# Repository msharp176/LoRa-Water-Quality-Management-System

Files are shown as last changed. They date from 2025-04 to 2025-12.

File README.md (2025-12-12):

# LoRa Water Quality Management System
### By Cole Hadley, Patricio Benitez Palermo, and Matthew Sharp
#### Penn State Harrisburg Senior Electrical Engineering Capstone Design Course, Fall 2025

# Project Repository Overview

This repository contains all hardware, firmware, software, and documentation associated with the gateway, sensor node, and supporting prototypes used throughout this project. The directory structure is organized to clearly separate production-ready components from prototyping artifacts, while providing comprehensive traceability for PCB designs, firmware, simulations, and supporting tools.

## Directory Structure

### **Gateway**

Code and PCB designs for the system gateway.

* **Dashboard**
  Python code for the gateway dashboard and system monitoring utilities.

* **LoRa Receiver**
  PCB design files, RP2350 firmware, and a console-logging Python script for a dedicated LoRa receiver module.

* **Neural Network**
  Code and related resources for the neural network implementation used in the system.

---

### **Prototyping and Testing**

Various PCB designs and test code used during early prototyping and validation phases.

---

### **Sensor Node**

Master directory for the final Sensor Node design, including PCB files, firmware, documentation, and test artifacts.

#### **Code**

Production firmware implementation for the Sensor Node.

* **Bin**
  Final binary executable for the RP2350 microcontroller (`.uf2`).

* **Lib**
  Custom-implemented C drivers for the sensor node.

  * **sx126x**: Semtech-provided driver files with custom HAL and radio ISR implementations.

* **Stash**
  Top-level gateway/node firmware source files. These are not included in the build unless a file is manually integrated into `main.c`.

* **Sys_Utils**
  Abstracted system-level modules, including LoRa communications, RDT3.0 implementation, and other project-specific utilities.

* **Tests**
  Code used to validate custom drivers and subsystem behaviors.

#### **Docs**

Datasheets, PCB design write-ups, and annotated Bill-of-Materials (BOM) for the final Sensor Node PCB.

#### **PCB Layout**

Complete KiCAD implementation of the sensor node PCB.

#### **Simulation**

Simulation files and output results for the analyses performed during development.

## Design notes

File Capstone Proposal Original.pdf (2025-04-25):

i

LoRa Water Quality Management System

Cole Hadley, Patricio Palermo, Matthew Sharp

Instructor: Dr. Kiana Karami

Technical Advisors: Dr. Sedig Agili and Dr. Aldo Morales

Technical Report Submitted in Partial Fulfillment of the Senior Electrical Capstone

Proposal Course at Penn State Harrisburg

EE 405, Section 1

Spring Semester, 2025

Submitted April 25, 2025

ii

Abstract

To provide high-quality water to their customers, water utility companies must continuously monitor several factors which contribute to the overall health, safety, and taste of drinking water. In this paper, a proposal for a water quality management system which leverages wireless communication technology to produce a distributed network of low-power, battery-operated sensors is presented. The network of sensors communicates real-time turbidity, pH, and temperature data to a central gateway, which identifies anomalous readings and makes predictions about the future water quality of the system using an artificial neural network. The central gateway also relays incoming water quality data to a visual dashboard, providing technicians and engineers with valuable water quality data at a glance.

Communication between the network of sensor nodes and central gateway is facilitated by LoRa wireless technology, whose name is derived from “long range.” LoRa has significantly reduced power consumption compared to traditional wireless technologies, such as cellular, therefore making it well-suited for long-distance, low bandwidth data communication applications such as water quality monitoring.

iii

Acknowledgements

We extend our gratitude to our capstone project technical advisors, Dr. Aldo Morales and Dr. Sedig Agili for contributing their expertise to our project. Both of our advisors were crucial for the development and exploration of sensor interfacing, wireless communication, and artificial neural networks. Additionally, we would like to thank Dr. Yen-Chih Chen and
J. Mitchell Spear for their consultation on the water treatment process and helping us understand how water quality is measured in the context of a water utility company. Furthermore, we would like to recognize the technicians and engineers of the Reading, Muhlenberg, and Maiden Creek water authorities for taking the time to complete our survey, helping us better understand the challenges that water utilities face when evaluating water quality. Finally, we would like to thank Dr. Kiana Karami for her valuable feedback and guidance during the proposal phase of the senior electrical engineering capstone course.

iv

Table of Contents

v

vi

Table of Figures

Figure 3: Block Diagram of Proposed LoRa-Based Water Quality Monitoring System [16]....9

Figure 13: Work Breakdown Structure for the LoRa Water Quality Management System .. 36

vii

Table of Tables

Table 1: Customer Primary Requirements | 15
Table 2: System Capabilities Subcategory Breakdown | 15
Table 3: System Feedback & Notifications Subcategory Breakdown | 16
Table 4: Ease of Use Subcategory Breakdown | 16
Table 5: Deployment Flexibility Subcategory Breakdown | 17

Table 6: Approved Methodologies and Relevant Standards for pH and Turbidity Analysis.19

Table 7: Engineering Requirements for the LoRa Water Quality Management System ........ 20

Table 8: pH Sensor Function Table | 26
Table 9: Turbidity Sensor Function Table | 26
Table 10: Temperature Sensor Function Table | 26
Table 11: Raw Data Formatting and Preprocessing Function Table | 27
Table 12: Data Collection Wireless Transceiver Function Table | 27
Table 13: Data Processing Wireless Transceiver Function Table | 28
Table 14: Final Data Processing Function Table | 28
Table 15: Anomaly Detection Function Table | 28
Table 16: Predictive Neural Network Function Table | 29
Table 17: Decision-making Logic Function Table | 29
Table 18: Dashboard Generation Function Table | 30
Table 19: Alert Generation Function Table | 30
Table 20: Gantt Chart | 38
Table 21: Engineering Labor Cost of Project | 39
Table 22: Parts Cost of Project | 40
Table 23: Total Cost of Project | 40

Table of Equations

Equation 1: Water Quality Index (WQI) | 11
Equation 2: Turbidity Sensor Output Voltage | 31
Equation 3: Instrumentation Amplifier Output Voltage | 32

1. Introduction
1.1. Introduction

To consistently deliver high-quality water to their customers, water utilities must monitor

the quality of their water in every part of their system. This often requires labor-intensive

manual testing, or sensors which provide this data in real-time. These systems often

require a direct wired connection between each sensor and a Programmable Logic

Controller (PLC), making retrofitting older plants with them more difficult. Though

wireless options for these sensors are available, they communicate over cellular networks,

requiring substantial power dissipation thus limiting battery life. Using LoRa, a wireless

communication technology whose name is derived from “Long Range,” water quality

sensors can be implemented with a significantly reduced power consumption and

communicate over long distances without needing access to cellular signal. Our LoRa-based

Water Quality Management System will implement a network of sensors which

communicate real-time water quality data back to a central gateway. The gateway will

integrate this data with AI-driven analytics, and relay system-wide information to

technicians and engineers through a visual dashboard and real-time alerts, enabling water

authorities to gain valuable insights into the status of their water systems with reduced

setup time and impact on legacy operations.

1.2. Technical History

Monitoring water quality has evolved from simple manual sampling methods to more

polished, real-time, and automated technology. This is a result of the increased need for

accurate, efficient, and comprehensive water quality analysis to ensure the safety of public

health and the environment. As demand for clean water increases due to population

growth, industrialization, and climate change, the need for innovation in water quality

monitoring systems has become more critical.

1.2.1. Early Developments in Water Quality Monitoring

The quality of water has been monitored since ancient history with the Greeks and Romans

using visual observation of clarity and building structures such as aqueducts to supply

clear water. The ancient cultures appreciated the value of clean water but were only able to

use primitive observation methods [1]. After Antonie van Leeuwenhoek discovered of the

microscope in the 17th century, scientists could now examine waterborne organisms for

the first time, paving the way for a better understanding of possible pollutants [2].

With the Industrial Revolution in the 19th century, there was a speeding up of

industrialization that resulted in serious water pollution, and hence the development of

chemical analysis techniques to measure pollutants like dissolved solids [3]. These

advances paved the way for more systematic water quality monitoring. By the mid-20th

century, techniques such as the Most Probable Number (MPN) method emerged, which

allowed for the estimation of bacterial populations by serial dilution and observation of

growth in culture tubes [4]. This was soon followed by the membrane filtration method,

which counted bacteria directly on filter membranes, increasing the efficiency and

precision of measurements of bacterial contamination [5].

1.2.2. Legislative Milestones: Clean Water Act and Safe Drinking Water Act

Two landmark legislations in the United States played a crucial role in strengthening water

quality monitoring. The Clean Water Act (CWA) of 1972 enacted broad-spectrum

regulations to avert water pollution, to safeguard the physical, chemical, and biological

integrity of the waters of the United States [6]. It required monitoring of industrial waste

and sewage treatment facilities while promoting the development of standard methods for

measuring water quality. CWA also focused on the restoration of polluted waters, which led

to the overall implementation of monitoring practices.

Similarly, the Safe Drinking Water Act of 1974 directly focused on drinking water quality,

mandating that water suppliers meet health-based standards for contaminants [7]. The act initiated more testing demands on the public water systems regarding microbial, chemical, and radiological parameters. Both acts together established a legislative climate in which

water quality monitoring became a regulated and organized endeavor in the United States.

1.2.3. Technological Advancements in the 1970s and 1980s

The 1970s and 1980s witnessed the use of advanced analytical instrumentation in water

quality analysis. The most notable development during this time was the release of the

computerized Gas Chromatography-Mass Spectrometry (GC/MS). This device enabled the

precise identification and quantification of organic pollutants in water samples, a major

leap in analysis [8]. The United States Environmental Protection Agency (EPA) implemented GC/MS as a standard analytical procedure in the determination of

environmental pollutants, and this saw more accurate and detailed water quality

determinations. The technology, apart from identifying pollutants more, also enabled the

setting of regulatory standards of water quality for the entire country.

During this time, the Supervisory Control and Data Acquisition (SCADA) system

deployment began to transform water quality monitoring. SCADA systems enable remote

monitoring and management of water treatment processes with real-time data acquisition

and process control [9]. SCADA systems enabled utilities to detect issues such as

equipment failures or contamination events more quickly, improving operational efficiency

and system reliability. Early SCADA systems often relied on wired connections for

communication, which were effective for centralized facilities but presented challenges in

monitoring widely distributed or remote locations. While these systems were capable of

remote monitoring, reliance on wired infrastructure could limit scalability and increase

costs. Over time, advancements in wireless communication technologies, such as radio,

cellular, and satellite networks, have significantly enhanced SCADA's ability to monitor and

control remote assets, reducing infrastructure costs and improving flexibility.

1.2.4. Emergence of Wireless Sensor Networks in the 1990s and 2000s

In the 1990s and early 2000s, the emergence of wireless sensor networks (WSNs) was a

groundbreaking environmental monitoring approach. WSNs are made up of widely

distributed sensors that wirelessly transmit data on various environmental factors,

including water quality. This made it ideal for tracking water quality in vast, remote areas

where traditional wired systems would be impractical and costly. [10]. These systems were

very effective for surveillance of large bodies of water, for instance, rivers, lakes, and

reservoirs, where older methods were not very practical.

1.2.5. Advancements in Low-Power, Long-Range Communication Technologies

Over the past few years, there has been an evolution of low-power, wide-area network

(LPWAN) technologies that have overcome most of the shortcomings of previous WSNs.

One such LPWAN technology is LoRa, which facilitates long-distance communication with

minimal power usage. LoRa technology is particularly well-suited for deploying sensor

networks in remote areas, allowing devices to operate efficiently on battery power. This

makes LoRa a cost-effective solution for monitoring water quality in areas with limited

access to traditional infrastructure.

The use of LoRa technology for water quality monitoring has simplified it to develop

affordable and scalable solutions. The technology can send data in real-time across vast

geographical areas without the need for heavy infrastructure, hence, why it is finding the

interest of water management authorities [11]. These are technologies that will improve

the measurement of water quality to augment post-treatment monitoring and confirm

water for safe consumption before intake. Figure 1 illustrates the architecture of a LoRa-

based water quality monitoring system.

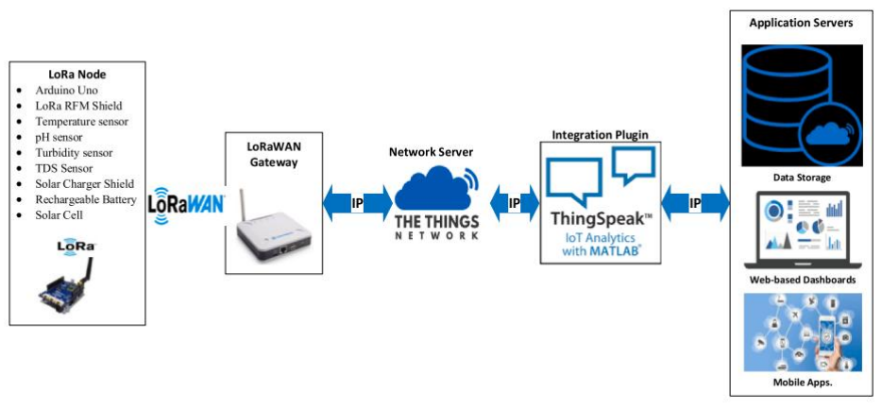
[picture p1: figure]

Figure 1: Example LoRa Water Quality Monitoring Architecture [11]

1.2.6. Current State and Gaps in Water Quality Monitoring

Today, water quality monitoring systems have become increasingly sophisticated,

incorporating Internet of Things (IoT) devices, advanced sensors, and real-time data

analytics. These systems can continuously monitor various parameters such as pH,

turbidity, dissolved oxygen, and the presence of specific contaminants [12]. Data collected

is transmitted to centralized platforms where it is analyzed to inform decision-making

processes. Moreover, AI-driven analytics are beginning to play a critical role in anomaly

detection and predictive maintenance, helping to identify issues before they escalate.

Despite these advancements, several gaps and challenges persist:

1. Integration with Legacy Systems: Many existing water treatment facilities operate

with legacy SCADA systems that rely on hard-wired connections. Integrating

modern wireless sensor networks with these systems can be complex and costly,

often requiring significant retrofitting. Overcoming this challenge requires

innovative solutions that ensure compatibility without extensive infrastructure

overhauls.

2. Power Efficiency: Many wireless communication methods, such as cellular, Wi-Fi,

and Bluetooth, consume a significant amount of power to maintain connectivity.

This high-power demand drastically reduces battery life, requiring frequent battery

replacements or consistent access to electrical infrastructure. In remote or off-grid

environments, these limitations can make long-term sensor deployment impractical.

For battery-powered or solar-powered systems, power efficiency is critical to

ensure sustained operation without constant maintenance.

3. Data Management and Analytics: Traditional SCADA systems often overwhelm

operators with large volumes of data, much of it lacking context or immediate relevance. Without clear interpretation, this data becomes difficult to act on and

offers little practical value. Effective systems should prioritize delivering focused,

actionable insights over raw data streams.

4. Ensuring Consistent Data Transmission: Existing technologies such as cellular and

Wi-Fi rely on network coverage, which can be unreliable or nonexistent in remote or

rural areas. This dependence limits their effectiveness for continuous monitoring in

hard-to-reach locations. For applications like water quality monitoring, where

consistent data transmission is critical, these coverage gaps pose a serious challenge

and can compromise real-time visibility and response.

5. Cost Constraints: Budget limitations, especially in smaller towns or developing

regions, can delay the adoption of advanced monitoring technologies. Addressing

this requires developing scalable solutions that balance performance with

affordability, enabling broader access to clean water monitoring.

Water quality monitoring has evolved from basic visual inspections to advanced real-time

systems, driven by the need for accuracy and efficiency. Innovations like SCADA, wireless

sensor networks, and LoRa technology have improved monitoring capabilities, enabling

cost-effective and scalable solutions. However, challenges remain in integrating modern systems with legacy infrastructure, managing data, ensuring power efficiency, and

addressing cost constraints. Continued advancements and collaboration are essential to overcoming these barriers and ensuring reliable, real-time water quality monitoring for the

future.

1.3. Review of Technical Literature
1.3.1. IoT in Modern Water Utilities

IoT-based water management systems have become ubiquitous in modern water utilities,

primarily with the advent of smart metering. These devices communicate real-time

individual usage data back to utility-owned software, where that data can be used for

applications such as billing or usage monitoring system-wide. One such IoT device, the

Honeywell Merlin NB-IoT, is shown below in Fig. 1.

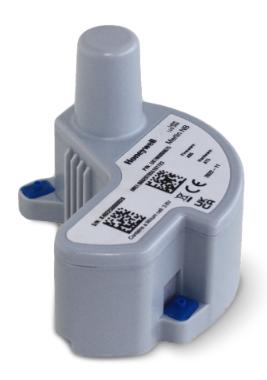
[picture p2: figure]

Figure 2: Honeywell Merlin NB-IoT Clip-On Water Meter [13]

This Honeywell IoT Device clips onto existing water meters and transmits real-time water

usage data over Narrowband IoT (NB-IoT), a subset of low power wide-area networks

(LPWAN) that utilizes existing 3G and 4G cellular infrastructure and frequency bands [13],

[14]. Using a low-power communication technology such as NB-IoT allows this device to have a battery life of up to 15 years, making it advantageous over traditional cellular

communications, which is quite power-hungry [13], [15].

1.3.2. Applications of LoRa in IoT Water Systems

The low power consumption advantages of NB-IoT systems can also be found in LoRa-

based communications systems. Compared to the NB-IoT communication technology used

in the Honeywell Clip-On NB-IoT smart meter, LoRa technology enables IoT

communications at an even lower power consumption. A typical NB-IoT node has a peak

current draw of 100-320 mA and a sleep current of 5μA, while a comparable LoRa node has a peak current and sleep current of 32mA and 1μA, respectively. LoRa obtains these

increased power savings at the cost of a significantly reduced data rate, with a maximum

speed of just 20% of an NB-IoT-based system, although with a much higher immunity to

interference [14].

Thus, the power-saving capabilities of LoRa are quite attractive for use in IoT applications

where battery life is of greater concern than the data rate, such as in water quality

monitoring applications. One such LoRa-based water quality monitoring system was

proposed during the 3rd International Conference on Advancement in Electronics and

Communication Engineering in 2023 [16]. The system utilizes a series of sensor nodes that

communicate with a central gateway which processes the raw data and communicates with

an external microcontroller unit to upload the information to an IoT cloud server over Wi-

Fi. A block diagram of the system is shown below in Fig. 2.

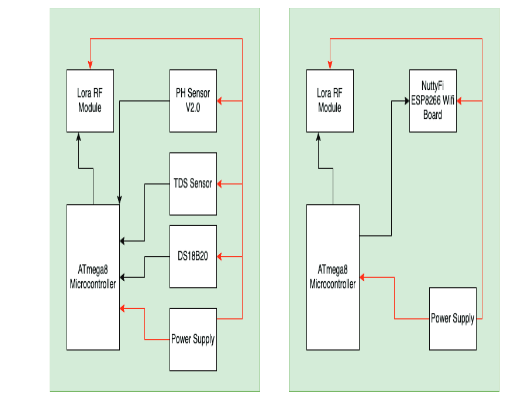
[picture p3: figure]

Figure 3: Block Diagram of Proposed LoRa-Based Water Quality Monitoring System [16].

Though this system provides a promising proof-of-concept solution for a LoRa-based water

quality management system, the proposed sensor nodes do not support several key metrics

of concern for water utility companies, such as turbidity, total suspended solids, or

contaminant levels. Furthermore, the system described in the conference paper has not

been implemented beyond the prototyping phase, and the raw data is not appreciably

processed or analyzed by any software tools, requiring constant human monitoring of the

data to identify anomalies or issues in the system. Finally, the system’s use of an ATmega8

microcontroller unit in addition to an ESP8266 development board in the gateway adds

unnecessary redundancy and failure points to the system, and reduces the overall power

savings of the system [16].

1.3.3. Wireless Water Quality Monitoring

Traditional water quality monitoring systems, such as those produced by In-Situ, report

real-time data over traditional cellular networks, requiring increased power consumption

and therefore larger battery capacity to reach an industry-acceptable battery life. The In-

Situ VuLink wireless probe adapter requires three D-cell Lithium Ion Manganese Oxide

batteries for a total capacity of 39,000 mAh, to achieve a battery life of up to 12 years with data reporting only once every 24 hours. Using a traditional Alkaline formulation reduces

this battery life to three years at the same reporting interval [17]. The VuLink wireless

probe adapter is designed to work with a multiparameter sonde, which supports

measurements such as temperature, conductivity, pH, turbidity, chloride concentration,

nitrate levels, and contaminant concentration [18]. Fig. 3 shows a picture of this system,

where the Aqua TROLL Multiparameter Sonde is on the left, and the VuLink Wireless Probe

Adapter is on the right.

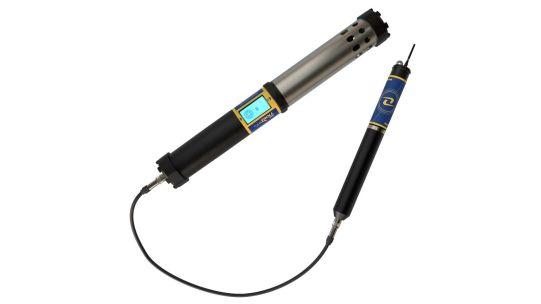
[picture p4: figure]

Figure 4: In-Situ Real-Time Water Quality Monitoring System [18].

In the absence of the wireless probe adapter, the multiparameter sonde can write data to

an RS485, Modbus, SDI-12, or Bluetooth output, enabling integration with existing PLC

infrastructure. Additionally, the multiparameter probe can be powered by an external DC

input, meaning battery life is not a concern for permanent applications where power

accessibility is not a concern [6].

1.3.4. Usage of Artificial Neural Networks in Water Quality Management

Though there are several commercially available water quality sensors capable of

providing real-time data on a variety of metrics, the raw telemetry provided by these

sensors still needs to be manually reviewed and monitored by a human to determine where

issues or anomalies may arise within the water system. Thus, one significant area for

improvement with these sensors is the integration of artificial intelligence and artificial neural networks (ANNs) with this raw data, meaning anomalies and issues with the system

can be detected outside of a simple check of the incoming data against some pre-set

threshold. A potential implementation of neural networks in the prediction of water quality

index was proposed in a 2023 paper by Murivhami, Tartibu, and Olayode [19], in which

previously-obtained water quality data on seven key metrics was used to train an ANN. The

ANN was then used to predict the future water quality index of the system, which was

computed using a weighted average calculation shown below in Equation 1.

Equation 1: Water Quality Index (WQI)

WQI =

∑ qi × wi

N
i
∑ wi

N
i=1

Once trained, the ANN was able to predict the water quality of the system with a typical

deviation of less than 1%. Using an ANN to predict future water quality metrics based on

real-time data allows water utility companies to adjust equipment and take corrective

action on their systems before problems arise, ensuring continuous high-quality water

delivery to their customers. Additionally, the forecasted data can be used to create

advanced warning systems and execute remedial actions.

1.4. Lifecycle of Similar Products

The lifecycle for an electronic product can be portrayed with the following four stages:

Development, Growth, Maturity, and Decline. The development stage includes the design

and manufacturing of the product. In the growth stage, the product is introduced to the

market and there is an increasing demand for the product. It includes the distribution,

operation and maintenance of the product [20]. The product reaches maturity when sales

reach their peak, manufacturing begins to be phased out and replaced by improved

products, and maintenance stops being offered. Finally, the decline or end stage occurs

when the product is no longer manufactured and the remaining products in the field are

replaced, until there are no products in operation, making the end-of-life of the product.

The design and manufacturing stage time depend on the complexity of the electronic

product. A similar product to our LoRa Water Quality Monitoring System is the TX3100

Wireless Transmitter from Sensorex, which replaces the TX3000. It measures pH and

Oxidation-Reduction Potential (ORP) and transmits data wirelessly [21]. The TX3100 to

have been introduced around 2018 [22], while the TX3000 appears to have been

introduced before 2012 [23]. This gives the product a lifecycle, from design to end-of-life,

of about 10 years, with an additional estimated 10 years of decline, before the products in

operation are replaced. This gives a total life cycle of about 20 years for water quality

monitoring products similar to our LoRa Water Quality Monitoring System. The figure

below shows an estimated time for each of the four stages. In reality, the decline and

maturity of an older product and the development of a newer product happen

simultaneously, thus the time from introduction of an older product to a newer product is

less than the whole lifecycle of a product.

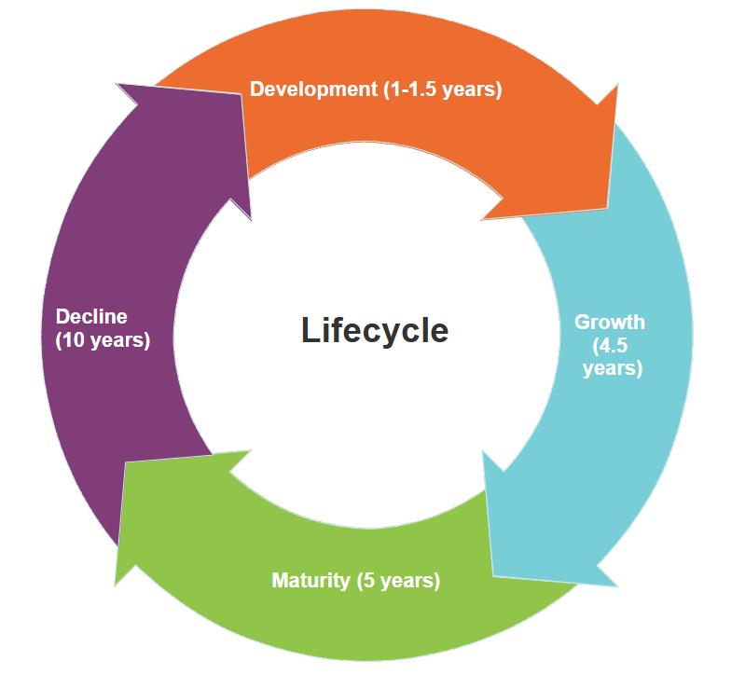
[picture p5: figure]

Figure 5: Estimated lifecycle of LoRa Water Quality Monitoring System

2. Experimental Method
2.1. Engineering Requirements Development
2.1.1. Customer Requirements

The marketing requirements for this project were established based on data collected from

a survey distributed to three water authorities, resulting in a total of seven responses from

water quality technicians. The survey itself can be found in Appendix A. Additionally, Dr.

Yen-Chih Chen, an associate professor of environmental engineering at Penn State

Harrisburg, provided expert insights on water quality treatment and industry standards.

Survey results were analyzed by calculating averages and creating graphs to better

understand the key requirements for this project. These findings are summarized in

Appendix B. Respondents expressed strong interest in a wireless, battery-powered design.

Notably, chlorine monitoring was rated as the highest priority. However, due to budget

limitations and sensor availability, a chlorine sensor could not be obtained. As a result,

turbidity and pH were selected as the two most important parameters to monitor.

Based on the data collected, four primary marketing requirements were identified: system

capabilities, system feedback & notifications, ease of use, and deployment flexibility. The

weights assigned to these categories, based on their importance, are shown in Table 1. The

highest priority requirement is system capabilities, as it defines the core functions of the

product, forming the foundation upon which all other features depend. The second most

critical requirement is system feedback & notifications, as survey results indicated that

technicians require 24/7 visibility into water quality levels. Following this, deployment

flexibility was ranked as the third priority, with technicians expressing interest in a

versatile, battery-powered solution that offers long operational life. Finally, while ease of

use remains important, it was determined to have the lowest relative priority, as it was

considered less critical than the other primary requirements.

Table 1: Customer Primary Requirements
Category | System Capabilities | System Feedback & Notifications | Ease of Use | Deployment Flexibility | Total | Weight
System Capabilities | 1 | 4/3 | 4/1 | 2/1 | 8.33 | 0.41
System Feedback & Notifications | 3/4 | 1 | 3/1 | 3/2 | 6.25 | 0.31
Ease of Use | 1/4 | 1/3 | 1 | 1 | 2.58 | 0.13
Deployment Flexibility | 1/2 | 2/3 | 1 | 1 | 3.17 | 0.16
| | | | Total | 20.33 | 1.00

The system capabilities category consists of the following subcategories: turbidity

monitoring, pH monitoring, wireless communication, AI analytics & predictions, and PLC

integration, as displayed in Table 2. Given that the primary function of the product is water

quality monitoring, turbidity and pH sensing were identified as the highest-priority

features. Turbidity monitoring was ranked the most critical, as it serves as a federally

recognized standard for determining water quality. Following this, wireless

communication ranked as the next priority, with survey results demonstrating strong

technician interest in long-range wireless communication, such as LoRa, that does not rely

on Wi-Fi or cellular networks. The lowest-priority subcategories were PLC integration and

AI analytics, with technicians showing minimal interest in AI-driven predictions, making it

the least essential function of the system.

Table 2: System Capabilities Subcategory Breakdown
System Capabilities | Turbidity Monitoring | pH Monitoring | Wireless Communication | AI Analytics & Predictions | PLC Integration | Total | Weight
Turbidity Monitoring | 1 | 5/4 | 5/3 | 5 | 5/2 | 11.42 | 0.34
pH Monitoring | 4/5 | 1 | 4/3 | 4 | 2 | 9.13 | 0.27
Wireless Communication | 3/5 | 3/4 | 1 | 3 | 3/2 | 6.85 | 0.20
AI Analytics & Predictions | 1/5 | 1/4 | 1/3 | 1 | 1 | 2.78 | 0.08
PLC Integration | 2/5 | 1/2 | 2/3 | 1 | 1 | 3.57 | 0.11
| | | | | Total | 33.75 | 1.00

The system feedback & notifications category is composed of dashboard display, alerts, and

battery life indicator, as shown in Table 3. Among these, dashboard display was ranked as

the highest priority, followed by alerts. These features are essential to technicians'

workflow, as they must be able to visually assess water quality levels in real time and

receive instant alerts if readings fall below critical thresholds. The battery life indicator was

deemed the lowest priority, as it is not a strong need for the feature.

Table 3: System Feedback & Notifications Subcategory Breakdown
System Feedback & Notifications | Dashboard Display | Alerts | Battery Life Indicator | Total | Weight
Dashboard Display | 1 | 5/4 | 3 | 5.25 | 0.48
Alerts | 4/5 | 1/1 | 2 | 3.80 | 0.35
Battery Life Indicator | 1/3 | 1/2 | 1 | 1.83 | 0.17
| | | Total | 10.88 | 1.00

The ease of use category includes low maintenance, user interface clarity, and field

replaceable components, as presented in Table 4. Technicians expressed a strong

preference for a low-maintenance product, making low maintenance the highest priority.

Closely related to this, field replaceable components, including easily swappable batteries

and sensors, were also deemed essential for reducing downtime and simplifying

maintenance. User interface clarity, while still relevant, was ranked as the lowest priority in

this category.

Table 4: Ease of Use Subcategory Breakdown
Ease of Use | Field Replaceable Components | User Interface Clarity | Low Maintenance | Total | Weight
Low Maintenance | 1 | 8/5 | 4/3 | 3.93 | 0.42
User Interface Clarity | 5/8 | 1 | 2/3 | 2.29 | 0.24
Field Replaceable Components | 3/4 | 3/2 | 1 | 3.25 | 0.34
| | | Total | 9.48 | 1.00

The deployment flexibility category includes long battery life, scalability for expansion, and

environmental durability, as shown in Table 5. Survey results indicated that technicians

prefer a battery-powered product, with a desired operational lifespan of at least one to

three years before requiring battery replacement. Resulting in long battery life being

ranked as the highest priority. Scalability for expansion, allowing for the addition of future

sensors, was identified as the second priority. Environmental durability was ranked as the

lowest priority, as the product will most likely be placed indoors, reducing the need for

extreme weather resistance.

Table 5: Deployment Flexibility Subcategory Breakdown
Deployment Flexibility | Long Battery Life | Scalability for Expansion | Environmental Durability | Total | Weight
Long Battery Life | 1 | 3/2 | 3 | 5.50 | 0.50
Scalability for Expansion | 2/3 | 1 | 2 | 3.67 | 0.33
Environmental Durability | 1/3 | 1/2 | 1 | 1.83 | 0.17
| | | Total | 11.00 | 1.00

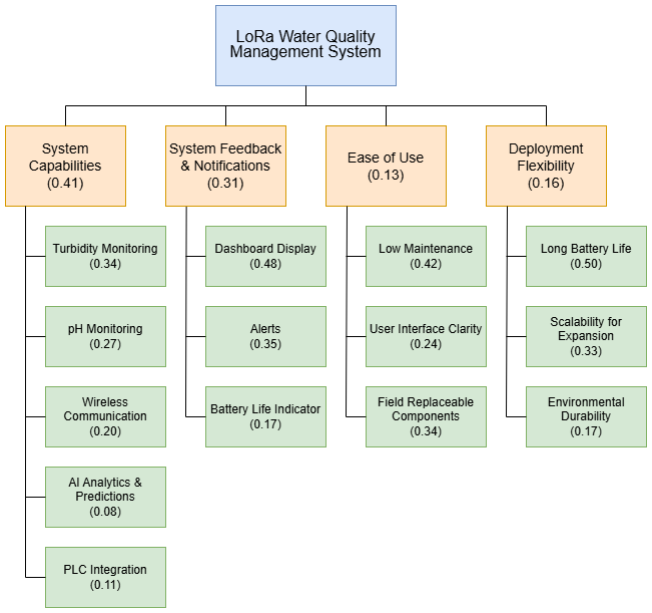
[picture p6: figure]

Figure 6: Hierarchical Representation of Marketing Requirements

2.1.2. Constraints

The design of the LoRa Water Quality Management System must meet several key

constraints to ensure regulatory compliance, efficient operation, and seamless integration

with existing infrastructure. These constraints define the boundaries for the design

decision of the system. When defining design constraints, we consider ideal user

experience, reliability, and regulatory compliance. Below is a list of constraints that are

vital to the operation and functionality of the technology:

- 15 weeks to define the project (this semester), followed by another 15 weeks to finish the design and build the project (next semester), as required by the EE 405 course.
- Completely designing one of the subsystems, as required by the EE 405 course.

- Budget of 500 USD with option of additional funding from sponsors, as provided by the EE 405 course.
- US915 902–928 MHz radio frequency bands used by LoRa, as required by Title 47 CFR Part 15.
- Water ingress protection for encasing electrical equipment exposed to water.
- Battery operated sensor nodes.
2.1.3. Standards

Public water systems must adhere to strict regulatory standards to ensure the safety and quality of drinking water. The Environmental Protection Agency (EPA) has established the National Primary Drinking Water Regulations, commonly referred to as the primary standard, which set these regulatory guidelines. The primary standard specifies the approved methodologies for conducting pH and turbidity analysis. The permitted methodologies for these analyses and their relevant standards are outlined in Table 1 [24] Additionally, the state of Pennsylvania has a MCL for turbidity that supersedes the EPA MCL standard. It requires that, the turbidity not exceed 0.3 NTUs in 95% of the monthly samples for public water systems with conventional or direct filtration, 1.0 NTUs for slow sand filtration or diatomaceous earth, and 0.15 NTUs for membrane filtration [25].
Table 6: Approved Methodologies and Relevant Standards for pH and Turbidity Analysis.
Contaminant | Methodology | EPA Standard | ASTM Standard | SM (18th, 19th ed.) | SM (20th ed.) | SM Online
pH | Electrometric | 150.1, 150.2¹ | D1293-95, 99 | 4500-H⁺ B | 4500-H⁺ B | 4500-H⁺ B-00
Turbidity | Nephelometric Method | 180.1 | - | 2130 B | - | -

In addition to the primary standard, the EPA has established the National Secondary

Drinking Water Standards, which define Secondary Maximum Contaminant Levels

(SMCLs). These secondary standards are non-mandatory but help ensure better color,

odor, and taste of drinking water. Specifically, the secondary standards recommend

maintaining a pH range between 6.5 and 8.5 [26].

Furthermore, the standard establishes record maintenance requirements. Turbidity

analysis records must be retained for at least five years. Additionally, specific data must be collected and documented, including the date, location, and time of sampling, along with

the analysis results [24].

Other standards that apply due to the use of LoRa are: the Code of Federal Regulations

(CFR) Title 47 Part 15, which governs operation within the 902-928 MHz, 2400-2483.5

MHz, and 5725-5850 MHz frequency bands [27]; IEEE Std 802.15.4, which specifies

requirements for low-data-rate wireless connectivity with devices with no or very limited

battery consumption [28; IEEE Std 1528.7, which provides a methodology for classifying

IoT devices based on radio frequency (RF) exposure [29]; and TS001-1.0.4, which specifies

the LoRaWAN network protocol for connecting devices to the internet using LoRa [30].

The ANSI/IEC 60529 standard also applies, as electrical equipment may be exposed to

water. It defines a classification system for the degree of protection provided by electrical

enclosures against water and solid particles [31].

2.2. Engineering Requirements

The engineering requirements for the LoRa Water Quality Management System were

developed from the customer requirements, constraints, and standards found in previous

sections of this proposal. The engineering requirements for the project are listed in Table 1

below. Each row of the center column of the table lists one of the engineering

requirements, with the corresponding marketing requirements denoted in the left column,

and a justification in the right column.

Table 7: Engineering Requirements for the LoRa Water Quality Management System

Marketing

Requirements

Engineering

Requirements

Justification

9, 11, 23 | Uses internal, readily
| commercially available
| batter(ies) to produce
| 3.3V ±0.3V DC input
| power.

An internal battery should be used for water

resistance, and to make the battery easily

replaceable in the field, it should be one easily

obtained commercially, (i.e. AA or D cell instead

of a custom Li-ion battery). A 3.3V level is

| | chosen because of its compatibility with a wide range of microcontrollers and sensor equipment, with some tolerance to allow some small battery voltage deviations.
3, 12, 13, 16, 17, 18, 22 | Should utilize a wireless communication technology with a transmit current consumption of under 150mA, and under 5mA idle current consumption, on the US915 (902-928 MHz) frequency band | Wireless communication that did not need access to cellular or Wi-Fi was a significant concern to technicians. To have a longer battery life, the chosen standard should have minimized power consumption. Additionally, the wireless technology chosen must operate within legally permissible frequencies (902-928 MHz in the United States and Canada)
1, 2, 15 | Each senor node must be capable of producing real-time pH data within ±0.3 of actual, and turbidity within 0.1NTU of actual under 1.0 NTU, at maximum 15 minute intervals. | These two metrics were the top concern for technicians, and are essential metrics for maintaining utility legal compliance. The specified tolerances , limits, and time interval for these measurements will keep the system consistent with Pennsylvania drinking water regulations.
4, 6, 7, 8, 10, 15 | System must be able to process data with backend software at minimum every 15 minutes, and alert technicians when either the turbidity or pH is within 15% of thresholds | Processing the real-time data and providing an overview of the system with some analytics assists technicians and engineers with making determinations regarding the water quality of the system. Processing this data every 15 minutes keeps the system consistent with Pennsylvania Regulations. To help utilities maintain compliance, the system should alert

| set by Pennsylvania, which are 1.0 NTU and between 6.0-9.0, respectively, or those set by the Water Utility. | technicians when their water is within 15% of the Pennsylvania Turbidity and pH limits, which are 1.0 NTU maximum, and 6.0-9.0, respectively.
3, 5, 8, 9, 13, 14, 23 | System should be easily integrated with existing utility infrastructure, and minimize the impact on existing operations | Makes the system more desirable for utilities and more useful to technicians already familiar with existing PLC and SCADA systems. Wireless communication reduces the need for retrofitting, and reduces additional maintenance burdens.

Customer Requirements

1. Turbidity Monitoring [R]
2. pH Monitoring [R]
3. Wireless Communication [R]
4. AI Analytics & Predictions [D]
5. PLC Integration [D]
6. Dashboard Display [R]
7. Alerts [R]
8. Battery Life Indicator [D]
9. Low Maintenance [R]
10. User Interface Clarity [D]
11. Field Replaceable Components [D]
12. Long Battery Life [R]

13.Scalability for Expansion [R]

14. Environmental Durability [D]

Standards

15. Pennsylvania Code, Title 25, Chapter 109: Maximum Contaminant Level (MCL)
16. Code of Federal Regulations (CFR) Title 47, Part 15: Radio Frequency Devices
17. TS001-1.0.4: LoRaWAN Specification
18. IEEE 802.15.4: Low-Rate Wireless Personal Area Network (LR-WPAN)

Constraints

19. Must be Completed by December 2025
20. Must satisfy project requirements of the EE 406W capstone course.
21. Cost of project must not exceed $500 budget
22. Must use permissible wireless frequencies as defined by Federal Regulations
23. Water ingress protection for encasing electrical equipment exposed to water
2.3. Level 1 and 2 Functional Decomposition
2.3.1. Level 1 Decomposition

The level 1 decomposition of the LoRa Water Quality Management System is shown in

Figure 1 below. The system is comprised of four main functional blocks: Data Collection,

Data Processing, Controlling, and Alerting & Reporting. Power to the system is supplied by

an internal battery in each sensor node and is provided externally at the central gateway of

the system. Each sensor node has a direct connection to the water and outside environment

to take measurements. From there, the raw data is processed and analyzed to make

decisions about the overall health of the system. The processed data and analysis are then

reported to technicians and engineers through a water quality dashboard and alerts when

issues arise.

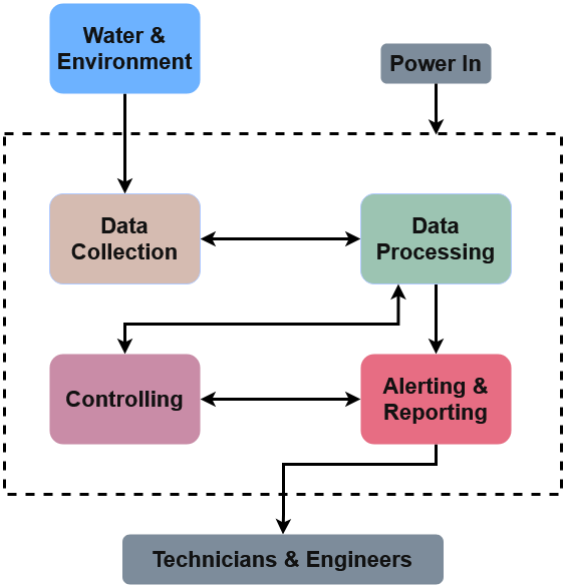
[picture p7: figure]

Figure 7: Level 1 Decomposition of the LoRa Water Quality Management System

2.3.2. Level 2 Decomposition

The level 2 decomposition of the LoRa Water Quality Management System is shown in

Figure 2 below. The overall design of the system is broken up into two distinct subsystems,

which are the sensor node and central gateway. These are connected via a wireless

communication link, shown with a dashed arrow between both wireless transceiver blocks.

Each sensor node, which is depicted in the left subsystem of the diagram, is responsible for collecting the raw data from the pH, turbidity, and temperature sensors, interpreting the

sensor output (e.g. analog voltage value) as a measurement, and formatting the data to be

sent to the central gateway over the wireless communication link. Once the interpreted and

formatted data is received by the central gateway, it is further formatted so that it can be

analyzed through an Artificial Neural Network, compared against thresholds, and be

reported to an external dashboard to be used by Technicians and Engineers. Based on the

analyzed data output, decision making logic is used to raise alerts to notify technicians and

engineers of issues in the system, or post warnings and other valuable information to the

system dashboard.

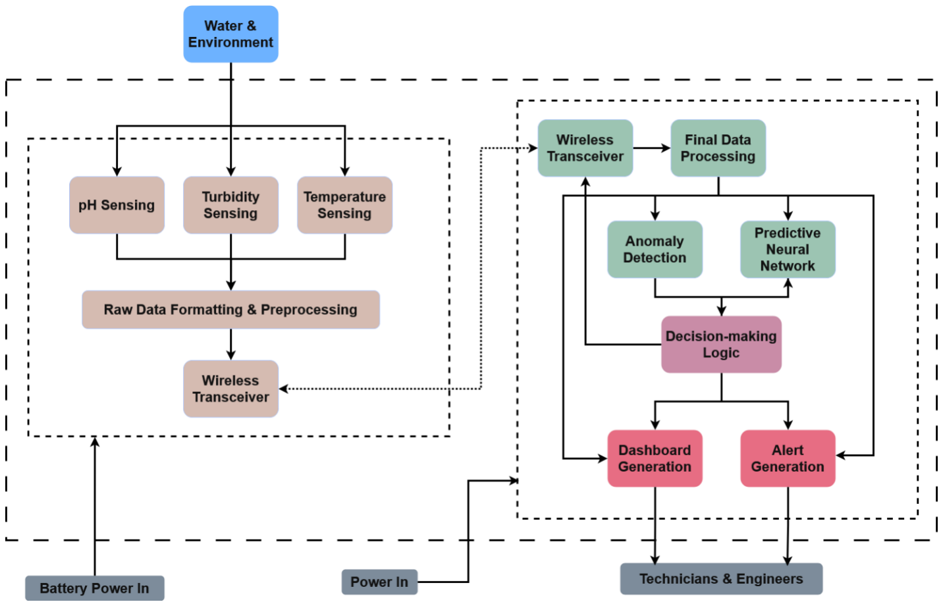
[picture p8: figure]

Figure 8: Level 2 Decomposition of the LoRa Water Quality Management System

Table 8: pH Sensor Function Table

Module | pH Sensor
Inputs | • Raw water sample pH
Outputs | • Analog voltage corresponding to the pH of the water
Functionality | • Converts the pH of the water to an analog voltage value interpretable by a microcontroller

Table 9: Turbidity Sensor Function Table

Module | Turbidity Sensor
Inputs | • Raw water sample Turbidity
Outputs | • Analog voltage corresponding to the Turbidity of the water
Functionality | • Converts the Turbidity of the water to an analog voltage value interpretable by a microcontroller

Table 10: Temperature Sensor Function Table

Module | Temperature Sensor
Inputs | • Raw water sample temperature
Outputs | • Analog voltage corresponding to the temperature of the water
Functionality | • Converts the temperature of the water to an analog voltage value interpretable by a microcontroller

Table 11: Raw Data Formatting and Preprocessing Function Table

Module | Raw Data Formatting and Preprocessing
Inputs | • Analog pH data • Analog turbidity data • Analog temperature data
Outputs | • Formatted digital data for the pH, turbidity, and temperature
Functionality | • Interprets the analog voltages produced by the sensors as digital data • Converts the digitized analog voltage readings to relevant measurement units for pH, turbidity, and temperature • Formats the data to be sent to the central gateway module

Table 12: Data Collection Wireless Transceiver Function Table

Module | Wireless Transceiver (Data Collection)
Inputs | • Formatted digital pH, turbidity, and temperature readings
Outputs | • Wireless signal to be sent to central gateway wireless transceiver
Functionality | • Broadcasts the formatted sensor data wirelessly to be read in by the central gateway

Table 13: Data Processing Wireless Transceiver Function Table

Module | Wireless Transceiver (Data Processing)
Inputs | • Wireless signal from sensor node containing formatted digitized sensor data • Inputs from decision making logic to mediate data transfer
Outputs | • Formatted, digitized sensor data ready for final processing • Acknowledge signal to sensor node transceiver indicating successful data transmission
Functionality | • Interprets the broadcasted wireless data into useable data for further data processing

Table 14: Final Data Processing Function Table

Module | Final Data Processing
Inputs | • Formatted, digitized sensor data originating from sensor nodes
Outputs | • A .CSV file containing updated sensor data from all nodes
Functionality | • Combines and formats data from all sensor nodes into a commonly used file type, which can be interpreted by the dashboard generation software, neural network, and anomaly detector

Table 15: Anomaly Detection Function Table

Module | Anomaly Detection
Inputs | • CSV data with updated sensor readings from all sensor nodes
Outputs | • A simplified report of anomalous sensor readings and readings outside the thresholds set by the utility and legal regulations
Functionality | • Looks through incoming sensor data to identify readings that are outside of legal compliance and compliance with utility specifications

Table 16: Predictive Neural Network Function Table

Module | Predictive Neural Network
Inputs | • CSV data with updated sensor readings from all sensor nodes • Signal to cause the neural net to begin running from decision-making logic
Outputs | • Predictions for future system water quality based on training data
Functionality | • Makes predictions for the overall health of the system based on incoming and past sensor data • Proactively identifies future water quality issues.

Table 17: Decision-making Logic Function Table

Module | Decision-making Logic
Inputs | • Anomalous sensor readings • Sensor readings outside legal or utility-set thresholds • System water quality predictions from Artificial Neural Network
Outputs | • Selected anomalous readings to report on the dashboard • Readings and predictions requiring attention from technicians and engineers • Wireless data reception mediation signals
Functionality | • Takes in all available system data and makes determinations on what requires attention from engineers and technicians, and the severity of system-wide issues

Table 18: Dashboard Generation Function Table

Module | Dashboard Generation
Inputs | • CSV data with updated sensor readings from all sensor nodes • Sensor readings and system water quality predictions of note as determined by decision-making logic
Outputs | • A visual display of current system-wide data, anomalous readings of note, and future system water quality predictions
Functionality | • Summarizes system-wide data in a visual format easily readable by technicians and engineers

Table 19: Alert Generation Function Table

Module | Alert Generation
Inputs | • Sensor readings falling outside legal or utility-set thresholds • Significant anomalous sensor readings • Water quality predictions of concern as determined by decision-making logic
Outputs | • Automated email sent to technicians and engineers of concern
Functionality | • Informs technicians and engineers immediately when issues arise in the system, or when issues are predicted to arise, so that proactive corrective action may be taken

2.4. Preliminary Simulation

As a part of the preliminary design process of the LoRa Water Quality Management System,

the functionality of the turbidity sensor pre-processing circuit was simulated using

LTSpice.

The purpose of this circuit is to condition the output of the turbidity sensor, which has a

nonlinear response to the measured turbidity value and has minimal voltage variation for

small changes in turbidity, making it difficult to reliably use with a traditional analog-to-

digital converter (ADC) and microcontroller. Using selected points on the response graph

of the datasheet of the chosen turbidity sensor, the Amphenol Sensors TSW-10 Turbidity

Sensor, the response curve was approximated using Microsoft Excel [32]. The response of

the sensor is given by Equation 2 below, where the independent variable, T, is the turbidity

of the water in NTU. A plot of this nonlinear response is shown in Figure 9.

Equation 2: Turbidity Sensor Output Voltage
v(T) = 0.0000005T

2 − 0.0018T + 3.6679

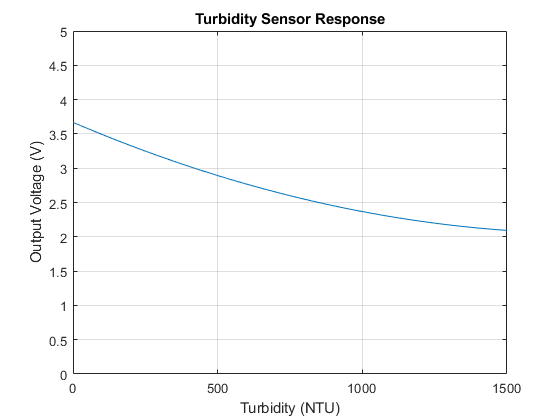
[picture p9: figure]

Figure 9: Turbidity Sensor Output Voltage Plot

To linearize and condition the output signal, the instrumentation amplifier circuit depicted

in Figure 10 below was designed and simulated in LTSpice. The output voltage of this

circuit is given by Equation 3.

Equation 3: Instrumentation Amplifier Output Voltage

Vout(t) = (Vref(t) − Vsensor(t)) (1 +

2 × R3
R2

) (

R8
R5

) , given R3 = R4, R5 = R6, and R7 = R8

This configuration of the instrumentation amplifier was chosen for its high input

impedance, easily adjustable gain, and differential operation. Since the gain of the entire

circuit can be adjusted by changing the value of R2, the gain of the circuit could be

calibrated by a microcontroller using a digitally controlled potentiometer in place of this

resistor. Since the output voltage of the amplifier is a multiple of the reference voltage

minus the sensor voltage, the output of the circuit is directly proportional to the turbidity

of the water instead of being inversely proportional, making the output voltage easily

interpretable by the microcontroller. Since the range of expected turbidity measurements

for the LoRa water quality management system is from 0 to approximately 5 NTU, a total

gain of 80 was chosen for the amplifier. As a result, the output of the amplifier saturates for

turbidity levels above approximately 20NTU, however the response of the amplifier

produces an appreciable voltage difference for changes in NTU within the desired range. A

Zener diode with a breakdown voltage of 3V was placed at the output to clip output

voltages which could be damaging to a 3.3V microcontroller.

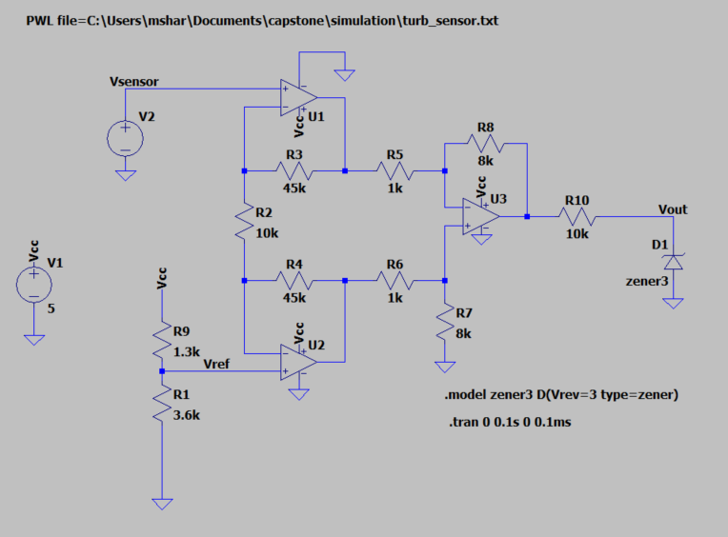
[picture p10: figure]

Figure 10: Instrumentation Amplifier Circuit as Simulated in LTSpice

To simulate the response of the circuit over the full range of sensor output values, the

output voltage function given in Equation 2 was modeled in a piecewise linear (PWL) file,

generated using the C code depicted in Figure 11. Using this code, a PWL file was produced

that made the simulated turbidity reading equal to the simulation time in milliseconds. The

LTSpice simulation output is shown in Figure 12. With this data, this instrumentation

amplifier circuit was shown in Microsoft Excel to linearize the sensor output within the

desired range with an R

2 value of 100%. Since the output of the sensor varies over a larger

range for the expected turbidity readings, the precise turbidity value can then be measured

more easily using a standard analog to digital converter.

#include <stdio.h>

#include <stdlib.h>

#include <math.h>

double turbiditySensor(int time_ms) {
return (0.0000005 * powf(time_ms, 2)) - (0.0018 * time_ms) + 3.6679;
}

int main(void) {

char * filename = "C:\\Users\\mshar\\Documents\\capstone\\simulation\\turb_sensor.txt";

FILE * fptr = fopen(filename, "w+");

if (fptr == NULL) {
printf("Failed to open %s!\n", filename);
return 0;
}

for (int k = 0; k <= 1500; k++) {
fprintf(fptr, "%dm %f", k, turbiditySensor(k)); if (k != 1500) {
fprintf(fptr, "\n");
}
}

fclose(fptr);

printf("Successfully wrote %s.\n", filename);

}

Figure 11: C Code Used to Model the Response of the Turbidity Sensor

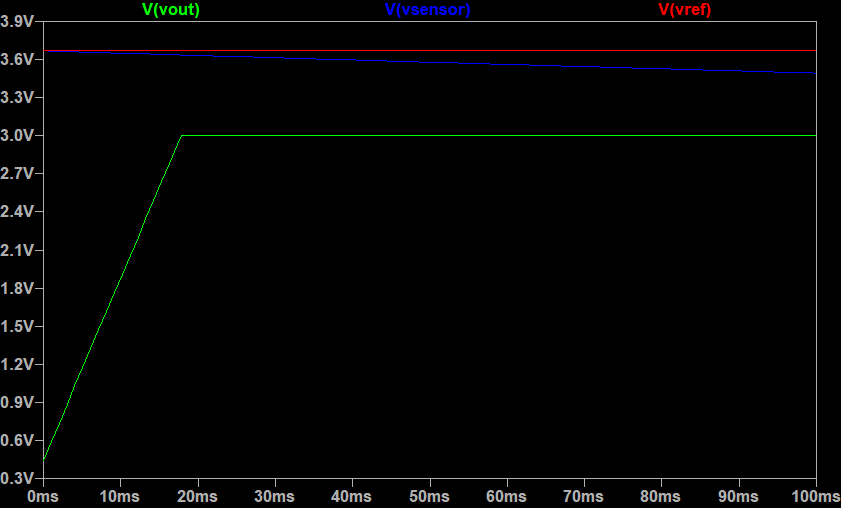
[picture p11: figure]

Figure 12: Instrumentation Amplifier Simulation Output, as produced in LTSpice

3. Project Management
3.1. Project Work Breakdown Structure (WBS)

Figure 13, shown on the following page, presents the work breakdown structure (WBS) for

the development of the LoRa Water Quality Management System. Based on the scope of the

project, five main tasks were outlined: research, design, fabrication, testing & validation,

and documentation. Based on the prior skills, experience, and areas of interest of each of

the team members, the tasks and subtasks were then assigned to distribute the overall

workload as fairly as possible. To make the scope of the overall project more feasible, PLC

integration was removed from the WBS as technicians viewed this feature less desirable

than other portions of the project.

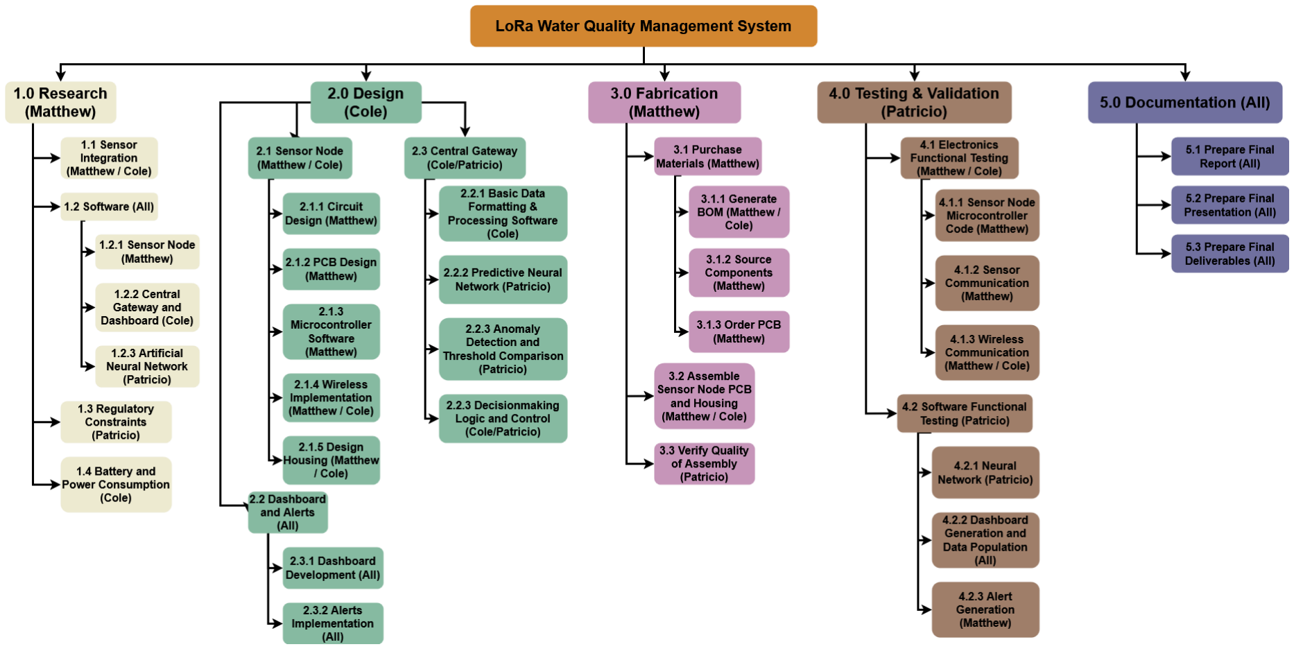
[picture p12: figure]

36

Figure 13: Work Breakdown Structure for the LoRa Water Quality Management System

3.2. Project Schedule (Gantt Chart)

Table 20, shown on the following page, presents a proposed schedule for completing the

development LoRa Water Quality Management System. This schedule includes the work

already completed for this project, including the project proposal and portions of the

research needed for the project design. We intend to complete work over the Summer

break, with expected work completion for the Capstone Design Conference at the end of the

Fall 2025 semester. The schedule includes some buffer times and extended project work

completion deadlines to ensure the project is completed in time for the Capstone Design

conference.

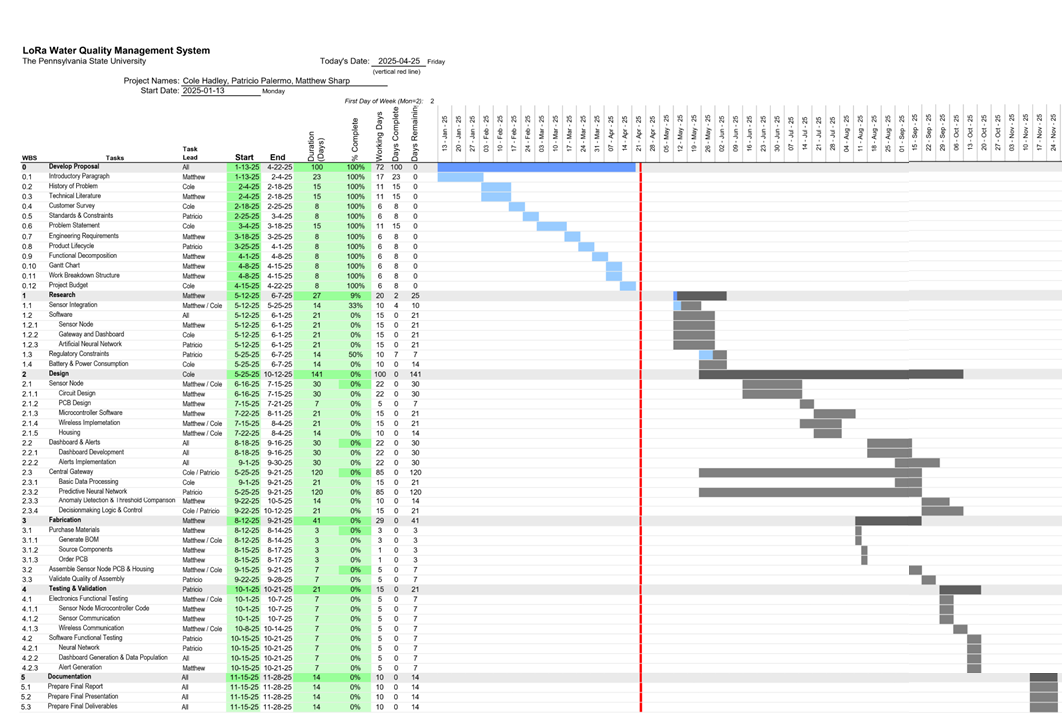
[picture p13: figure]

38

Table 20: Gantt Chart

3.3. Project Budget

The cost of labor was determined by using the Gantt chart and assuming two hours of labor

per allotted workweek of each task, based on the credit hours of the class. The sections of

the work breakdown structure were assigned to the labor hours as follows: The proposal

development and documentation sections were included as consulting hours; the

fabrication section was included as assembly hours; the design and research sections were

included as design hours; the testing and validation section were evenly split unto testing

and validation hours; finally, for the coding hours, each individual task that required

coding, such as the predictive neural network task, was included. The estimated unit cost for labor was obtained from the website Indeed and used to calculate the total labor cost

[33]. The total labor cost is $31,365.22, shown in Table 21.

Table 21: Engineering Labor Cost of Project.

Item | Unit | Unit Cost | # Units | Cost
Design | hr | 49.00 | 235 | $ 13,818.00
Coding | hr | 52.96 | 360 | $ 6,143.36
Assembly | hr | 20.06 | 17 | $ 409.22
Testing | hr | 25.54 | 15 | $ 459.72
Validation | hr | 25.54 | 15 | $ 459.72
Consulting | hr | 41.98 | 200 | $ 10,075.20
| | | Labor Subtotal | $ 31,365.22

The parts section was determined by analyzing the level 2 decomposition and determining

which parts will be needed to implement each function and sub-processes. The

miscellaneous parts at the end of Table 22 are estimated costs. The estimated cost for all

the parts is $414. Corresponding citations for each component are provided in the second

column of the table.

Table 22: Parts Cost of Project.

Item | Source | Unit | Unit Cost | # Units | Cost
Microcontroller | [34] | ea | 5.00 | 1 | $ 5.00
Single-Board Computer (SBC) | [35] | ea | 80.00 | 1 | $ 80.00
AI Accelerator for SBC | [36] | ea | 110.00 | 1 | $ 110.00
Wireless Transceiver | [37] | ea | 15.90 | 2 | $ 31.80
PCB | [38] | ea | 0.40 | 5 | $ 2.00
Water Temperature Sensor | [39] | ea | 7.50 | 1 | $ 7.50
pH Sensor | [40] | ea | 29.50 | 1 | $ 29.50
Turbidity Sensor | [41] | ea | 9.90 | 1 | $ 9.90
ADC Module | [42] | ea | 15.50 | 1 | $ 15.50
Batteries | [43] | ea | 1.51 | 8 | $ 12.08
Misc SBC Parts (microSD, Case, Power Cord) | | ea | 40.00 | 1 | $ 40.00
Misc Microcontroller Parts (Case, Program Cord) | | ea | 20.00 | 1 | $ 20.00
Misc PCB Parts (Resistors, Capacitors, OpAmp, Connectors, etc) | | ea | 50.00 | 1 | $ 50.00
| | | | Parts Subtotal | $ 413.28

In total, the project has an estimated cost of $31,778.50, shown in Table 23. Most of the cost

of the project is due to labor costs, in particular, design and coding, with parts cost being

minimal.

Table 23: Total Cost of Project

Categories | Cost
Labor Subtotal | $ 31,365.22
Parts Subtotal | $ 413.28
Grand Total | $ 31,778.50

4. Summary and Conclusion

As outlined in this proposal, the LoRa Water Quality Management system presents an

innovative solution to water utility companies for the monitoring and management of

drinking water quality. Unlike traditional water quality monitoring systems, which often

require labor-intensive manual water testing or sensors that must be hard-wired into

legacy SCADA-based systems, the LoRa Water Quality Management System makes use of

power-efficient LoRa wireless technology, whose name is derived from “Long Range,” to

transmit real-time water quality data back to a central gateway without the need for

cellular service, a WiFi connection, or a hard-wired data link. The data transmitted from a network of LoRa-based sensor nodes is processed at a central gateway, which aggregates

and summarizes system-wide water quality data in a visual dashboard, alerts technicians

and engineers when measured data exceeds legal or utility-defined thresholds, and utilizes

AI-driven analytics to predict future system water quality. Implementation of the LoRa

Water Quality Management System enables technicians and engineers to monitor water

quality system-wide and take corrective action before issues arise.

References

[1] A. N. Angelakis, N. Dercas, and V. A. Tzanakakis, “Water Quality Focusing on the Hellenic World: From Ancient to Modern Times and the Future,” Water, vol. 14, no. 12, p. 1887, Jun. 2022. doi:10.3390/w14121887
[2] The Editors of Encyclopedia Britannica, “Antonie van Leeuwenhoek,” Encyclopædia Britannica, https://www.britannica.com/biography/Antonie-van-Leeuwenhoek (accessed Feb. 17, 2025).
[3] J. Hassan, “The Victorian and Edwardian Periods,” in The History of Water in Modern England and Wales, New York, New York: Manchester University Press, 1998, pp. 10– 50
[4] J. L. Oblinger and J. A. Koburger, “Understanding and teaching the most probable number technique,” Journal of Milk and Food Technology, vol. 38, no. 9, pp. 540–545, 1975. doi: 10.4315/0022-2747-38.9.540.
[5] B. Forster and C. A. Pinedo, “Bacteriological examination of waters: membrane filtration protocol,” American Society for Microbiology, 2015.
[6] “History of the Clean Water Act,” EPA, https://www.epa.gov/laws-regulations/history-clean-water-act (accessed Feb. 17, 2025).
[7] “Overview of the Safe Drinking Water Act,” EPA, https://www.epa.gov/sdwa/overview-safe-drinking-water-act (accessed Feb. 17, 2025).
[8] S. D. Richardson, “Water analysis,” Analytical Chemistry, vol. 71, no. 12, pp. 181–216, May 1999. doi:10.1021/a19900060
[9] J. Collings, “A history of SCADA for the Water Sector,” Wastewater Digest, https://www.wwdmag.com/utility-management/article/10940688/a-history-of-scada-for-the-water-sector (accessed Feb. 17, 2025).
[10] G. A. López-Ramírez and A. Aragón-Zavala, "Wireless Sensor Networks for Water Quality Monitoring: A Comprehensive Review," in IEEE Access, vol. 11, pp. 95120-95142, 2023, doi: 10.1109/ACCESS.2023.3308905.
[11] W. A. Jabbar, T. M. Ting, M. F. I. Hamidun, A. H. C. Kamarudin, W. Wu, J. Sultan, A. A. Alsewari, and M. A. H. Ali, “Development of LoRaWAN-based IoT system for water quality monitoring in rural areas,” Expert Systems with Applications, vol. 242, p. 122862, 2024. doi: 10.1016/j.eswa.2023.122862.
[12] M. Miller et al., “IoT in Water Quality Monitoring-Are We Really Here?,” Sensors (Basel, Switzerland), vol. 23, no. 2, p. 960, Jan. 2023. doi: 10.3390/s23020960.

[13] Honeywell, “Merlin NB-IoT Clip-on LPWAN Communication Module,” Merlin NB-IoT datasheet, 2023.
[14] R. S. Sinha, Y. Wei, and S.-H. Hwang, “A survey on LPWA technology: Lora and Nb-IOT,” ICT Express, vol. 3, no. 1, pp. 14–21, Mar. 2017. doi:10.1016/j.icte.2017.03.004
[15] S. Devalal and A. Karthikeyan, "LoRa Technology - An Overview," 2018 Second International Conference on Electronics, Communication and Aerospace Technology (ICECA), Coimbatore, India, 2018, pp. 284-290, doi: 10.1109/ICECA.2018.8474715.
[16] P. K. Malik, P. Malik, G. R. Kumar, Sneha, R. Abraham and R. Singh, "Design and Implementation of a LoRa-Based Water Quality Monitoring System," 2023 3rd International Conference on Advancement in Electronics & Communication Engineering (AECE), GHAZIABAD, India, 2023, pp. 120-124, doi: 10.1109/AECE59614.2023.10428618.
[17] In-Situ, “VuLink Data Logger and Telemetry,” VuLink datasheet, 2024.
[18] In-Situ, “Aqua TROLL Multiparameter Sondes” Aqua TROLL datasheet, 2024.
[19] T. Murivhami, L. K. Tartibu and I. O. Olayode, "Applications of Artificial Neural
Network in the Prediction of Water Quality Index," 2023 14th International Conference on Mechanical and Intelligent Manufacturing Technologies (ICMIMT), Cape Town, South Africa, 2023, pp. 100-104, doi: 10.1109/ICMIMT59138.2023.10199388.
[20] M. Hayat and H. Winkler, "Exploring the Basic Features and Challenges of Traditional Product Lifecycle Management Systems," 2022 IEEE International Conference on Industrial Engineering and Engineering Management (IEEM), Kuala Lumpur, Malaysia, 2022, pp. 0762-0766, doi: 10.1109/IEEM55944.2022.9989978.
[21] TX3100 Intelligent pH/ORP Transmitter/Controller. Sensorex [Online].
Available: https://sensorex.com/product/new-tx3100-intelligent-ph-orp-transmitter-controller/ (https://sensorex.com/product/new-tx3100-intelligent-ph-orp-transmitter-controller/)
[22] CE TX3100 Technical Documentation. MJK Automation. [Online].
Available: https://mjk.se/wp-content/uploads/2022/02/ce_tx3100.pdf
[23] TX3100 pH/ORP Transmitter User Manual. Phuong Hai Technical Service & Trading Co. [Online]. Available: https://phuonghai.com/download/22635952.pdf
[24] Code of Federal Regulations, Title 40, Part 141, 2020. [Online]. Available: https://www.ecfr.gov/current/title-40/chapter-I/subchapter-D/part-141 (accessed Mar. 2, 2025)

[25] Pennsylvania Department of Environmental Protection, “Maximum Contaminant Levels, Maximum Residual Disinfectant Levels, and Treatment Technique Requirements,” GreenPort, Mar. 2024. [Online]. Available: https://greenport.pa.gov/elibrary//PDFProvider.ashx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 +MAXIMUM+RESIDUAL+DISINFECTANT+LEVELS%2C+AND+TREATMENT+TECHN IQUE+REQUIREMENTS. (Accessed: Apr. 24, 2025)
[26] Code of Federal Regulations, Title 40, Part 143, Subpart A, 2020. [Online]. Available: https://www.ecfr.gov/current/title-40/chapter-I/subchapter-D/part-143/subpart-A (accessed Mar. 2, 2025)
[27] Code of Federal Regulations, Title 47, Part 15. [Online]. Available: https://www.ecfr.gov/current/title-47/chapter-I/subchapter-A/part-15 (accessed Mar. 2, 2025)
[28] IEEE Standard for Low-Rate Wireless Networks, IEEE Standard 802.15.4, 2020. [Online]. Available: https://standards.ieee.org/standard/802_15_4-2020.html (accessed Mar. 2, 2025)
[29] IEEE Guide for EMF Exposure Assessment of Internet of Things (IoT) Technologies and Devices, IEEE Standard 1528.7, 2020. [Online]. Available: https://standards.ieee.org/ieee/1528.7/7306/ (accessed Mar. 2, 2025).
[30] LoRaWAN Link Layer Specification, LoRa Alliance Standard v1.0.4, Nov. 2021. [Online]. Available: https://lora-alliance.org/wp-content/uploads/2021/11/LoRaWAN-Link-Layer-Specification-v1.0.4.pdf (https://lora-alliance.org/wp-content/uploads/2021/11/LoRaWAN-Link-Layer-Specification-v1.0.4.pdf) (accessed Mar. 2, 2025).
[31] Degrees of Protection Provided by Enclosures (IP Code), ANSI/IEC 60529, 2020. [Online]. Available: https://www.nema.org/docs/default-source/about-us-document-library/ansi-iec_60529-2020-contents-and-scopef0908377-f8db-4395-8aaa-97331d276fef.pdf (https://www.nema.org/docs/default-source/about-us-document-library/ansi-iec_60529-2020-contents-and-scopef0908377-f8db-4395-8aaa-97331d276fef.pdf) (accessed Mar. 2, 2025).
[32] Amphenol Advanced Sensors, “TSW-10 Turbidity Sensor,” TSW-10 datasheet, Feb. 2024
[33] “Salaries”, Indeed. [Online]. Available: https://www.indeed.com/career/salaries?from=gnav-title-webapp. [Accessed: Apr. 21,2025]
[34] “Raspberry Pi Pico 2 SC1631,” DigiKey. [Online]. Available: https://www.digikey.com/en/products/detail/raspberry-pi/SC1631/24627136. [Accessed: Apr. 21,2025]

[35] “Raspberry Pi 5 SC1112,” DigiKey. [Online]. Available: https://www.digikey.com/en/products/detail/raspberry-pi/SC1112/21658257. [Accessed: Apr. 21,2025]
[36] “Raspberry Pi AI hat SC1791 ,” DigiKey. [Online]. Available: https://www.digikey.com/en/products/detail/raspberry-pi/SC1791/25807414. [Accessed: Apr. 21,2025]
[37] REYAX Store, “RYLR896 Lora Module SX1276 UART 868MHz 915MHz Antenna at Command FCC NCC,” Amazon. Available: Amazon.com: REYAX RYLR896 Lora Module SX1276 UART 868MHz 915MHz Antenna at Command FCC NCC : Electronics. (https://www.amazon.com/RYLR896-Module-SX1276-Antenna-Command/dp/B07NB3BK5H/142-1360784-4466356) [Accessed: Apr. 21,2025]
[38] “PCB Prototype & PCB Fabrication Manufacturer - JLCPCB,” Jlcpcb. [Online] Available: https://jlcpcb.com. [Accessed: Apr. 21,2025]
[39] “Gravity: Waterproof DS18B20 Temperature Sensor Kit,” DF Robot. [Online]. Available: https://www.dfrobot.com/product-1354.html. [Accessed: Apr. 21,2025]
[40] “Gravity: Lab Grade Analog pH Sensor Kit for Arduino,” DF Robot. [Online]. Available: https://www.dfrobot.com/product-1025.html. [Accessed: Apr. 21,2025]
[41] “Gravity: Analog Turbidity Sensor for Arduino,” DF Robot. [Online]. Available: https://www.dfrobot.com/product-1394.htmlhttps://www.dfrobot.com/product-1025.html. (https://www.dfrobot.com/product-1025.html) [Accessed: Apr. 21,2025]
[42] “Gravity: I2C ADS1115 16-Bit ADC Module (Arduino & Raspberry Pi Compatible),” DF Robot. [Online]. Available: https://www.dfrobot.com/product-1730.htm (https://www.dfrobot.com/product-1730.htm)https://www.dfrobot.com/product-1394.html (https://www.dfrobot.com/product-1394.html)https://www.dfrobot.com/product-1025.html. [Accessed: Apr. 21,2025]
[43] Amazon Basics Store, “8-Pack 9V Alkaline Batteries,” Amazon. [Online]. Available: https://www.amazon.com/Amazon-Basics-Performance-All-Purpose-Batteries/dp/B00MH4QM1S (https://www.amazon.com/Amazon-Basics-Performance-All-Purpose-Batteries/dp/B00MH4QM1S)https://www.dfrobot.com/product-1394.html (https://www.dfrobot.com/product-1394.html)https://www.dfrobot.com/product-1025.html. [Accessed: Apr. 21,2025]

Appendix A: Customer Survey
Introduction
Thank you for taking the time to complete this survey. We are a group of Electrical Engineering Students at Penn State Harrisburg. Our idea for our senior capstone project is to use a network of wireless battery-operated sensors to autonomously collect real-time data on a variety of water quality metrics. The telemetry data will be communicated wirelessly back to a central base station, where we will utilize AI-driven analytics to provide insights and make predictions about the health of the system and more efficiently allocate water resources.

Thank you for your time and expertise!

Section 1 - About You:
1. Job Title:
2. Company:

Section 2: Current Process
1. How You Monitor Water Quality
- Which tools or tests do you use now to check water quality (for example, pH meters, turbidity, chlorine tests)?
- How often do you collect or check water quality data?
- What are some challenges you face with your current water quality monitoring system?

Section 3: Design Specifications
We plan to implement a network of wireless sensors that monitor a variety of parameters contributing to overall water quality. This data will then be transferred to a central hub which can then process that data and generate alerts as needed.

Sensor Features
1. On a scale from 1-10, with 10 being extremely important, how important would it be for the sensor equipment be battery operated?
1 | 2 | 3 | 4 | 5 | 6 | 7 | 8 | 9 | 10
2. On a scale from 1-10, with 10 being extremely important, how important is it for each sensor node to have a long battery life (>10 years of operation). If being battery operated is not important or undesirable, leave this question blank.
1 | 2 | 3 | 4 | 5 | 6 | 7 | 8 | 9 | 10
3. How often would you be willing to replenish batteries the sensor nodes? If battery operation is not important or undesirable, leave this question blank.
Every: __ Year __ 1-3 years __ 3-5 years __ 5-7 years __ 7-10 years __10-15 years __15+ years
4. On a scale from 1-10, with 10 being extremely helpful, how helpful would it be if the sensors could send data from far away (even across large facilities) without needing access to Wi-Fi, Cell Service, or a Wired Connection?
1 | 2 | 3 | 4 | 5 | 6 | 7 | 8 | 9 | 10
5. Please rank the following water quality metrics, with rank 1 being the highest importance to be monitored:
__ Turbidity | __ Dissolved Oxygen
__ pH | __ Temperature
__ Conductivity | __ Total Dissolved Solids
__ Chlorine Concentration | __ Contaminant Concentration (PFOA/PFOS)
__ Other (Please Specify):

Base Station
On a scale from 1-10, with 10 being extremely desirable, how desirable is it for the system to:
1. Provide a dashboard containing real-time data?
1 | 2 | 3 | 4 | 5 | 6 | 7 | 8 | 9 | 10
2. Produce alerts when measured data falls outside of pre-set thresholds?
1 | 2 | 3 | 4 | 5 | 6 | 7 | 8 | 9 | 10
3. Send alerts directly to technicians (text message, phone notification, pager-like device, etc.) to address issues faster?
1 | 2 | 3 | 4 | 5 | 6 | 7 | 8 | 9 | 10
4. Use predictive software tools on water quality measurements to identify and address possible concerns before they arise?
1 | 2 | 3 | 4 | 5 | 6 | 7 | 8 | 9 | 10
5. Integrate with existing PLC systems or other existing controls equipment?
1 | 2 | 3 | 4 | 5 | 6 | 7 | 8 | 9 | 10
If this is important to you, and you know, what platform/PLC manufacturer is used?
6. If you know, does your team have any budget range or cost limit for new equipment?
- Under $1,000 | $1,000–$2,500 | $2,500–$5,000 | Over $5,000 | Not sure

Appendix B: Customer Survey Results

Sensor Features

On a scale from 1-10, with 10 being extremely important, how important would it be for the sensor equipment be battery operated? | On a scale from 1-10, with 10 being extremely important, how important is it for each sensor node to have a long battery life (>10 years of operation). If being battery operated is not important or undesirable, leave this question blank.
14% 1-3 years 29% 3-5 years 14% 5-7 years 7-10 years 14% 29% How often would you be willing to replenish batteries the sensor nodes? If battery operation is not important or undesirable, leave this question blank. | On a scale from 1-10, with 10 being extremely helpful, how helpful would it be if the sensors could send data from far away (even across large facilities) without needing access to Wi-Fi, Cell Service, or a Wired Connection?
8.0 Please rank the following water quality metrics, with rank 1 being the highest importance to be monitored. | | Average Ranks

10-15 years 0.0

1.0

2.0

3.0

4.0

5.0

6.0

7.0

Base Station

On a scale from 1-10, with 10 being extremely desirable, how desirable is it for the system to: Provide a dashboard containing real-time data? | On a scale from 1-10, with 10 being extremely desirable, how desirable is it for the system to: Produce alerts when measured data falls outside of pre-set thresholds?
On a scale from 1-10, with 10 being extremely desirable, how desirable is it for the system to: Send alerts directly to technicians (text message, phone notification, pager-like device, etc.) to address issues faster? | On a scale from 1-10, with 10 being extremely desirable, how desirable is it for the system to: Use predictive software tools on water quality measurements to identify and address possible concerns before they arise?
On a scale from 1-10, with 10 being extremely desirable, how desirable is it for the system to: Integrate with existing PLC systems or other existing controls equipment? | 29% Not Sure Over $5,000 71% If you know, does your team have any budget range or cost limit for new equipment?

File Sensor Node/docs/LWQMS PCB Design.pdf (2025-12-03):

# LoRa Water Quality Management System

# PCB Design

## Team Members:

## Cole Hadley, Patrico Benitez Palermo, and Matthew Sharp

## Technical Advisor: Dr. Aldo Morales

## Date: 11/21/2025

PCB Design Overview

Though PCBs were designed for both the sensor node and central gateway of the LoRa Water Quality Management System, the PCB which required the majority of the engineering labor was the sensor node PCB. This part of the system is responsible for interfacing directly with the turbidity, temperature, and pH sensors which will inform the decision-making logic at the central gateway. The sensor node PCB integrates sensor interface circuitry, the signal conditioner subsystem, a microcontroller, the LoRa transceiver module, USB, UART, and SWD interfaces, along with indicator LEDs and a RF signal path.

The PCB was entirely designed using KiCAD, a freely available PCB design software. In addition to the features available within KiCAD the RF-Tools plugin was used to manage critical high-speed signal paths, as well as Saturn PCB Toolkit to determine PCB trace geometries for impedance-controlled traces. Though most of the traces carry low-speed analog and digital signals, there were a few special considerations that needed to be made when developing the final design. First, the design involved a RF signal trace connecting the LoRa transceiver module and the external antenna, as well as USB 2.0 data traces. To maintain signal integrity within the PCB and prevent potentially damaging signal reflections, the RF signal trace had to be impedance controlled to 50Ω, while the USB 2.0 traces needed to maintain a differential impedance of 90Ω, ±15%. Next, the power supply into the sensor node needed to accept a wide input voltage range, manage heat dissipation effectively, and accommodate large switching currents through its inductor. Another key area of special concern is power distribution, as the PCB must accommodate four distinct voltage rails throughout the design, while maintaining low impedance and efficient routing. The microcontroller layout was another area of concern within the design, as the chosen RP2350 microcontroller requires a substantial decoupling network, introduces a new power rail, and provides all of the external interfaces on the board. Finally, the PCB must minimize the propagation of high-frequency noise throughout the rest of the traces and outside of the PCB to improve signal integrity and minimize unwanted external noise.

The PCB can be divided into four main sections: power input and regulation, microcontroller layout, analog front-end, and RF interface. To minimize the effects of high-frequency noise on critical traces, the RF interface and switching regulators were isolated from the microcontroller and analog front-end. The main subsystem that this PCB was designed to accommodate is the Signal Conditioner, which is the subsystem that was designed “from scratch” for the purpose of this project. The purpose of the signal conditioner subsystem is to provide a unified analog front-end which will be shared among all the sensors used with the system. It applies DC offsets and gain to the incoming signal, making them compatible with an analog-to-digital converter (ADC). The value read by the ADC is read by the microcontroller, which formats the incoming data as real-world measurements, and transmits the telemetry to the central gateway using LoRa. The gain and DC offsets of the signal conditioner are controlled using digital potentiometers, making the signal acquisition process fully software-controlled and autonomous. Outside of managing the parameters of the signal conditioner and the LoRa interface, the microcontroller also manages the power consumption of the PCB, controlling the 5V rail by enabling and disabling the power regulator IC, disconnecting the sensors and minimizing power draw while the system is idle.

PCB Design Steps

Before the PCB routing was initiated, the schematic design was first finalized using KiCAD for schematic capture and LTSpice for analog simulation. Full schematic captures of the design have been attached to the end of this report. The RP2350 schematic largely follows Raspberry Pi’s reference design guide, with some modifications made on the USB boot control and reset to make operation more reliable. The major component selections for the sensor node were made as follows, with corresponding justification:

Power Regulation

- Texas Instruments TPS63000 Buck-Boost Regulator IC: Wide input voltage range (1.8-5.5V), adjustable output from 1.2 to 5.5V, 90% typical operating efficiency, single inductor for buck and boost mode operation, robust reference design and documentation. Schematic follows the reference design with an oversized output capacitor.
- Texas Instruments LM2660 Switching Capacitor: 100mA output current, straightforward design, Vout = -Vin, compatible with 5V input.

Microcontroller

- Raspberry Pi RP2350: Robust C/C++ Software-Development Kit, two I²C and SPI peripherals integrated on-chip, many GPIOs, high clock speed, robust power management capabilities.
- Texas Instruments LSF0102 Logic Level Translator: Straightforward Design, 3.3V-5V compatibility.
- Macronix MXL25L3233F NOR Flash: SPI Interface, Non-volatile memory, 32Mbit
- Winbond W25Q128J NOR Flash (MCU Program Memory): QSPI Interface, High Datarate, 128Mbit suitable for most firmware builds, supported by MCU bootloader

Analog Front-End

- Texas Instruments TMUX1309 MUX: Differential, Analog Pass-through capability

- Texas Instruments TLV9144 Op-Amp: Low Power consumption, rail-to-rail input and output, high CMRR, high input impedance, quad package
- Microchip MCP4651 Digital Potentiometer: Two Potentiometers on-chip, I²C control
- Microchip MCP3425 ADC: Sigma-Delta Design, 16-bit precision, I²C Interface
- Texas Instruments TL082 Op-Amp: High Input Impedance, Dual Package

RF Interface

- SX1262 LoRa Modulator: Industry-Standard IC, robust documentation, manufacturer-provided SPI lookup table directly compatible with C-based firmware
- SX1262 implemented using Waveshare Core1262-HF LoRa Module, selected as it simplified the design process and has integrated EMI shielding.

With the component selections made, the component footprints were downloaded from the respective component manufacturers where available, and standard IC package footprints were used when models were not directly available. From there, the components were segregated based on to which PCB category they belonged – the RF interface and power supply were located towards the corners of the board to minimize noise, while the microcontroller was located centrally to maximize access to all digital signals. The analog frontend was placed at the bottom of the board for proximity to the sensor connectors. All other connectors were located such that they were close to the nets they would interface with. Before traces were routed, the board stackup and net classes were defined, producing a 4-layer board with impedance control on the USB traces and RF signal path. The USB geometry was defined as a differential pair with 0.2mm track width and 0.14mm separation, giving a 90.049Ω differential impedance according to Saturn PCB toolkit. The RF signal path was defined as a coplanar waveguide with 0.35mm track width and 0.15mm clearance, giving a 50.13Ω characteristic impedance. To maintain the topology needed for the differential traces and coplanar waveguide, the stackup of the board was defined to be signal traces, ground, power rails, signal traces and ground, from top to bottom.

The first section that was routed was the power regulator, shown below. This section’s key concerns included thermal management and managing potentially high currents. Stitching vias were used on the power input to increase surface area for heat dissipation, and on power outputs to provide a low impedance path to the power planes. Traces to the inductor were maximized in available width, supporting up to 1A of current through the inductor, well above the calculated switching current.

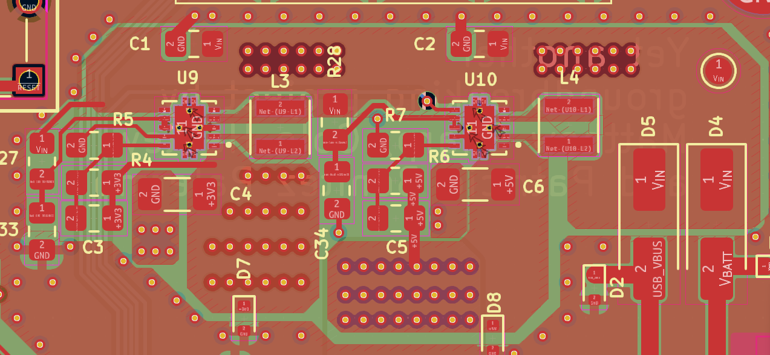
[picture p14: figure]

Figure 1: Power Regulation Section of PCB, as Produced in KiCAD

The next section to be routed was the microcontroller, which relied heavily on the manufacturer’s reference design, however it needed to be adapted for the 4-layer board stackup and larger 0805 surface-mounted components. The RP2350 is shown as U8 below, with USB traces run directly to the USB port through 27Ω termination resistors. The internal power and ground planes have been hidden in the viewport shown to show the 1.1V copper pour used to supply the internal logic core of the microcontroller. This rail is produced by an internally-controlled buck regulator inside the RP2350 MCU, with external inductor and capacitors required for operation, shown as C20, C21, and L2 below. Key attention needed to be paid to keep these components as close to the footprint of the chip as possible while maximizing ampacity.

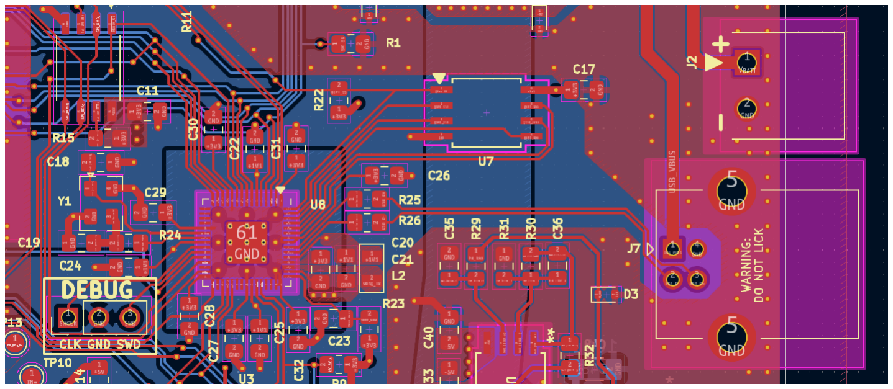
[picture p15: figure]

Figure 2: RP2350 Microcontroller Layout, as Produced in KiCAD

Next, the signal conditioner subsystem was routed. Important considerations for this section included prioritizing the I²C traces in the routing order for reliable communication with the digital potentiometers and ADC. Analog traces needed to be kept short, while also maintaining access to test points for hardware debugging.

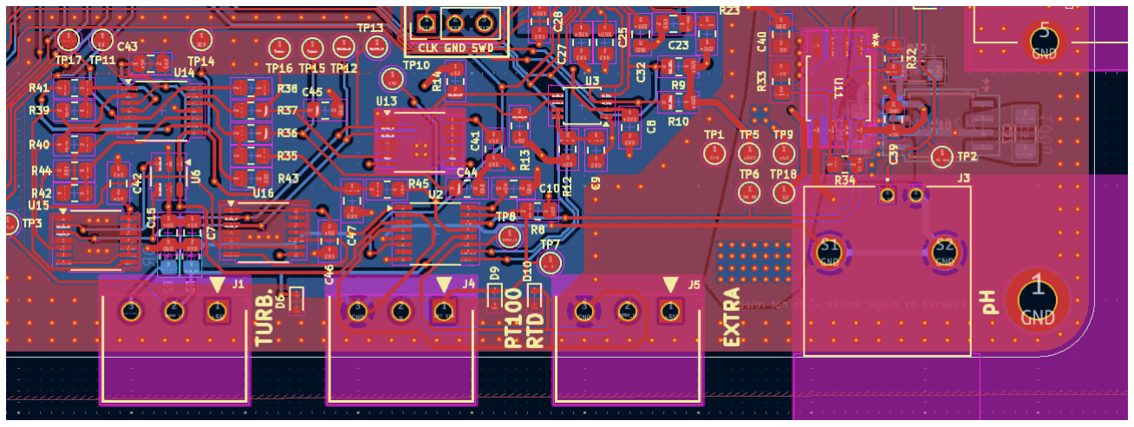
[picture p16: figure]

Figure 3: Signal Conditioner Subsystem Layout, as Produced in KiCAD

The final routing section is the RF interface, for which most of the components were managed by the integration of the Waveshare Core1262 LoRa Modulator Module. Key considerations in this section included maintaining 50Ω characteristic impedance along the coplanar waveguide, integrating pi filter footprints such that they have minimal impact on trace geometry, and utilizing fencing and stitching vias in this area as well as along the board edge to minimize noise and interference caused by this section.

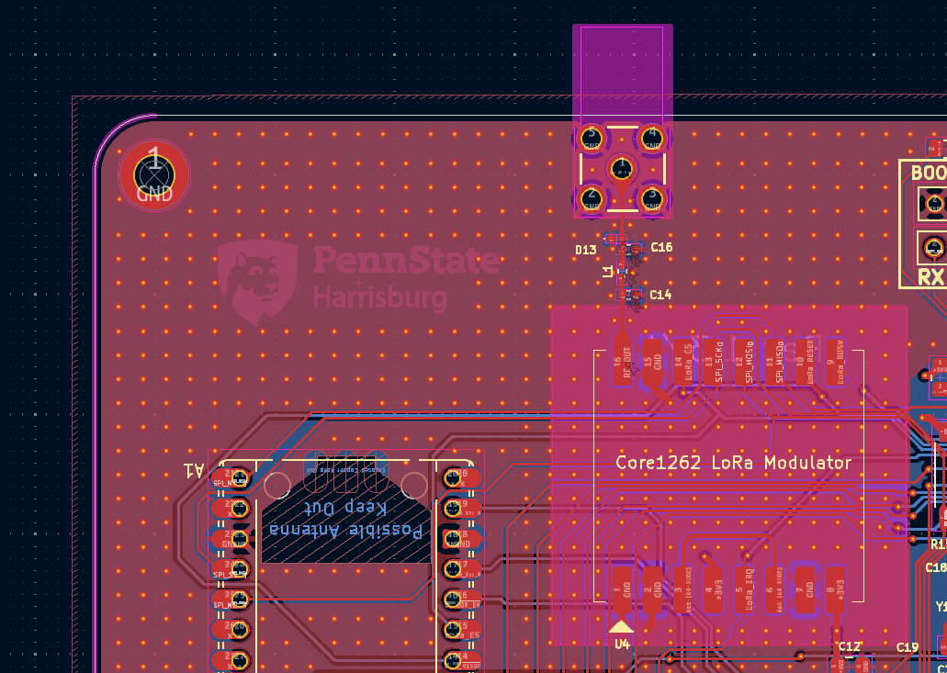
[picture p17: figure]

Figure 4: RF Frontend Layout, as Produced in KiCAD

PCB Photos

Below are 2D plots and 3D renders of the final PCB design, as produced in KiCAD. In addition to the layout described in the previous section, a full Raspberry Pi Pico 2 Footprint was added to the design as a failsafe mechanism if any layout errors in the microcontroller system of the board would prevent the functioning of the design.

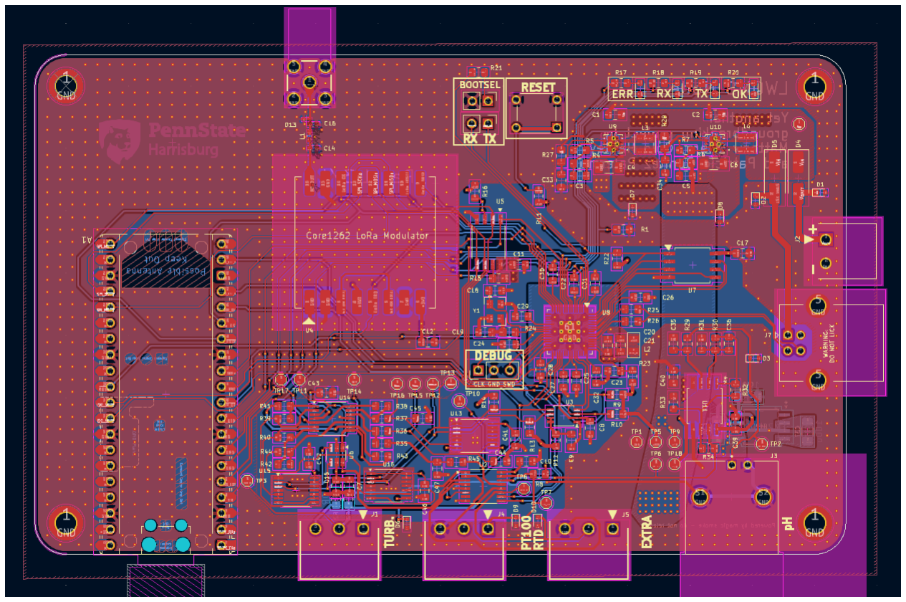
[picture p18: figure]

Figure 5: Full 2D Render of Design as produced in KiCAD. Internal layers are hidden to show tracks on signal layers.

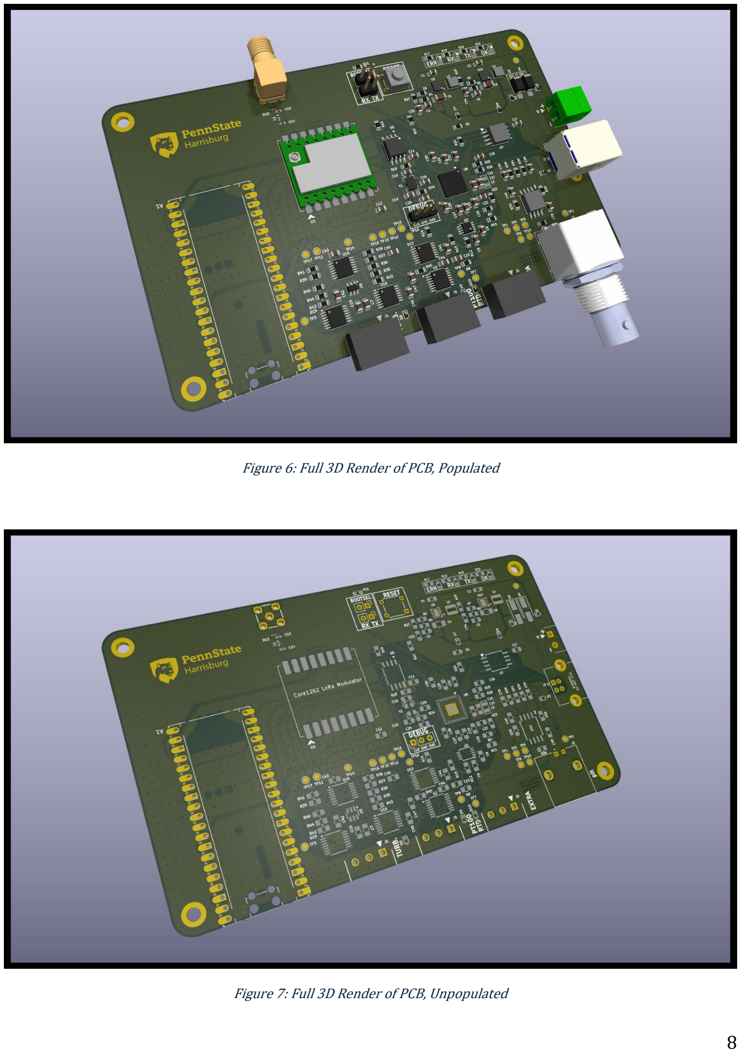
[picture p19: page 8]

Figure 6: Full 3D Render of PCB, Populated

Figure 7: Full 3D Render of PCB, Unpopulated

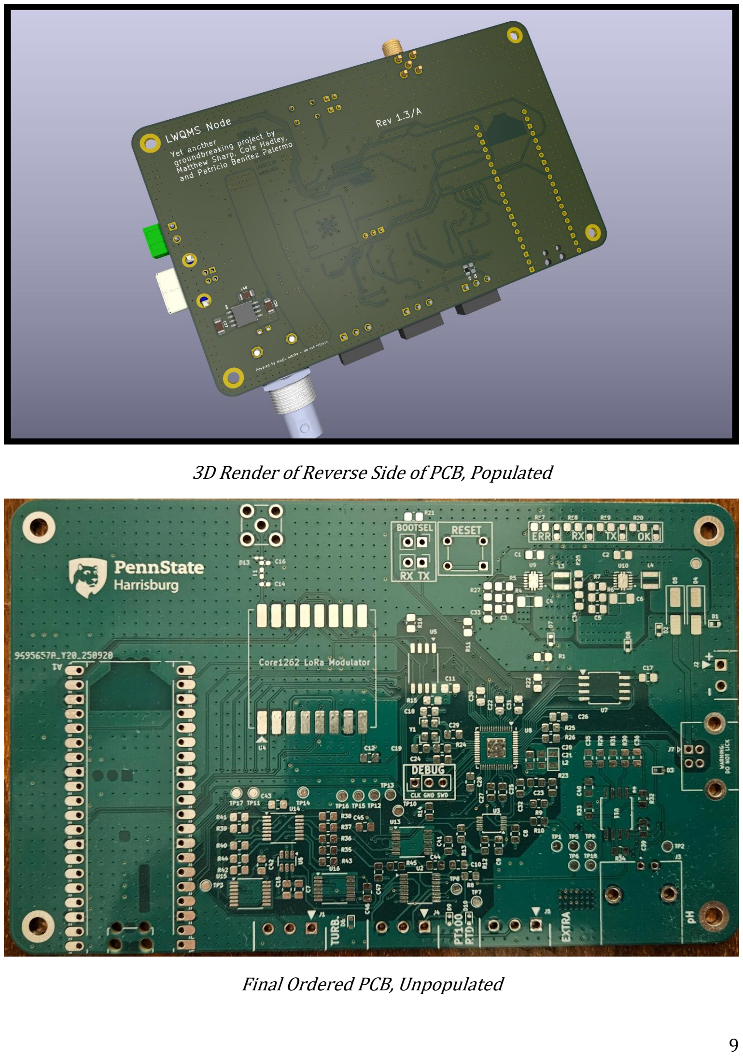
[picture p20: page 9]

3D Render of Reverse Side of PCB, Populated

Final Ordered PCB, Unpopulated

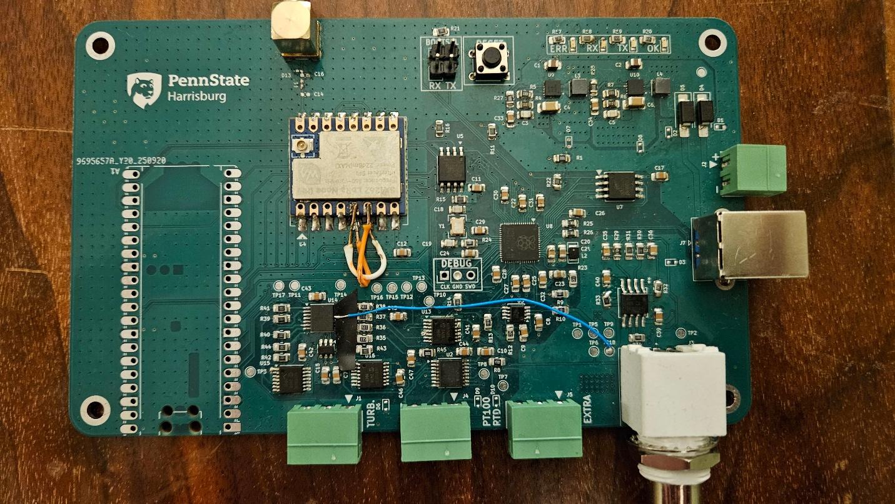
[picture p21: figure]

Final Ordered PCB, Populated

PCB Testing & Discussion of Results

Testing Background

To account for nonlinearities and resistance deviations between digital potentiometers discovered during initial testing, an automatic calibration routine was incorporated into the sensor node’s firmware. The calibration measures the DC offsets and Gain Resistor values at each potentiometer wiper step location (0-256). This data is then stored on a NOR flash IC on the PCB, which the microcontroller then reads into memory, using it to accurately set the digital potentiometers according to desired gain and DC offset values. Plots of the DC offset and gain resistance values, as well as corresponding error are shown in figures 8-11 below.

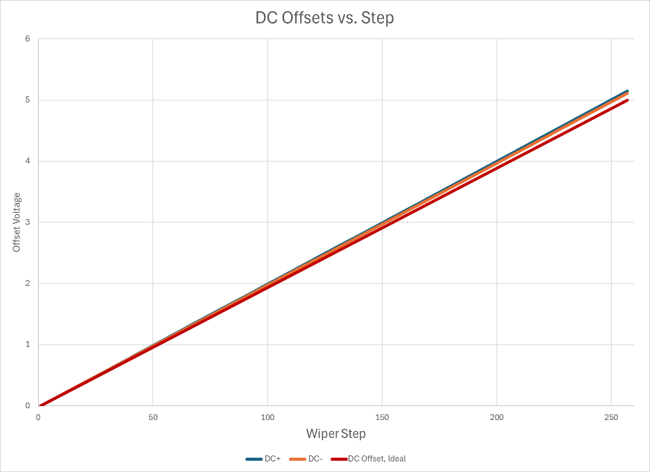
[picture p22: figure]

Figure 8: DC Offset Voltages versus Wiper Step Location. DC+ is plotted in Blue, DC- is plotted in Orange, and the Ideal DC Offset Voltage is Plotted in Red.

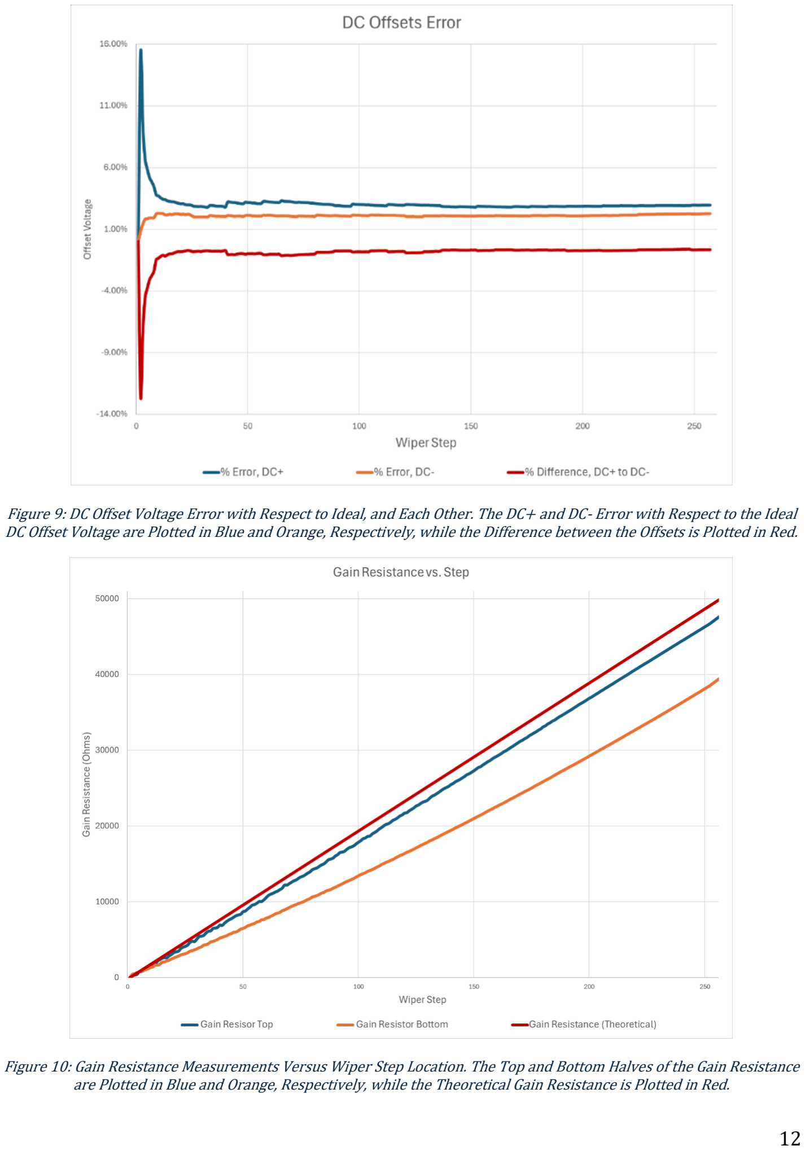
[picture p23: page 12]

Figure 9: DC Offset Voltage Error with Respect to Ideal, and Each Other. The DC+ and DC- Error with Respect to the Ideal DC Offset Voltage are Plotted in Blue and Orange, Respectively, while the Difference between the Offsets is Plotted in Red.

Figure 10: Gain Resistance Measurements Versus Wiper Step Location. The Top and Bottom Halves of the Gain Resistance are Plotted in Blue and Orange, Respectively, while the Theoretical Gain Resistance is Plotted in Red.

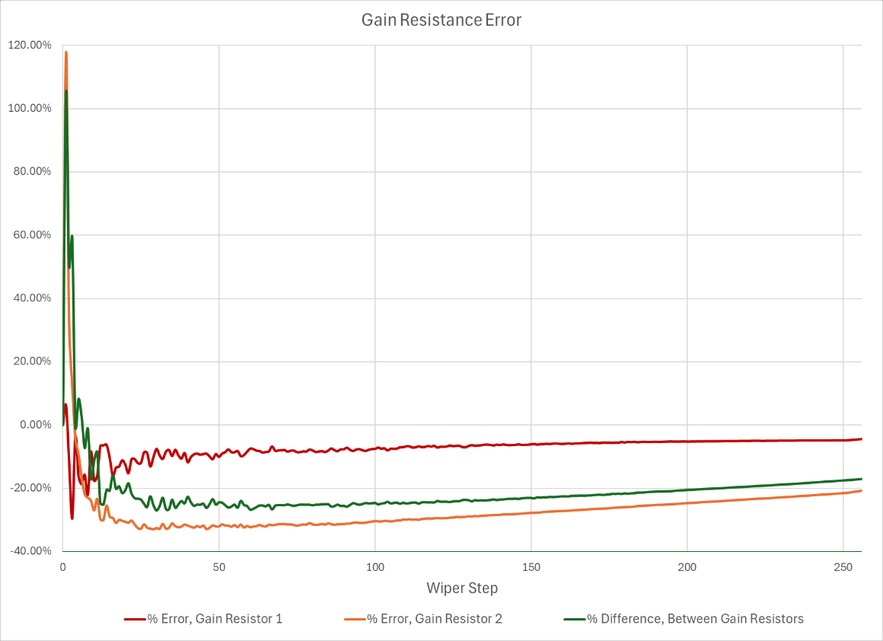
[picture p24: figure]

Figure 11: Gain Resistance Error. The error with respect to the theoretical gain resistance for the top and bottom halves of the gain resistor are plotted in red and orange, respectively, while the difference between the two resistors is plotted in green.

Testing Methods & Relation to Engineering Requirements

With the calibration of the software-defined instrumentation amplifier portion of the signal conditioner subsystem complete, a preliminary test of the calibration software component was performed. Following from the engineering requirements of the signal conditioner subsystem:

- Interprets the analog voltages produced by the sensors as digital data
- Converts the digitized analog voltage readings to relevant measurement units for pH, turbidity, and temperature
- Formats the data to be sent to the central gateway module

Accurate and reliable operation of the software-defined instrumentation amplifier, which pre-processes incoming analog sensor voltages to be compatible with the ADC and provide increased resolution in the measurement region of interest, are necessary for full operation of this subsystem.

Tables 1 and 2 below show the performance of the software-defined instrumentation amplifier in meeting desired analog characteristics for both gain and input

DC offset. The values selected by the firmware using the calibration data were then compared against the resulting values if an idealized potentiometer was considered in the code to compute both the gain and the DC offsets. For example, if a gain of 3 is requested by the user or within an autonomous call to the function in the code, the firmware will select the combination of gain resistors on both the top and bottom wipers that are as close to 10kΩ as possible (Gain =

2×10kΩ
RG

+ 1 = 3 → RG = 10kΩ). If this calibration data was not

used, the firmware would instead need to select the wiper positions assuming an ideally linear potentiometer with end-to-end resistance of 50kΩ. For a gain of 3, the selected wiper position would be calculated as: (1 −

10kΩ
50kΩ

) ∗ 256 = 205, producing a gain resistance of

9.8132kΩ given the measured resistance of the potentiometer at that location, and a resulting gain of 3.03, introducing non-negligible error into the system. The resulting performance difference in the amplifier output voltage and computed input voltage by the firmware for both the calibration-controlled system and the non-calibrated system are shown in tables 3, and 4 below.

As seen in the tables below, the integration of calibration data into the software-defined instrumentation amplifier greatly improves system performance, driving gain to 0.26% in the worst case compared to 11.63% in the worst case for the uncalibrated system, and ultimately resulting in significant reductions in error between the calculated input voltage of the system and the actual input voltage, demonstrating the software component of the design’s ability to help the system meet its functional requirements.

Table 1: Gain Selection Performance of the Software-Defined Calibration Data, Uncalibrated vs. Calibrated

Table 2: DC Offset Selection Performance of the Software-Defined Instrumentation Amplifier, Uncalibrated vs. Calibrated

Input Voltage Ideal Gain Actual Gain, Assuming Ideal Pots % Error Software-Selected Gain % Error
0.10727 | 12 | 10.64 11.33% | 12.030886 0.26%
0.40825 | 4 | 3.95 | 1.25% | 4.000105 | 0.00%
0.7996 | 2 | 2.01 0.50% | 2.000037 0.00%
1.20286 | 3.5 | 3.469 | 0.89% | 3.49919 | 0.02%
1.5077 | 3 | 3.0022 0.07% | 2.99962 0.01%
1.8005 | 5 | 4.936 | 1.28% | 4.998462 | 0.03%
2.00948 | 2.5 | 2.513 0.52% | 2.500217 0.01%

Input Voltage Ideal DC Offset Actual DC Input Offset, Assuming Ideal Pots % Error Software-Selected DC Offset % Error
0.10727 | 0 | 0.00002512 N/A | 0.002512 N/A
0.40825 | 0 | 0.00002512 | N/A | 0.002512 | N/A
0.7996 | 0 | 0.00002512 N/A | 0.002512 N/A
1.20286 | -1 | -0.977 | 2.30% | -0.994864 | 0.51%
1.5077 | -1 | -0.977 2.30% | -0.994864 0.51%
1.8005 | -1.5 | -1.534 | 2.27% | -1.492605 | 0.49%
2.00948 | -1.5 | -1.534 2.27% | -1.492605 0.49%

Table 3: Output Voltage Performance of the Software-Defined Instrumentation Amplifier, Uncalibrated vs. Calibrated

Table 4: Input Voltage Calculation for the Software-Defined Instrumentation Amplifier, Calibrated vs. Uncalibrated

With the calibration data obtained for the amplifier and the signal acquisition process validated, the final testing step was using the amplifier to convert incoming analog sensor voltages to meaningful measurements for water quality management. Shown below in figures 12, 13, and 14 are plots corresponding to the input voltage versus environmental measurement value for the pH sensor, RTD (temperature) sensor, and turbidity sensor, respectively. During testing of the RTD, a consistent +3mV offset was observed on the input voltage compared to the expected voltage measurement. To account for this, a −3mV offset was applied to the RTD input; since 3mV is too fine of an offset to apply using the software-defined instrumentation amplifier, this offset was applied in software. This change is reflected in figure 13 below, showing the raw temperature measurement in blue, the actual environmental temperature in orange, and the calculated temperature in green after the −3mV input offset was applied. As shown in the figure, applying this offset produced a temperature response much more consistent with the ideal response.


Figure 12: pH Sensor Voltage as measured by the Signal Conditioner versus Actual pH.

Input Voltage Theoretical ADC Voltage Measured ADC Voltage % Error, w.r.t. Theoretical ADC Voltage, Assuming Ideal Pot % Error, w.r.t. Theoretical % Difference, Measured vs. Idealized
0.10727 | 1.2 | 1.425812 | 18.82% | 1.141620077 | 4.86% | 19.93%
0.40825 | 1.6 | 1.703875 | 6.49% | 1.612686724 | 0.79% | 5.35%
0.7996 | 1.6 | 1.602 | 0.13% | 1.607246491 | 0.45% | 0.33%
1.20286 | 0.7 | 0.7775 | 11.07% | 0.78350834 | 11.93% | 0.77%
1.5077 | 1.5 | 1.598125 | 6.54% | 1.59326754 | 6.22% | 0.30%
1.8005 | 1.5 | 1.639438 | 9.30% | 1.315444 | 12.30% | 19.76%
2.00948 | 1.25 | 1.321938 | 5.76% | 1.19488124 | 4.41% | 9.61%
Input Voltage Actual ADC Voltage | Calculated Input Voltage, Assuming Ideal Pots % Error, w.r.t. Actual | Software-Estimated Actual Input Voltage % Error, w.r.t. Actual
0.10727 | 1.425812 | 0.133979767 | 24.90% | 0.11463 | 6.86%
0.40825 | 1.703875 | 0.431335639 | 5.65% | 0.419321 | 2.71%
0.7996 | 1.602 | 0.796989805 | 0.33% | 0.790224 | 1.17%
1.20286 | 0.7775 | 1.201127991 | 0.14% | 1.212298 | 0.78%
1.5077 | 1.598125 | 1.509317967 | 0.11% | 1.522139 | 0.96%
1.8005 | 1.639438 | 1.866138979 | 3.65% | 1.817292 | 0.93%
2.00948 | 1.321938 | 2.060039793 | 2.52% | 2.014735 | 0.26%


Figure 13: RTD Temperature vs. Input Voltage

Figure 14: Turbidity Sensor Measurement vs. Input Voltage

4p R6

# TP4 R1


SPI Flash used to store
SPI_MISO_{0} RF_OUT

require TX enable to be
tied to VDD when in

Since the RP2350 is a
the sensors (and
run on 5V, a level shifter
3.3V gpio pins of the MCU
safe. The SCL/SDA pins of

(5V) in mind. SENSOR INPUTS/OUTPUTS ARE ALL ENABLED BY

this design, as it allows for the D-Cell battery supply to operate anywhere along

Sensor Value Readback
V_{DD} 16 DA 13 DB 3 NC 7 U2 TMUX1309

THE 5V_EN PIN OF THE REGULATOR!! - NO NEED
FOR REDUNDANT IC TO SAVE POWER FOR A COUPLE OF SECONDS WHILE THE SENSORS ARE

FOOTPRINT FOR USE IN

# +3V3 Raspberry Pi


6 QSPI_IOVDD 54 IOVDD 45 IOVDD 38 GND 61 IOVDD 30 IOVDD 20 IOVDD 11 IOVDD

12 MHz XTAL Ref. Section 4 of design guide

series (as seen by the

flash IC, however 128Mbit gives
flash IC would need to support
these comands: 0x03 Serial Read

0x05 Read Status Register 0x06 Set Write Enable Latch

File: rp2350_layout.kicad_sch Sheet: /MCU/
Id: 2/6 Title: LoRa Water Quality Management System Sensor Node

D Date: KiCad; E.D.A. 9.0.4 Size: A4; Rev:; File: lwqms_power_supply.kicad_sch Sheet: /Buck-Boost; Regulator; Layout/; L2 2 VOUT 1 FB 10 U9 TPS63000 C33; VIN; sx1262: 118mA max in +22dBm; TX Mode +200mA; headroom; Let's call it 500mA expected worst case input current.; Most of the time we will be in sleep mode and never come close to this. Energizer considers; the useable life of their D-Cell; batteries; to be up to 0.8V, meaning a minimum; expected input voltage of 2.4V is reasonable.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

VOUT GND Maximum Current Throughput: RP2350: ~100mA max

LQH3NPZ2R2MMEL
L1 4 VIN 5 EN 6 VINA 8 PS/SYNC 7 PGND 3 GND 9
100R GND

Id: 3/6 Title: LoRa Water Quality Management System Sensor Node

D Date: KiCad; E.D.A. 9.0.4 Size: A4; Rev:; File: lwqms_power_supply.kicad_sch Sheet: /Buck-Boost; Regulator; Layout1/; L2 2 VOUT 1 FB 10 U10 TPS63000 R28; C34 100n GND; VIN; sx1262: 118mA max in +22dBm; TX Mode +200mA; headroom; Let's call it 500mA expected worst case input current.; Most of the time we will be in sleep mode and never come close to this. Energizer considers; the useable life of their D-Cell; batteries; to be up to 0.8V, meaning a minimum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

VOUT GND Maximum Current Throughput: RP2350: ~100mA max

LQH3NPZ2R2MMEL
L1 4 VIN 5 EN 6 VINA 8 PS/SYNC 7 PGND 3 GND 9

Id: 4/6 Title: LoRa Water Quality Management System Sensor Node


Id: 5/6 Title: LoRa Water Quality Management System Sensor Node

Software-Defined | Instrumentation | Amplifier


LMV324A op amp chosen as its output voltage can be within

20mV (typ.) of its input rails. High CMRR, quad package, and

44 cents per IC are a plus.

Id: 6/6 Title: LoRa Water Quality Management System Sensor Node

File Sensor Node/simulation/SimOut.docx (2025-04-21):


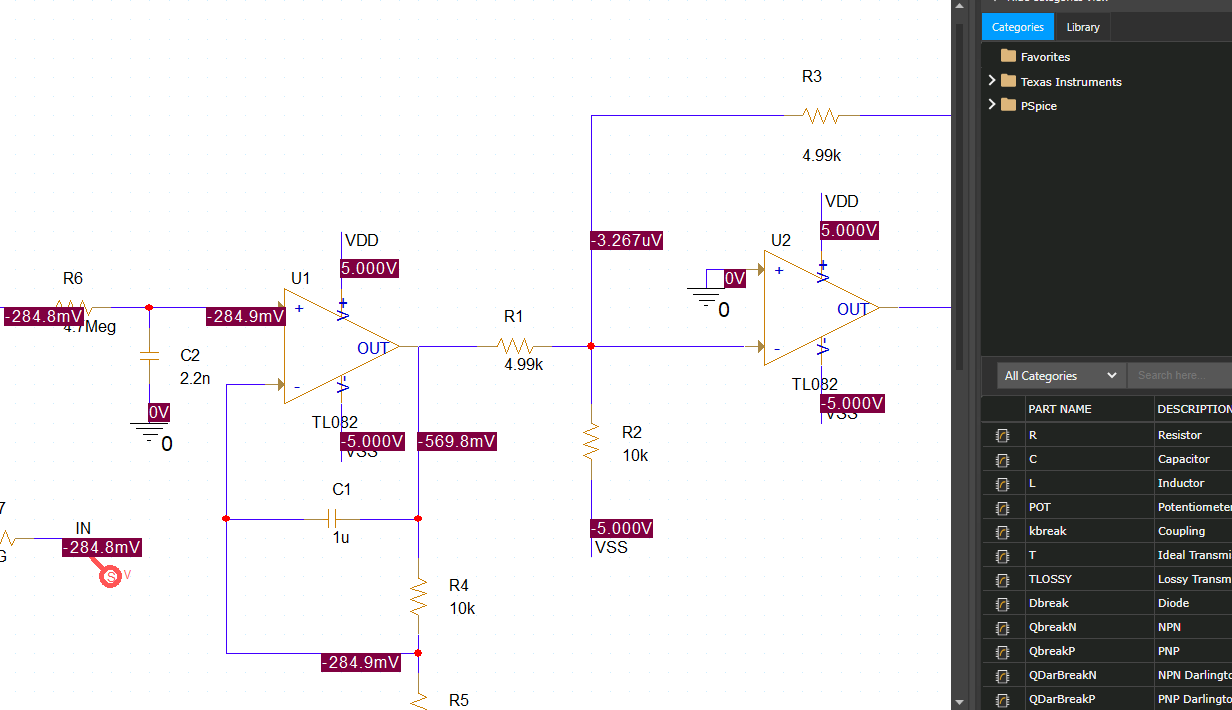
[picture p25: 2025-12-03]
Sensor Node/simulation/pH_sensor_preamp/PH_SENSOR_PREAMP.png

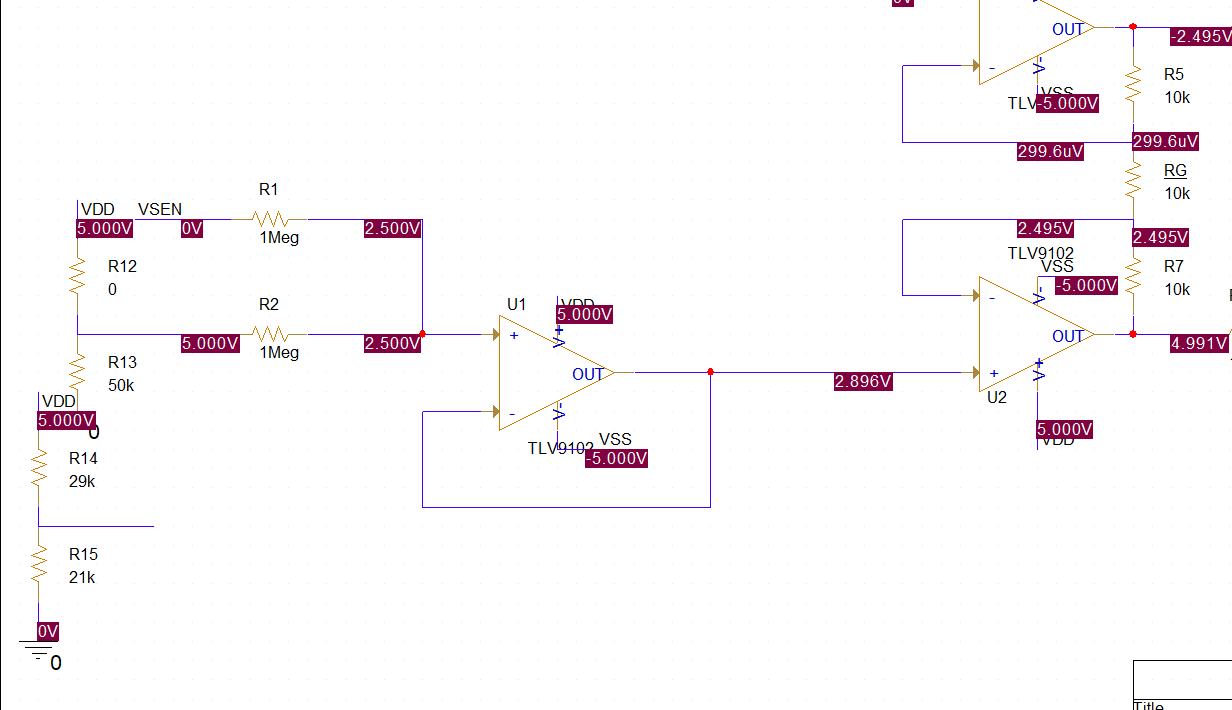
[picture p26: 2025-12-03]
Sensor Node/simulation/Software-Defined Instrumentation Amplifier/Software_Defined_Instrumentation_Amplifier/SOFTWARE_DEFINED_INSTRUMENTATION_AMPLIFIER.png

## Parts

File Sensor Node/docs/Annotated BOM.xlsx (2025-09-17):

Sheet: BOM
Connectors
Reference | MFG P/N | Qty/Board | Unit Cost | Ext. Cost | Description | Digikey Link
J1, J4, J5 | OSTOQ033251 | 3 | $0.65 | $1.95 | 3 Pin Connector, 3.81mm pitch | https://www.digikey.com/en/products/detail/amphenol-anytek/OQ0332510000G/2261261
J2 | OQ0232510000G | 1 | $0.27 | $0.27 | 2 Pin Connector, 3.81mm pitch | https://www.digikey.com/en/products/detail/amphenol-anytek/OQ0232510000G/2261255
J3 | CONBNC002 | 1 | $2.05 | $2.05 | BNC connector | https://www.digikey.com/en/products/detail/amphenol-rf/031-5431-10RFX/2041816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
N/A | OSTTJ0331530 | 3 | $1.88 | $5.64 | Mating connector for OQ0332510000G | https://www.digikey.com/en/products/detail/amphenol-anytek/TJ0331530000G/2261322
N/A | TJ0231530000G | 1 | $0.67 | $0.67 | Mating connector for OQ0232510000G | https://www.digikey.com/en/products/detail/amphenol-anytek/TJ0231530000G/2261289
J7 | UJ2-BH-BL1-TH | 1 | $0.51 | $0.51 | USB Type B Female Connector | https://www.digikey.com/en/products/detail/same-sky-formerly-cui-devices/UJ2-BH-BL1-TH/6188083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
J8 | SMA-J-P-H-RA-TH1 | 1 | $3.43 | $3.43 | SMA antenna connector | https://www.digikey.com/en/products/detail/samtec-inc/SMA-J-P-H-RA-TH1/2664715
J10 | 3 Pos. Pin Header | 1 | $0.00 | $0.00 | 3 Pos. Pin Header
J6, J9 | 2 Pos. Pin Header | 2 | $0.00 | $0.00 | 2 Pos. Pin Header
Connectors Subtotal |  |  |  | $14.52
ICs
Reference | MFG P/N | Qty/Board | Unit Cost | Ext. Cost | Description | Digikey Link
U2 | TMUX1309APWR | 1 | $0.37 | $0.37 | 2x SP4T Switch | https://www.digikey.com/en/products/detail/texas-instruments/TMUX1309APWR/24708482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
U3 | LSF0102DCTR | 1 | $0.43 | $0.43 | I2C Level Shifter | https://www.digikey.com/en/products/detail/texas-instruments/LSF0102DCTR/4806524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
U5 | MX25L3233FM2I-08Q | 1 | $0.48 | $0.48 | 32Mbit SPI Flash Memory | https://www.digikey.com/en/products/detail/macronix/MX25L3233FM2I-08Q/7402342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
U6 | MCP3425A0T-E/CH | 1 | 2.48 | 2.48 | 16 Bit A/D with I2C Interface | https://www.digikey.com/en/products/detail/microchip-technology/MCP3425A0T-E-CH/1827893
U7 | W25Q128JVSIQ TR | 1 | $1.85 | $1.85 | 128MBit QSPI Program Memory | https://www.digikey.com/en/products/detail/winbond-electronics/W25Q128JVSIQ/5803943
U8 | RP2350_60QFN | 1 | $1.10 | $1.10 | Microcontroller | https://www.digikey.com/en/products/detail/raspberry-pi/SC1509-13/26241107
U9,U10 | TPS63000DRCR | 2 | $2.61 | $5.22 | 1.6A Buck-Boost Converter | https://www.digikey.com/en/products/detail/texas-instruments/TPS63000DRCR/1016474
U11 | TL082CDR | 1 | $0.35 | $0.35 | JFET Input Op-Amp x 2 | https://www.digikey.com/en/products/detail/texas-instruments/TL082CDR/276927
U14 | LMV324IPWR | 1 | $0.44 | $0.44 | Quad Rail-To-Rail Op-Amp | https://www.digikey.com/en/products/detail/texas-instruments/LMV324IPWR/381071
U13,U15,U16 | MCP4651T-503E/ST | 2 | $1.24 | $2.48 | 50kOhm 2x Digital Potentiometer with I2C Interface | https://www.digikey.com/en/products/detail/microchip-technology/MCP4651T-503E-ST/2061292
ICs Subtotal |  |  |  | $15.20
Specialized Components
D4,D5 | B240AE-13 | 2 | $0.20 | $0.40 | Schottky Diode | https://www.digikey.com/en/products/detail/diodes-incorporated/B240AE-13/7352825
D1,D2,D3,D6,D8,D9,D10 | T5V0S5A-7 | 7 | $0.08 | $0.58 | 5V TVS | https://www.digikey.com/en/products/detail/diodes-incorporated/T5V0S5A-7/17840287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
D7 | T3V3S5A-7 | 1 | $0.15 | $0.15 | 3.3V TVS | https://www.digikey.com/en/products/detail/diodes-incorporated/T3V3S5A-7/17840278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
D12, D14, D15 | KT EELP41.12-S2U1-25-2X4Y-5-R18 | 3 | $0.16 | $0.48 | Green LED | https://www.digikey.com/en/products/detail/ams-osram-usa-inc/KT-EELP41-12-S2U1-25-2X4Y-5-R18/24765233
D13 | ESDARF02-1BU2CK | 1 | $0.13 | $0.13 | 3.3V 3GHz BW TVS Diode | https://www.digikey.com/en/products/detail/stmicroelectronics/ESDARF02-1BU2CK/5768407
D11 | KR EELP41.22-Q1S1-36-A8J8-020-R18 | 1 | $0.14 | $0.14 | Red LED | https://www.digikey.com/en/products/detail/ams-osram-usa-inc/KR-EELP41-22-Q1S1-36-A8J8-020-R18/24765238
Y1 | ABM8-272-T3 | 1 | $0.54 | $0.54 | 12MHz XTAL Oscillator | https://www.digikey.com/en/products/detail/abracon-llc/ABM8-272-T3/22472366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
L3, L4 | LQH3NPZ2R2MMEL | 2 | $0.34 | $0.68 | Buck-Boost Converter Inductor | https://www.digikey.com/en/products/detail/murata-electronics/LQH3NPZ2R2MMEL/6799398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
L2 | AOTA-B201610S3R3-101-T | 1 | $0.22 | $0.22 | RP2350 DC-DC Inductor with Guaranteed Winding Direction | https://www.digikey.com/en/products/detail/abracon-llc/AOTA-B201610S3R3-101-T/25621527
Specialized Components Subtotal |  |  |  | $3.32
Components
Reference | MFG P/N | Qty/Board | Unit Cost | Ext. Cost | Description | Digikey Link
R8,R27,R28,R45 | RNCF0805DTE100R | 4 | $0.10 | $0.40 | 100R (0.5%) | https://www.digikey.com/en/products/detail/stackpole-electronics-inc/RNCF0805DTE100R/1708180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
L1, R2 | RMCF0805ZT0R00 | 2 | $0.01 | $0.02 | Jumper (qty 10. cheaper than qty. 1) | https://www.digikey.com/en/products/detail/stackpole-electronics-inc/RMCF0805ZT0R00/1756901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
R12, R33 | RMCF0805FT200K | 2 | $0.10 | $0.20 | 200k | https://www.digikey.com/en/products/detail/stackpole-electronics-inc/RMCF0805FT200K/1760341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
R11,R15,R16,R22,R35,R36,R37,R38,R39,R40,R41,R42,R43,R44 | RNCF0805DTE10K0 | 14 | $0.03 | $0.38 | 10k (0.5%) | https://www.digikey.com/en/products/detail/stackpole-electronics-inc/RNCF0805DTE10K0/1708247
R21,R24,R31,R9,R10,R13,R14 | RMCF0805FT1K00 | 7 | $0.02 | $0.14 | 1k | https://www.digikey.com/en/products/detail/stackpole-electronics-inc/RMCF0805FT1K00/1760090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
R23 | RMCF0805FT33R0 | 1 | $0.10 | $0.10 | 33R | https://www.digikey.com/en/products/detail/stackpole-electronics-inc/RMCF0805FT33R0/1760586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
R3 | RMCF0805FT4K70 | 1 | $0.10 | $0.10 | 4.7k | https://www.digikey.com/en/products/detail/stackpole-electronics-inc/RMCF0805FT4K70/1760659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
R25,R26 | RMCF0805FT27R0 | 2 | $0.10 | $0.20 | 27R | https://www.digikey.com/en/products/detail/stackpole-electronics-inc/RMCF0805FT27R0/1712920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
R17 | RMCF0805FT71R5 | 1 | $0.10 | $0.10 | 75R | https://www.digikey.com/en/products/detail/stackpole-electronics-inc/RMCF0805FT71R5/1760525
R18,R19,R20 | RMCF0805FT160R | 3 | $0.10 | $0.30 | 165R | https://www.digikey.com/en/products/detail/stackpole-electronics-inc/RMCF0805FT160R/1712729
R1,R5,R7,R32,R34 | RNCF0805BTE100K | 5 | $0.12 | $0.60 | 100k (0.1%) | https://www.digikey.com/en/products/detail/stackpole-electronics-inc/RNCF0805BTE100K/1710369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
R4 | RNCF0805DTE560K | 1 | $0.10 | $0.10 | 560k (0.5%) | https://www.digikey.com/en/products/detail/stackpole-electronics-inc/RNCF0805DTE560K/6242075
R6 | RNCF0805DTE910K | 1 | $0.10 | $0.10 | 910k (0.5%) | https://www.digikey.com/en/products/detail/stackpole-electronics-inc/RNCF0805DTE910K/6242097
R29 | RMCF0805FT4M70 | 1 | $0.10 | $0.10 | 4.7M | https://www.digikey.com/en/products/detail/stackpole-electronics-inc/RMCF0805FT4M70/1713118
R30 | RMCF0805FT3K00 | 1 | $0.10 | $0.10 | 3k | https://www.digikey.com/en/products/detail/stackpole-electronics-inc/RMCF0805FT3K00/1713084
C1,C2 | CL21A226MAYNNNE | 2 | $0.11 | $0.22 | 22uF | https://www.digikey.com/en/products/detail/samsung-electro-mechanics/CL21A226MAYNNNE/10479857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
C8,C9,C10,C11,C12,C15,C17,C22,C25,C26,C27,C28,C29,C30,C31,C32,C33,C34,C39,C40,C41,C42,C43,C44,C45,C46,C47 | KGM21NR71E104KT | 27 | $0.01 | $0.22 | 100n | https://www.digikey.com/en/products/detail/kyocera-avx/KGM21NR71E104KT/1116281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
C13,C20,C21,C23,C24 | CL21A475KPFNNNE | 5 | $0.05 | $0.24 | 4.7u (qty > 10) | https://www.digikey.com/en/products/detail/samsung-electro-mechanics/CL21A475KPFNNNE/3886917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
C18,C19 | GMC21CG150J50NT | 2 | $0.03 | $0.07 | 15p (qty > 10) | https://www.digikey.com/en/products/detail/cal-chip-electronics-inc/GMC21CG150J50NT/22256323
C35 | C0805C222K5RACTU | 1 | $0.10 | $0.10 | 2.2n | https://www.digikey.com/en/products/detail/kemet/C0805C222K5RACTU/411150
C36 | CL21B105KAFNNNE | 1 | $0.08 | $0.08 | 1u | https://www.digikey.com/en/products/detail/samsung-electro-mechanics/CL21B105KAFNNNE/3886724
C37,C38,C48 | GRM31CR61A107MEA8K | 3 | $0.30 | $0.90 | 100u (qty > 10) | https://www.digikey.com/en/products/detail/murata-electronics/GRM31CR61A107MEA8K/16286003
C4,C6 | GRM31CR61A476ME15L | 2 | $0.38 | $0.76 | 47uF | https://www.digikey.com/en/products/detail/murata-electronics/GRM31CR61A476ME15L/2334879
C3 | CC0805CRNPO9BN4R0 | 1 | $0.11 | $0.11 | 4p | https://www.digikey.com/en/products/detail/yageo/CC0805CRNPO9BN4R0/302827
C5 | CC0805CRNPO9BN2R4 | 1 | $0.11 | $0.11 | 2.4p | https://www.digikey.com/en/products/detail/yageo/CC0805CRNPO9BN2R4/5883895
Components Subtotal |  |  |  | $5.74
Integrated Modules
Reference | MFG P/N | Qty/Board | Unit Cost | Ext. Cost | Description | Digikey Link
U4 | Core1262 HF | 1 | $7.99 | $7.99 | LoRa Modulator | https://www.waveshare.com/core1262-868m.htm
Integrated Modules Subtotal |  |  |  | $7.99
TOTAL |  |  |  | $46.77

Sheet: Purchasing List
Reference | MFG P/N | Qty/Board | Unit Cost | Ext. Cost | Description | Digikey Link
J1, J4, J5 | OQ0332510000G | 3 | $0.37 | $1.11 | 3 Pin Connector, 3.81mm pitch | https://www.digikey.com/en/products/detail/amphenol-anytek/OQ0332510000G/2261261
J2 | OQ0232510000G | 1 | $0.27 | $0.27 | 2 Pin Connector, 3.81mm pitch | https://www.digikey.com/en/products/detail/amphenol-anytek/OQ0232510000G/2261255
J3 | CONBNC002 | 1 | $2.05 | $2.05 | BNC connector | https://www.digikey.com/en/products/detail/amphenol-rf/031-5431-10RFX/2041816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
N/A | TJ0331530000G | 3 | $0.97 | $2.91 | Mating connector for OQ0332510000G | https://www.digikey.com/en/products/detail/amphenol-anytek/TJ0331530000G/2261322
N/A | TJ0231530000G | 1 | $0.67 | $0.67 | Mating connector for OQ0232510000G | https://www.digikey.com/en/products/detail/amphenol-anytek/TJ0231530000G/2261289
J7 | UJ2-BH-BL1-TH | 1 | $0.51 | $0.51 | USB Type B Female Connector | https://www.digikey.com/en/products/detail/same-sky-formerly-cui-devices/UJ2-BH-BL1-TH/6188083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
J8 | SMA-J-P-H-RA-TH1 | 1 | $3.43 | $3.43 | SMA antenna connector | https://www.digikey.com/en/products/detail/samtec-inc/SMA-J-P-H-RA-TH1/2664715
U6 | MCP3425A0T-E/CH | 1 | $2.48 | $2.48 | 16 Bit A/D with I2C Interface | https://www.digikey.com/en/products/detail/microchip-technology/MCP3425A0T-E-CH/1827893
U7 | W25Q128JVSIQ TR | 1 | $1.85 | $1.85 | 128MBit QSPI Program Memory | https://www.digikey.com/en/products/detail/winbond-electronics/W25Q128JVSIQ/5803943
U8 | RP2350_60QFN | 1 | $1.10 | $1.10 | Microcontroller | https://www.digikey.com/en/products/detail/raspberry-pi/SC1509-13/26241107
U9,U10 | TPS63000DRCR | 2 | $2.61 | $5.22 | 1.6A Buck-Boost Converter | https://www.digikey.com/en/products/detail/texas-instruments/TPS63000DRCR/1016474
U11 | TL082CDR | 1 | $0.35 | $0.35 | JFET Input Op-Amp x 2 | https://www.digikey.com/en/products/detail/texas-instruments/TL082CDR/276927
D4,D5 | B240AE-13 | 2 | $0.20 | $0.40 | Schottky Diode | https://www.digikey.com/en/products/detail/diodes-incorporated/B240AE-13/7352825
D1,D2,D3,D6,D8,D9,D10 | T5V0S5A-7 | 7 | $0.08 | $0.58 | 5V TVS | https://www.digikey.com/en/products/detail/diodes-incorporated/T5V0S5A-7/17840287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
D7 | T3V3S5A-7 | 1 | $0.15 | $0.15 | 3.3V TVS | https://www.digikey.com/en/products/detail/diodes-incorporated/T3V3S5A-7/17840278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
D12, D14, D15 | KT EELP41.12-S2U1-25-2X4Y-5-R18 | 3 | $0.16 | $0.48 | Green LED | https://www.digikey.com/en/products/detail/ams-osram-usa-inc/KT-EELP41-12-S2U1-25-2X4Y-5-R18/24765233
D13 | ESDARF02-1BU2CK | 1 | $0.13 | $0.13 | 3.3V 3GHz BW TVS Diode | https://www.digikey.com/en/products/detail/stmicroelectronics/ESDARF02-1BU2CK/5768407
D11 | KR EELP41.22-Q1S1-36-A8J8-020-R18 | 1 | $0.14 | $0.14 | Red LED | https://www.digikey.com/en/products/detail/ams-osram-usa-inc/KR-EELP41-22-Q1S1-36-A8J8-020-R18/24765238
Y1 | ABM8-272-T3 | 1 | $0.54 | $0.54 | 12MHz XTAL Oscillator | https://www.digikey.com/en/products/detail/abracon-llc/ABM8-272-T3/22472366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
L3, L4 | LQH3NPZ2R2MMEL | 2 | $0.34 | $0.68 | Buck-Boost Converter Inductor | https://www.digikey.com/en/products/detail/murata-electronics/LQH3NPZ2R2MMEL/6799398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
L2 | AOTA-B201610S3R3-101-T | 1 | $0.22 | $0.22 | RP2350 DC-DC Inductor with Guaranteed Winding Direction | https://www.digikey.com/en/products/detail/abracon-llc/AOTA-B201610S3R3-101-T/25621527
R8,R27,R28,R45 | RNCF0805DTE100R | 4 | $0.10 | $0.40 | 100R (0.5%) | https://www.digikey.com/en/products/detail/stackpole-electronics-inc/RNCF0805DTE100R/1708180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
L1, R2 | RMCF0805ZT0R00 | 2 | $0.01 | $0.02 | Jumper (qty 10. cheaper than qty. 1) | https://www.digikey.com/en/products/detail/stackpole-electronics-inc/RMCF0805ZT0R00/1756901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
R12 | RMCF0805FT200K | 1 | $0.10 | $0.10 | 200k | https://www.digikey.com/en/products/detail/stackpole-electronics-inc/RMCF0805FT200K/1760341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
R11,R15,R16,R22,R35,R36,R37,R38,R39,R40,R41,R42,R43,R44 | RNCF0805DTE10K0 | 14 | $0.03 | $0.38 | 10k (0.5%) | https://www.digikey.com/en/products/detail/stackpole-electronics-inc/RNCF0805DTE10K0/1708247
R21,R24,R31,R9,R10,R13,R14 | RMCF0805FT1K00 | 7 | $0.02 | $0.14 | 1k | https://www.digikey.com/en/products/detail/stackpole-electronics-inc/RMCF0805FT1K00/1760090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
R23 | RMCF0805FT33R0 | 1 | $0.10 | $0.10 | 33R | https://www.digikey.com/en/products/detail/stackpole-electronics-inc/RMCF0805FT33R0/1760586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
R3 | RMCF0805FT4K70 | 1 | $0.10 | $0.10 | 4.7k | https://www.digikey.com/en/products/detail/stackpole-electronics-inc/RMCF0805FT4K70/1760659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
R25,R26 | RMCF0805FT27R0 | 2 | $0.10 | $0.20 | 27R | https://www.digikey.com/en/products/detail/stackpole-electronics-inc/RMCF0805FT27R0/1712920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
R17 | RMCF0805FT71R5 | 1 | $0.10 | $0.10 | 70R | https://www.digikey.com/en/products/detail/stackpole-electronics-inc/RMCF0805FT71R5/1760525
R18,R19,R20 | RMCF0805FT160R | 3 | $0.10 | $0.30 | 160R | https://www.digikey.com/en/products/detail/stackpole-electronics-inc/RMCF0805FT160R/1712729
R1,R5,R7 | RNCF0805BTE100K | 3 | $0.12 | $0.36 | 100k (0.1%) | https://www.digikey.com/en/products/detail/stackpole-electronics-inc/RNCF0805BTE100K/1710369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
R4 | RNCF0805DTE560K | 1 | $0.10 | $0.10 | 560k (0.5%) | https://www.digikey.com/en/products/detail/stackpole-electronics-inc/RNCF0805DTE560K/6242075
R6 | RNCF0805DTE910K | 1 | $0.10 | $0.10 | 910k (0.5%) | https://www.digikey.com/en/products/detail/stackpole-electronics-inc/RNCF0805DTE910K/6242097
R29 | RMCF0805FT4M70 | 1 | $0.10 | $0.10 | 4.7M | https://www.digikey.com/en/products/detail/stackpole-electronics-inc/RMCF0805FT4M70/1713118
R30 | RMCF0805FT3K00 | 1 | $0.10 | $0.10 | 3k | https://www.digikey.com/en/products/detail/stackpole-electronics-inc/RMCF0805FT3K00/1713084
R32,R34 | RNCF0805DTE30K0 | 2 | $0.10 | $0.20 | 30k | https://www.digikey.com/en/products/detail/stackpole-electronics-inc/RNCF0805DTE30K0/6241935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
R33 | RMCF0805FT59K0 | 1 | $0.10 | $0.10 | 59k | https://www.digikey.com/en/products/detail/stackpole-electronics-inc/RMCF0805FT59K0/1760440
C1,C2 | CL21A226MAYNNNE | 2 | $0.11 | $0.22 | 22uF | https://www.digikey.com/en/products/detail/samsung-electro-mechanics/CL21A226MAYNNNE/10479857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
C8,C9,C10,C11,C12,C15,C17,C22,C25,C26,C27,C28,C29,C30,C31,C32,C33,C34,C39,C40,C41,C42,C43,C44,C45,C46,C47 | KGM21NR71E104KT | 27 | $0.01 | $0.22 | 100n | https://www.digikey.com/en/products/detail/kyocera-avx/KGM21NR71E104KT/1116281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
C13,C20,C21,C23,C24 | CL21A475KPFNNNE | 5 | $0.05 | $0.24 | 4.7u (qty > 10) | https://www.digikey.com/en/products/detail/samsung-electro-mechanics/CL21A475KPFNNNE/3886917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
C18,C19 | GMC21CG150J50NT | 2 | $0.03 | $0.07 | 15p (qty > 10) | https://www.digikey.com/en/products/detail/cal-chip-electronics-inc/GMC21CG150J50NT/22256323
C35 | C0805C222K5RACTU | 1 | $0.10 | $0.10 | 2.2n | https://www.digikey.com/en/products/detail/kemet/C0805C222K5RACTU/411150
C36 | CL21B105KAFNNNE | 1 | $0.08 | $0.08 | 1u | https://www.digikey.com/en/products/detail/samsung-electro-mechanics/CL21B105KAFNNNE/3886724
C37,C38,C48 | GRM31CR61A107MEA8K | 3 | $0.30 | $0.90 | 100u (qty > 10) | https://www.digikey.com/en/products/detail/murata-electronics/GRM31CR61A107MEA8K/16286003
C4,C6 | GRM31CR61A476ME15L | 2 | $0.38 | $0.76 | 47uF | https://www.digikey.com/en/products/detail/murata-electronics/GRM31CR61A476ME15L/2334879
C3 | CC0805CRNPO9BN4R0 | 1 | $0.11 | $0.11 | 4p | https://www.digikey.com/en/products/detail/yageo/CC0805CRNPO9BN4R0/302827
C5 | CC0805CRNPO9BN2R4 | 1 | $0.11 | $0.11 | 2.4p | https://www.digikey.com/en/products/detail/yageo/CC0805CRNPO9BN2R4/5883895

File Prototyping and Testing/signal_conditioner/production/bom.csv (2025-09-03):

Designator | Footprint | Quantity | Value | LCSC Part #
J1, J2 | PinHeader_1x04_P2.54mm_Vertical | 2 | Conn_01x04_Pin
J3, J4 | PinHeader_1x03_P2.54mm_Vertical | 2 | Conn_01x03_Pin
J5, J6, J7 | PinHeader_1x02_P2.54mm_Vertical | 3 | Conn_01x02_Pin
R1, R2, R4, R5 | 0805 | 4 | 4k
R10, R11, R12, R13, R14, R15, R6, R7, R8, R9 | 0805 | 10 | 10k
R3 | 0805 | 1 | 200k
TP3, TP4, TP5 | TestPoint_Pad_D1.5mm | 3 | TestPoint_Small
U1 | (S)SOP16 | 1 | TMUX1309
U2 | (S)SOP8 | 1 | LSF0102
U3 | (S)SOP14 | 1 | LMV324
U4, U5 | (S)SOP14 | 2 | MCP4651T-503E_ST

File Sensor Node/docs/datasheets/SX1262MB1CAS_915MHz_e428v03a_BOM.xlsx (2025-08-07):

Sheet: SX1262MB1CAS
 |  |  | SX1262MB1CAS RF Module - 4-Layers 915MHz BOM |  |  | BOM # V1a
 |  |  |  |  |  | SCH # e428v03a
 |  |  | 2023-09-25 | EMr | Version e428v03a | PCB # e428v03a
RefDes | MPN | Geom | Value | Qty | Description | Manufacturer
U1 | SX1262IMLTRT | VQFN24 4x4mm | SX1262 | 1 | 150MHz to 960MHz Low Power Long Range Transceiver | Semtech
U2 | PE4259 | SC70-6 | PE4259 | 1 | SPDT High Power UltraCMOS 10 MHz - 3.0 GHz RF Switch | Peregrine
Resistors
R2 | CRCW06030000Z0EAHP | 0603 | 0R | 1 | Thick Film Resistor ±1%, 1/4W | Vishay/Dale
R3 | CRCW0402100RFKED | 0402 | 100R | 1 | Thick Film Resistor ±1%, 1/16W | Vishay/Dale
R4 | CRCW0402100RFKED | 0402 | 100R | 1 | Thick Film Resistor ±1%, 1/16W | Vishay/Dale
R12 | CRCW04020000Z0ED | 0402 | 0R | 1 | Thick Film Resistor ±1%, 1/16W | Vishay/Dale
R13 | CRCW040210K0FKED | 0402 | 10k | 1 | Thick Film Resistor ±1%, 1/16W | Vishay/Dale
R15 | CRCW0402330RFKED | 0402 | 330R | 1 | Thick Film Resistor ±1%, 1/16W | Vishay/Dale
R16 | CRCW0402330RFKED | 0402 | 330R | 1 | Thick Film Resistor ±1%, 1/16W | Vishay/Dale
R915 | CRCW04020000Z0ED | 0402 | 0R | 1 | Thick Film Resistor ±1%, 1/16W | Vishay/Dale
SX1262 | CRCW040210K0FKED | 0402 | 10k | 1 | Thick Film Resistor ±1%, 1/16W | Vishay/Dale
FR1 | CRCW040210K0FKED | 0402 | 10k | 1 | Thick Film Resistor ±1%, 1/16W | Vishay/Dale
XTAL | CRCW04020000Z0ED | 0402 | 0R | 1 | Thick Film Resistor ±1%, 1/16W | Vishay/Dale
Capacitors
C1 | GRM155R71C473KA01D | 0402 | 47nF | 1 | Multilayer ceramic capacitors X7R ±10%, 16V | Murata
C2 | GJM1555C1H470JB01D | 0402 | 47pF | 1 | Multilayer ceramic capacitors C0G ±5%, 50V | Murata
C4 | GJM1555C1H3R0BB01D | 0402 | 3.0pF | 1 | Multilayer ceramic capacitors C0G ±0.1pF, 50V | Murata
C5 | GJM1555C1H5R6CB01D | 0402 | 5.6pF | 1 | Multilayer ceramic capacitors C0G ±0.25pF, 50V | Murata
C6 | GJM1555C1H390JB01D | 0402 | 39pF | 1 | Multilayer ceramic capacitors C0G ±5%, 50V | Murata
C7 | GJM1555C1H1R8BB01D | 0402 | 1.8pF | 1 | Multilayer ceramic capacitors C0G ±0.1pF, 50V | Murata
C8 | GJM1555C1H390JB01D | 0402 | 39pF | 1 | Multilayer ceramic capacitors C0G ±5%, 50V | Murata
C9 | GJM1555C1H3R3BB01D | 0402 | 3.3pF | 1 | Multilayer ceramic capacitors C0G ±0.1pF, 50V | Murata
C10 | GJM1555C1H3R3BB01D | 0402 | 3.3pF | 1 | Multilayer ceramic capacitors C0G ±0.1pF, 50V | Murata
C11 | GJM1555C1H2R4BB01D | 0402 | 2.4pF | 1 | Multilayer ceramic capacitors C0G ±0.1pF, 50V | Murata
C12 | GJM1555C1H1R8BB01D | 0402 | 1.8pF | 1 | Multilayer ceramic capacitors C0G ±0.1pF, 50V | Murata
C14 | GRM155R72A102KA01D | 0402 | 1nF | 1 | Multilayer ceramic capacitors X7R ±10%, 100V | Murata
C15 | GRM155R72A102KA01D | 0402 | 1nF | 1 | Multilayer ceramic capacitors X7R ±10%, 100V | Murata
C16 | GRM155R61C105KA12D | 0402 | 1uF | 1 | Multilayer ceramic capacitors X5R ±10%, 16V | Murata
C17 | GRM155R71A474KE01D | 0402 | 470nF | 1 | Multilayer ceramic capacitors X7R ±10%, 10V | Murata
C18 | GRM155R71H104KE14D | 0402 | 100nF | 1 | Multilayer ceramic capacitors X7R ±10%, 50V | Murata
C20 | GRM155R61C105KA12D | 0402 (0603) | 1uF | 1 | Multilayer ceramic capacitors X5R ±10%, 16V | Murata
C21 | GRM155R61C105KA12D | 0402 (0603) | 1uF | 1 | Multilayer ceramic capacitors X5R ±10%, 16V | Murata
C22 | GRM188Z71A106KA73D | 0603 (0805) | 10uF | 1 | Multilayer ceramic capacitors X7R ±10%, 10V | Murata
C23 | GRM155R71C104KA88D | 0402 | 100nF | 1 | Multilayer ceramic capacitors X7R ±10%, 16V | Murata
C24 | GRM155R61C105KA12D | 0402 (0603) | 1uF | 1 | Multilayer ceramic capacitors X5R ±10%, 16V | Murata
C26 | GRM188Z71A106KA73D | 0603 (0805) | 10uF | 1 | Multilayer ceramic capacitors X7R ±10%, 10V | Murata
Inductors & Ferrites
L1 | LQW15AN47NJ00D | 0402 | 47nH | 1 | Wirewound Inductor ±5% | Murata
L2 | CRCW04020000Z0ED | 0402 | 0R | 1 | Thick Film Resistor ±1%, 1/16W | Vishay/Dale
L3 | LQW15AN2N5C00D | 0402 | 2.5nH | 1 | Wirewound Inductor ±0.2nH | Murata
L4 | LQW15AN4N7C00D | 0402 | 4.7nH | 1 | Wirewound Inductor ±0.2nH | Murata
L5 | LQW15AN9N1H00D | 0402 | 9.1nH | 1 | Wirewound Inductor ±3% | Murata
L6 | LQW15AN15NH00D | 0402 | 15nH | 1 | Wirewound Inductor ±3% | Murata
L7 | MLZ2012M150W | 0805 | 15uH | 1 | MLZ2012 Multilayer Shielded Inductor ±20% (populated) | TDK
or | MLZ1608N100LT000 | 0603 (0805) | 10uH | - | MLZ1608 Multilayer Shielded Inductor ±20% (recommended for new design) | TDK
or | MLZ1608N150LT000 | 0603 (0805) | 15uH | - | MLZ1608 Multilayer Shielded Inductor ±20% (recommended for new design) | TDK
LEDs and Diodes
Rx | LTST-C193KGKT-5A | SMT 1.6x0.8mm | GREEN | 1 | SMD LED 20mA or equivalent LED type | Lite ON
Tx | LTST-C193KRKT-5A | SMT 1.6x0.8mm | RED | 1 | SMD LED 20mA or equivalent LED type | Lite ON
Crystal & TCXO
Q1 | EXS00A-CS06465 | NX2016SA 2.0x1.6mm | 32.000MHz | 1 | Crystal unit NDK; Tol. ±10ppm, Cload=10pF, G-Senstivity=2ppb/G max | NDK
or | FTR5123-B0 | QESM09 2.0x1.6mm | 32.000MHz | - | Crystal unit Rakon; Tol. ±10ppm, Cload=10pF, G-Senstivity=2ppb/G max | Rakon
Connectors and others (or P/N equivalent)
RFIO | 142-0701-841 | SMA End Launch | 50 Ohms | 1 | SMA End launch jack receptacle for PCB mount | Cinch Connectivity Sol Johnson
J1 | 68000-108HLF | Header 1x8 | 8 pins | 1 | 8 Pins - Through hole single row male connector, Bottom side | FCI
J2 | 68000-110HLF | Header 1x10 | 10 pins | 1 | 10 Pins - Through hole single row male connector, Bottom side | FCI
J3 | 68000-108HLF | Header 1x8 | 8 pins | 1 | 8 Pins - Through hole single row male connector, Bottom side | FCI
J4 | 68000-106HLF | Header 1x6 | 6 pins | 1 | 6 Pins - Through hole single row male connector, Bottom side | FCI
J1_DISP | 75915-308LF | Receptacle 1x8 | 8 pins | 1 | 8 Pins - Through hole single row female receptacle, Top side | FCI
J2_DISP | 75915-310LF | Receptacle 1x10 | 10 pins | 1 | 10 Pins - Through hole single row female receptacle, Top side | FCI
J3_DISP | 75915-308LF | Receptacle 1x8 | 8 pins | 1 | 8 Pins - Through hole single row female receptacle, Top side | FCI
J4_DISP | 75915-306LF | Receptacle 1x6 | 6 pins | 1 | 6 Pins - Through hole single row female receptacle, Top side | FCI
VDD_RADIO | 68000-102HLF | Bridge 2p 2.54mm | 2 pins | 1 | 2 Pins - Through hole single row male connector, Top side | FCI
Additional components
- | M7566-05 | Jumper 2.54mm | - | 1 | Red Jumper Socket 2.54mm on VDD_RADIO for DC supply or equivalent | Harwin
- | BMI-S-209-F | Shield | - | 0 | Standard Surface Mount Shield in two parts with BMI-S-209-C cover (optional) | Laird Technologies
Remarks: components not listed in the BOM or 0 quantity, are not populated on the module.
It is recommended to use Semtech TVS diode model RClamp2451ZA placed close to the antenna connectors, to protect sensitive RF ports from damage or latch-up due to ESD, EFT, and EOS.
Murata GRM15 Multilayer ceramic capacitors series with values ≤ 47pF were replaced from previous BOM to new GJM15 series, as replacement with same capacitance value, voltage rating and tolerance.
GRM15 series ≤ 47pF are not recommended for new designs according to Murata.

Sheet: Release
 |  | SX1262MB1CAS RF Module - 4-Layers 915MHz BOM |  |  |  | BOM # V1a
 |  |  |  |  |  | SCH # e428v03a
 |  | 2023-09-25 | EMr | Version e428v03a |  | PCB # e428v03a
Release history
Version | Change notes |  |  |  | By
pcb_e428v03a | Based on PCB_E407V0xA version - SX1262 module - 4-layers with thermal reliefs |  |  |  | EMr
 | Updated BOM @915MHz
 | Updated Part Number and comment only, removed shield - 12.03.18 |  |  |  | EMr
 | Updated obsolete P/N for large capacitor values (>1.0uF) |  |  |  | EMr
 | Updated GJM capacitor type |  |  |  | 2023-09-25

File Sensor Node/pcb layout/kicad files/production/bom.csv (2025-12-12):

Designator | Footprint | Quantity | Value | LCSC Part #
A1 | RaspberryPi_Pico_Common_Unspecified | 1 | RaspberryPi_Pico
C1, C2 | 0805 | 2 | 22uF
C10, C11, C12, C15, C17, C22, C25, C26, C27, C28, C29, C30, C31, C32, C33, C34, C39, C40, C41, C42, C43, C44, C45, C46, C47, C8, C9 | 0805 | 27 | 100n
C14, C16 | 0402 | 2 | C
C18, C19 | 0805 | 2 | 15p
C20, C21, C23, C24, C7 | 0805 | 5 | 4.7u
C3 | 0805 | 1 | 4p
C35 | 0805 | 1 | 2.2n
C36 | 0805 | 1 | 1u
C37, C38, C48 | 1206 | 3 | 100u
C4, C6 | 1206 | 2 | 47uF
C5 | 0805 | 1 | 2.4p
D1, D10, D2, D3, D6, D8, D9 | D_SOD-523 | 7 | T5V0S5A-7
D11, D12, D14, D15 | 0603 | 4 | LED
D13 | 0201 | 1 | ESDARF02-1BU2CK
D4, D5 | D_SMA_Handsoldering | 2 | B240AE-13
D7 | D_SOD-523 | 1 | T3V3S5A-7
J1, J4, J5 | OQ0332510000G | 3 | OQ0332510000G
J10 | PinHeader_1x03_P2.54mm_Vertical | 1 | Conn_01x03
J2 | OQ0232510000G | 1 | OQ0232510000G
J3 | LINX_CONBNC002 | 1 | CONBNC002
J6, J9 | PinHeader_1x02_P2.54mm_Vertical | 2 | Conn_01x02
J7 | USB_B_Lumberg_2411_02_Horizontal | 1 | USB_B
J8 | SAMTEC_SMA-J-P-X-RA-TH1 | 1 | SMA-J-P-X-RA-TH1
L1 | 0402 | 1 | L
L2 | AOTA-B201610S3R3-101-T | 1 | 3.3u
L3, L4 | IND_LQH3NPZ2R2MMEL | 2 | 2.2uH
R1, R5, R7 | 0805 | 3 | 100k
R10, R13, R14, R21, R24, R31, R9 | 0805 | 7 | 1k
R11, R15, R16, R22, R35, R36, R37, R38, R39, R40, R41, R42, R43, R44 | 0805 | 14 | 10k
R12 | 0805 | 1 | 200k
R17 | 0805 | 1 | 75R
R18, R19, R20 | 0805 | 3 | 165R
R2 | 0805 | 1 | 0R
R23 | 0805 | 1 | 33R
R25, R26 | 0805 | 2 | 27R
R27, R28, R45, R8 | 0805 | 4 | 100R
R29 | 0805 | 1 | 4.7M
R3 | 0805 | 1 | 4.7k
R30 | 0805 | 1 | 3k
R32, R34 | 0805 | 2 | 30k
R33 | 0805 | 1 | 60k
R4 | 0805 | 1 | 560k
R6 | 0805 | 1 | 910k
SW1 | SW4_1825910-B_TEC | 1 | Tactile Pushbutton
TP1, TP10, TP11, TP12, TP13, TP14, TP2, TP3, TP4, TP5, TP6, TP7, TP8, TP9 | TestPoint_Pad_D1.5mm | 14 | TestPoint
TP15, TP16, TP17, TP18 | TestPoint_Pad_D1.5mm | 4 | TestPoint_Small
U10, U9 | CONV_TPS63000DRCR | 2 | TPS63000
U11 | SOIC_208MIL_WIN-M | 1 | TL082
U12 | SOIC_208MIL_WIN-M | 1 | LM2660MX
U13, U15, U16 | TSSOP-14_4.4x5mm_P0.65mm | 3 | MCP4651T-503E_ST
U14 | TSSOP-14_4.4x5mm_P0.65mm | 1 | LMV324
U2 | TSSOP-16_4.4x5mm_P0.65mm | 1 | TMUX1309
U3 | TSSOP-8_3x3mm_P0.65mm | 1 | LSF0102
U4 | Core1262 | 1 | Core1262 HF
U5 | SOIC127P790X216-8N | 1 | MX25L3233FM2I-08Q
U6 | SOT-23-6 | 1 | MCP3425Axx-xCH
U7 | SOIC_208MIL_WIN-M | 1 | W25Q128JVSIQ TR
U8 | RP2350-QFN-60-1EP_7x7_P0.4mm_EP3.4x3.4mm_ThermalVias | 1 | RP2350_60QFN
Y1 | ABM8-272-T3 | 1 | ABM8-272-T3

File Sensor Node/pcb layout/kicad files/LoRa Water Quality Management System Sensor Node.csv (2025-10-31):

Reference | Qty | Value | DNP | Exclude from BOM | Exclude from Board | Footprint | Datasheet
A1 | 1 | RaspberryPi_Pico |  |  |  | Module:RaspberryPi_Pico_Common_Unspecified | https://datasheets.raspberrypi.com/pico/pico-datasheet.pdf
C1,C2 | 2 | 22uF |  |  |  | Capacitor_SMD:C_0805_2012Metric_Pad1.18x1.45mm_HandSolder | ~
C3 | 1 | 4p |  |  |  | Capacitor_SMD:C_0805_2012Metric_Pad1.18x1.45mm_HandSolder | ~
C4,C6 | 2 | 47uF |  |  |  | Capacitor_SMD:C_1206_3216Metric_Pad1.33x1.80mm_HandSolder | ~
C5 | 1 | 2.4p |  |  |  | Capacitor_SMD:C_0805_2012Metric_Pad1.18x1.45mm_HandSolder | ~
C7,C20,C21,C23,C24 | 5 | 4.7u |  |  |  | Capacitor_SMD:C_0805_2012Metric_Pad1.18x1.45mm_HandSolder | ~
C8,C9,C10,C11,C12,C15,C17,C22,C25,C26,C27,C28,C29,C30,C31,C32,C33,C34,C39,C40,C41,C42,C43,C44,C45,C46,C47 | 27 | 100n |  |  |  | Capacitor_SMD:C_0805_2012Metric_Pad1.18x1.45mm_HandSolder | ~
C14,C16 | 2 | C |  |  |  | Capacitor_SMD:C_0402_1005Metric_Pad0.74x0.62mm_HandSolder | ~
C18,C19 | 2 | 15p |  |  |  | Capacitor_SMD:C_0805_2012Metric_Pad1.18x1.45mm_HandSolder | ~
C35 | 1 | 2.2n |  |  |  | Capacitor_SMD:C_0805_2012Metric_Pad1.18x1.45mm_HandSolder | ~
C36 | 1 | 1u |  |  |  | Capacitor_SMD:C_0805_2012Metric_Pad1.18x1.45mm_HandSolder | ~
C37,C38,C48 | 3 | 100u |  |  |  | Capacitor_SMD:C_1206_3216Metric_Pad1.33x1.80mm_HandSolder | ~
D1,D2,D3,D6,D8,D9,D10 | 7 | T5V0S5A-7 |  |  |  | Diode_SMD:D_SOD-523 | kicad-embed://T3V3S5A_T5V0S5A_T6V0S5A_T12S5A.pdf
D4,D5 | 2 | B240AE-13 |  |  |  | Diode_SMD:D_SMA_Handsoldering | http://www.jameco.com/Jameco/Products/ProdDS/1538777.pdf
D7 | 1 | T3V3S5A-7 |  |  |  | Diode_SMD:D_SOD-523 | kicad-embed://T3V3S5A_T5V0S5A_T6V0S5A_T12S5A.pdf
D11,D12,D14,D15 | 4 | LED |  |  |  | LED_SMD:LED_0603_1608Metric_Pad1.05x0.95mm_HandSolder | ~
D13 | 1 | ESDARF02-1BU2CK |  |  |  | Diode_SMD:D_0201_0603Metric_Pad0.64x0.40mm_HandSolder | kicad-embed://ESDARF02-1BU2CK.pdf
J1,J4,J5 | 3 | OQ0332510000G |  |  |  | LWQMS:OQ0332510000G | ~
J2 | 1 | OQ0232510000G |  |  |  | LWQMS:OQ0232510000G | ~
J3 | 1 | CONBNC002 |  |  |  | LWQMS:LINX_CONBNC002
J6,J9 | 2 | Conn_01x02 |  |  |  | Connector_PinHeader_2.54mm:PinHeader_1x02_P2.54mm_Vertical | ~
J7 | 1 | USB_B |  |  |  | Connector_USB:USB_B_Lumberg_2411_02_Horizontal | ~
J8 | 1 | SMA-J-P-X-RA-TH1 |  |  |  | LWQMS:SAMTEC_SMA-J-P-X-RA-TH1
J10 | 1 | Conn_01x03 |  |  |  | Connector_PinHeader_2.54mm:PinHeader_1x03_P2.54mm_Vertical | ~
L1 | 1 | L |  |  |  | Inductor_SMD:L_0402_1005Metric_Pad0.77x0.64mm_HandSolder | ~
L2 | 1 | 3.3u |  |  |  | LWQMS:AOTA-B201610S3R3-101-T | kicad-embed://AOTA-B201610S3R3-101-T.pdf
L3,L4 | 2 | 2.2uH |  |  |  | LWQMS:IND_LQH3NPZ2R2MMEL | ~
R1,R5,R7 | 3 | 100k |  |  |  | Resistor_SMD:R_0805_2012Metric_Pad1.20x1.40mm_HandSolder | ~
R2 | 1 | 0R | DNP |  |  | Resistor_SMD:R_0805_2012Metric_Pad1.20x1.40mm_HandSolder | ~
R3 | 1 | 4.7k |  |  |  | Resistor_SMD:R_0805_2012Metric_Pad1.20x1.40mm_HandSolder | ~
R4 | 1 | 560k |  |  |  | Resistor_SMD:R_0805_2012Metric_Pad1.20x1.40mm_HandSolder | ~
R6 | 1 | 910k |  |  |  | Resistor_SMD:R_0805_2012Metric_Pad1.20x1.40mm_HandSolder | ~
R8,R27,R28,R45 | 4 | 100R |  |  |  | Resistor_SMD:R_0805_2012Metric_Pad1.20x1.40mm_HandSolder | ~
R9,R10,R13,R14,R21,R24,R31 | 7 | 1k |  |  |  | Resistor_SMD:R_0805_2012Metric_Pad1.20x1.40mm_HandSolder | ~
R11,R15,R16,R22,R35,R36,R37,R38,R39,R40,R41,R42,R43,R44 | 14 | 10k |  |  |  | Resistor_SMD:R_0805_2012Metric_Pad1.20x1.40mm_HandSolder | ~
R12 | 1 | 200k |  |  |  | Resistor_SMD:R_0805_2012Metric_Pad1.20x1.40mm_HandSolder | ~
R17 | 1 | 75R |  |  |  | Resistor_SMD:R_0805_2012Metric_Pad1.20x1.40mm_HandSolder | ~
R18,R19,R20 | 3 | 165R |  |  |  | Resistor_SMD:R_0805_2012Metric_Pad1.20x1.40mm_HandSolder | ~
R23 | 1 | 33R |  |  |  | Resistor_SMD:R_0805_2012Metric_Pad1.20x1.40mm_HandSolder | ~
R25,R26 | 2 | 27R |  |  |  | Resistor_SMD:R_0805_2012Metric_Pad1.20x1.40mm_HandSolder | ~
R29 | 1 | 4.7M |  |  |  | Resistor_SMD:R_0805_2012Metric_Pad1.20x1.40mm_HandSolder | ~
R30 | 1 | 3k |  |  |  | Resistor_SMD:R_0805_2012Metric_Pad1.20x1.40mm_HandSolder | ~
R32,R34 | 2 | 30k |  |  |  | Resistor_SMD:R_0805_2012Metric_Pad1.20x1.40mm_HandSolder | ~
R33 | 1 | 60k |  |  |  | Resistor_SMD:R_0805_2012Metric_Pad1.20x1.40mm_HandSolder | ~
SW1 | 1 | Tactile Pushbutton |  |  |  | LWQMS:SW4_1825910-B_TEC
TP1,TP2,TP3,TP4,TP5,TP6,TP7,TP8,TP9,TP10,TP11,TP12,TP13,TP14 | 14 | TestPoint |  |  |  | TestPoint:TestPoint_Pad_D1.5mm | ~
TP15,TP16,TP17,TP18 | 4 | TestPoint_Small |  |  |  | TestPoint:TestPoint_Pad_D1.5mm | ~
U2 | 1 | TMUX1309 |  |  |  | Package_SO:TSSOP-16_4.4x5mm_P0.65mm | kicad-embed://tmux1309.pdf
U3 | 1 | LSF0102 |  |  |  | Package_SO:TSSOP-8_3x3mm_P0.65mm | kicad-embed://lsf0102.pdf
U4 | 1 | Core1262 HF |  |  |  | LWQMS:Core1262 | kicad-embed://SX1261-2.pdf
U5 | 1 | MX25L3233FM2I-08Q |  |  |  | LWQMS:SOIC127P790X216-8N | kicad-embed://MX25L3233F, 3V, 32Mb, v1.7.pdf
U6 | 1 | MCP3425Axx-xCH |  |  |  | Package_TO_SOT_SMD:SOT-23-6 | http://ww1.microchip.com/downloads/en/DeviceDoc/22072b.pdf
U7 | 1 | W25Q128JVSIQ TR |  |  |  | LWQMS:SOIC_208MIL_WIN-M | kicad-embed://256_W25Q128JV.pdf
U8 | 1 | RP2350_60QFN |  |  |  | LWQMS:RP2350-QFN-60-1EP_7x7_P0.4mm_EP3.4x3.4mm_ThermalVias | kicad-embed://rp2350-datasheet.pdf
U9,U10 | 2 | TPS63000 |  |  |  | LWQMS:CONV_TPS63000DRCR | http://www.ti.com/lit/ds/symlink/tps63000.pdf
U11 | 1 | TL082 |  |  |  | LWQMS:SOIC_208MIL_WIN-M | http://www.ti.com/lit/ds/symlink/tl081.pdf
U12 | 1 | LM2660MX |  |  |  | LWQMS:SOIC_208MIL_WIN-M
U13,U15,U16 | 3 | MCP4651T-503E_ST |  |  |  | Package_SO:TSSOP-14_4.4x5mm_P0.65mm
U14 | 1 | LMV324 |  |  |  | Package_SO:TSSOP-14_4.4x5mm_P0.65mm | http://www.ti.com/lit/ds/symlink/lmv324.pdf
Y1 | 1 | ABM8-272-T3 |  |  |  | LWQMS:ABM8-272-T3 | kicad-embed://ABM8_Datasheet.pdf

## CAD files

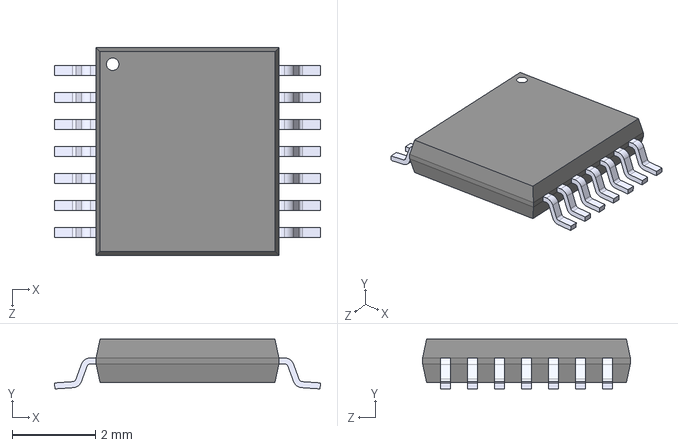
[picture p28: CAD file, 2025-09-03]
Sensor Node/pcb layout/models/MCP4651T-503E_ST.step
6.40 x 1.20 x 5.00 mm

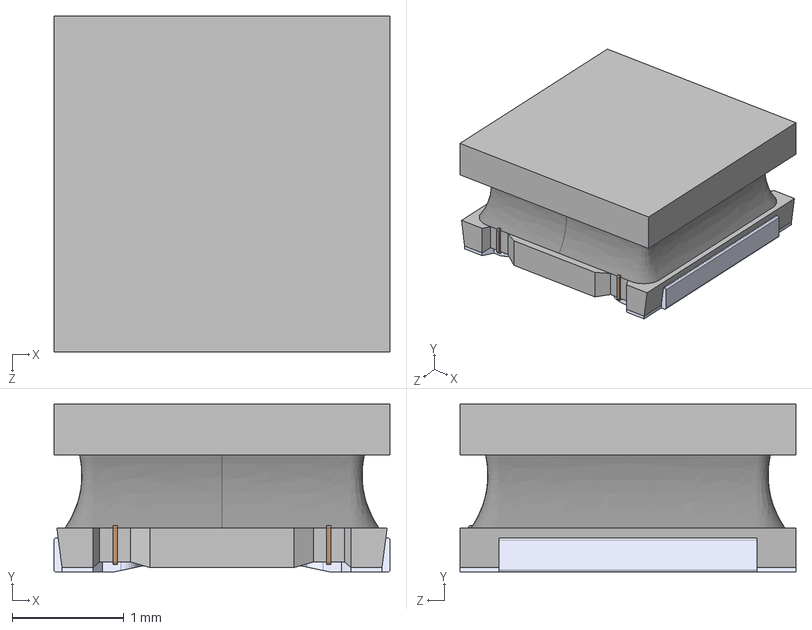
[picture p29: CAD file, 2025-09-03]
Sensor Node/pcb layout/models/LQH3NPZ2R2MMEL.step
3.00 x 1.50 x 3.00 mm

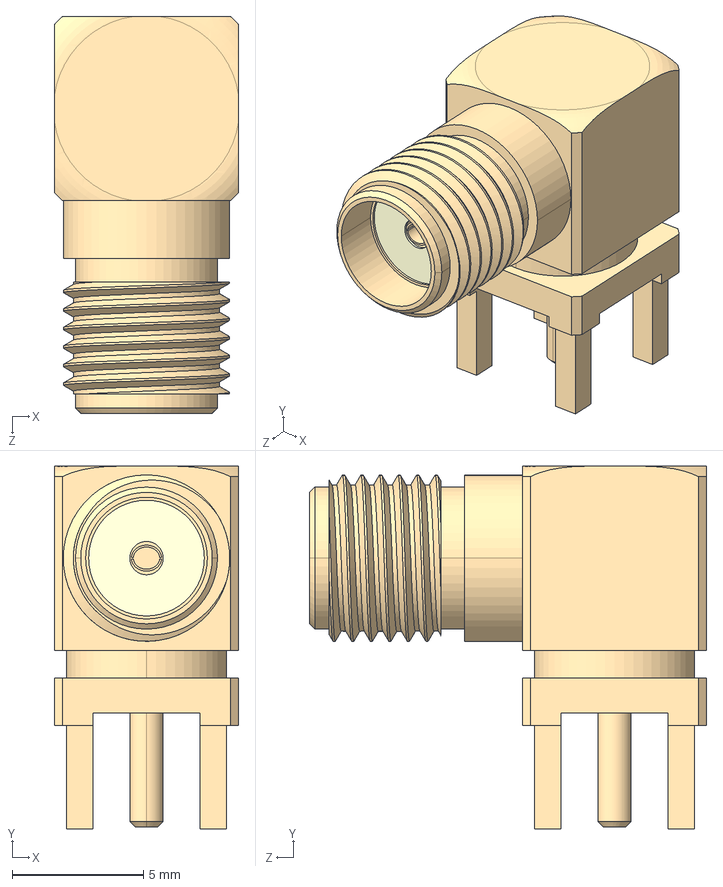
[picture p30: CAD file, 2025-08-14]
Sensor Node/pcb layout/models/SMA-J-P-X-RA-TH1.step
7.00 x 13.8 x 15.1 mm

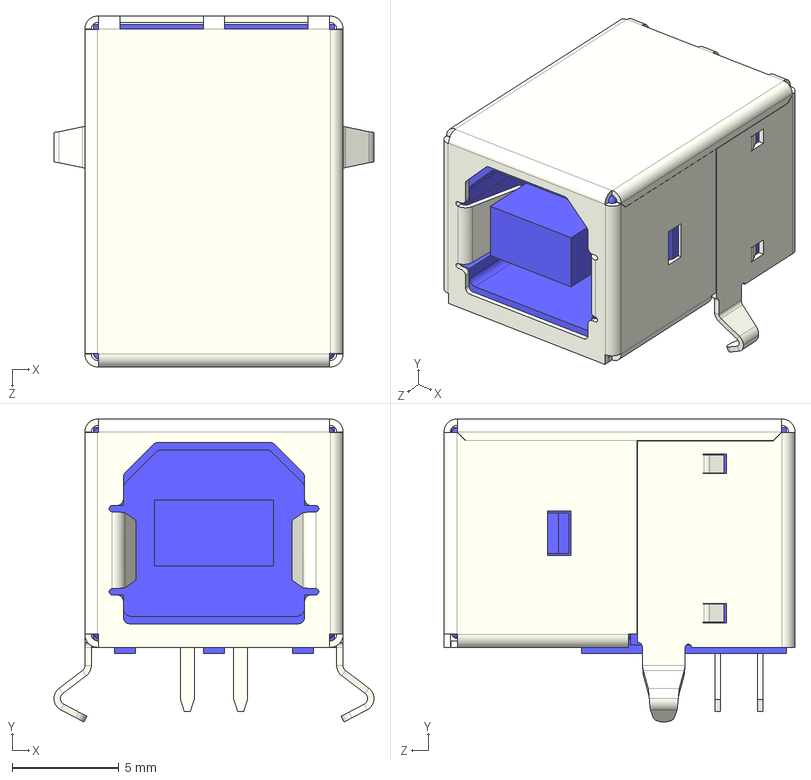
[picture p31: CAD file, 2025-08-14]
Sensor Node/pcb layout/models/Same_Sky_UJ2-BH-BL1-TH.step
15.0 x 14.2 x 16.5 mm

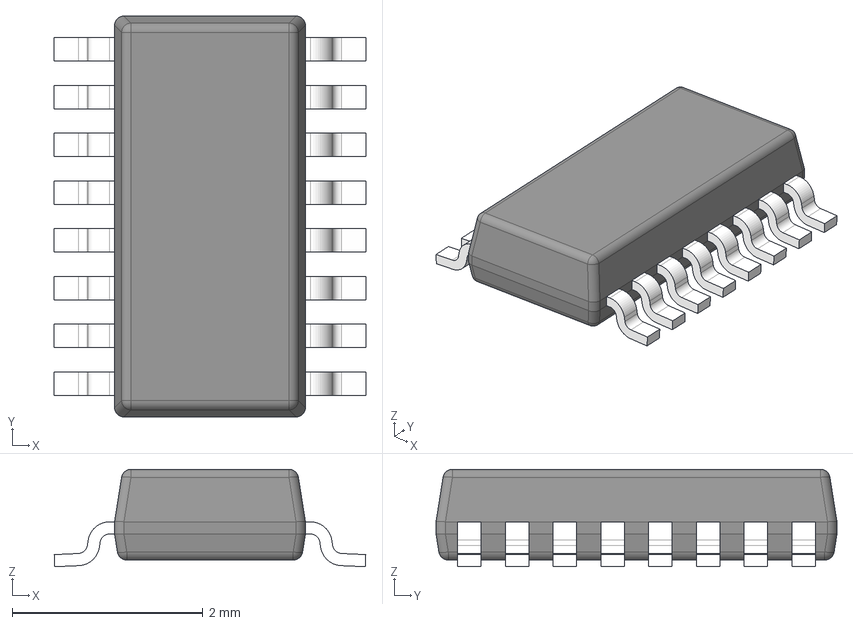
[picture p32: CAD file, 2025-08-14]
Sensor Node/pcb layout/models/DYY0016A.stp
3.26 x 4.20 x 1.02 mm
BODY-TSSOP
LEAD-TSSOP x 16

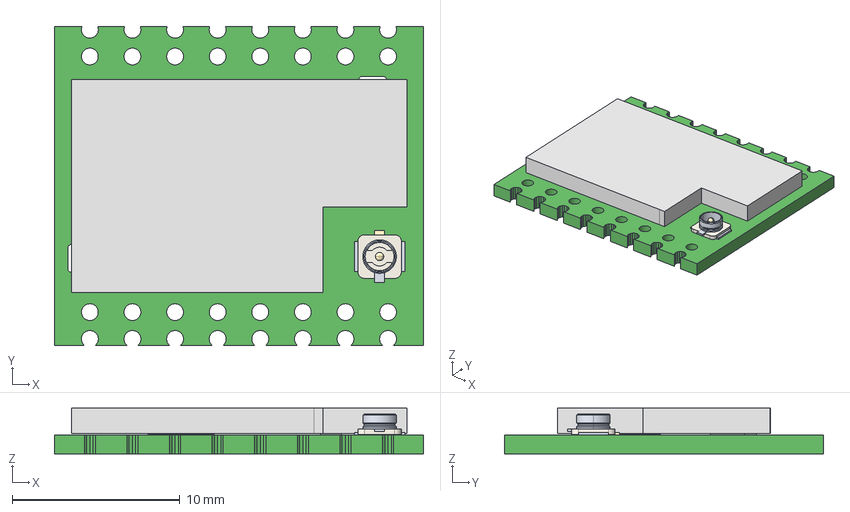
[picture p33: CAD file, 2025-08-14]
Sensor Node/pcb layout/models/Core126X.step
22.0 x 19.0 x 2.72 mm
Board
Extruded x 32
User_Library-U_FL-R-SMT(10)

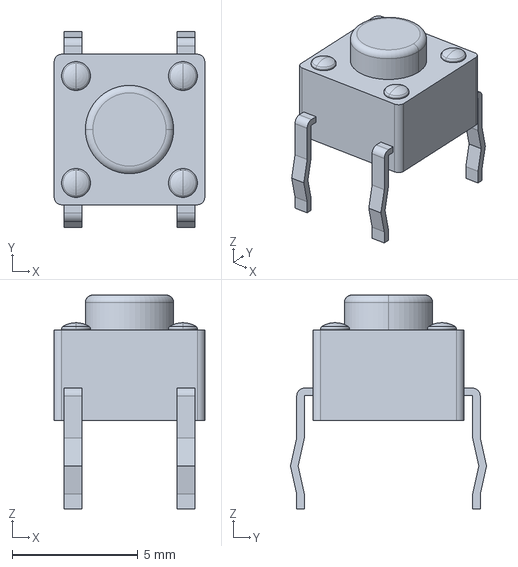
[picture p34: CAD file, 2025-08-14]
Sensor Node/pcb layout/models/c-1825910-6-c-3d.stp
5.99 x 7.80 x 8.51 mm

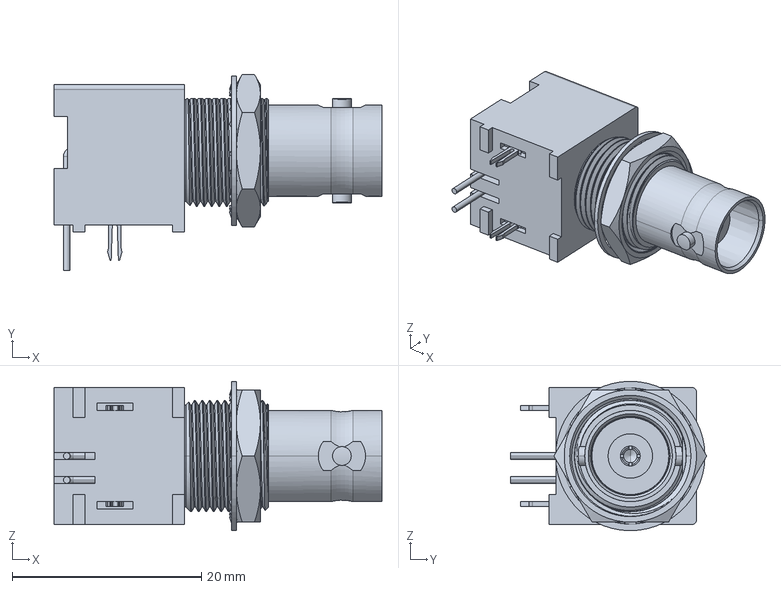
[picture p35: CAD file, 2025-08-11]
Sensor Node/pcb layout/models/31-5431-10RFX.stp
34.7 x 20.8 x 15.8 mm

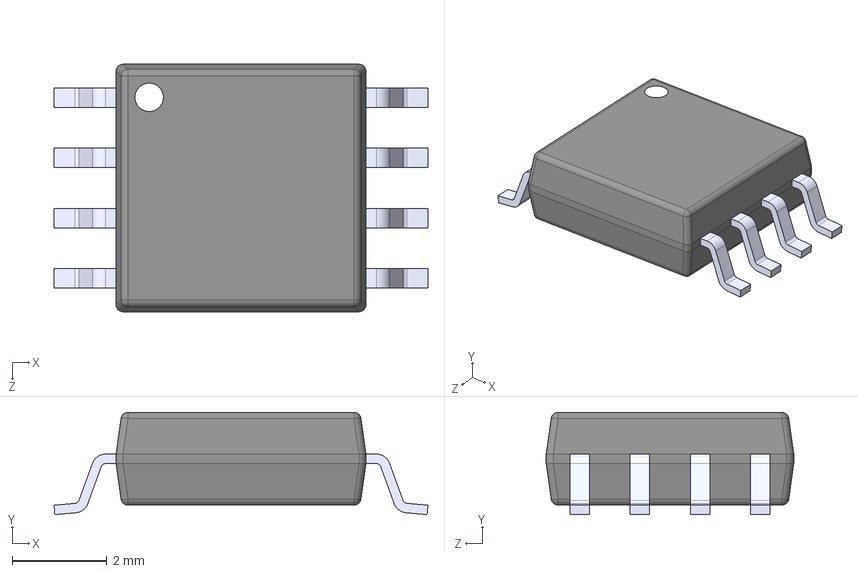
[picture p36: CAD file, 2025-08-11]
Sensor Node/pcb layout/models/MX25L3233FM2I-08Q.step
7.90 x 2.16 x 5.23 mm

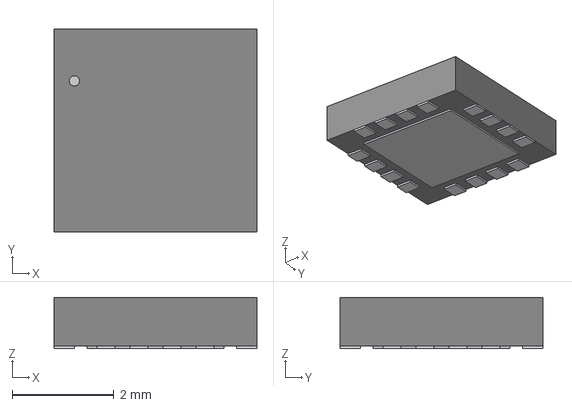
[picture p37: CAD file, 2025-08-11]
Sensor Node/pcb layout/models/QFN16_4x4MC_MCH.step
3.99 x 3.99 x 1.00 mm

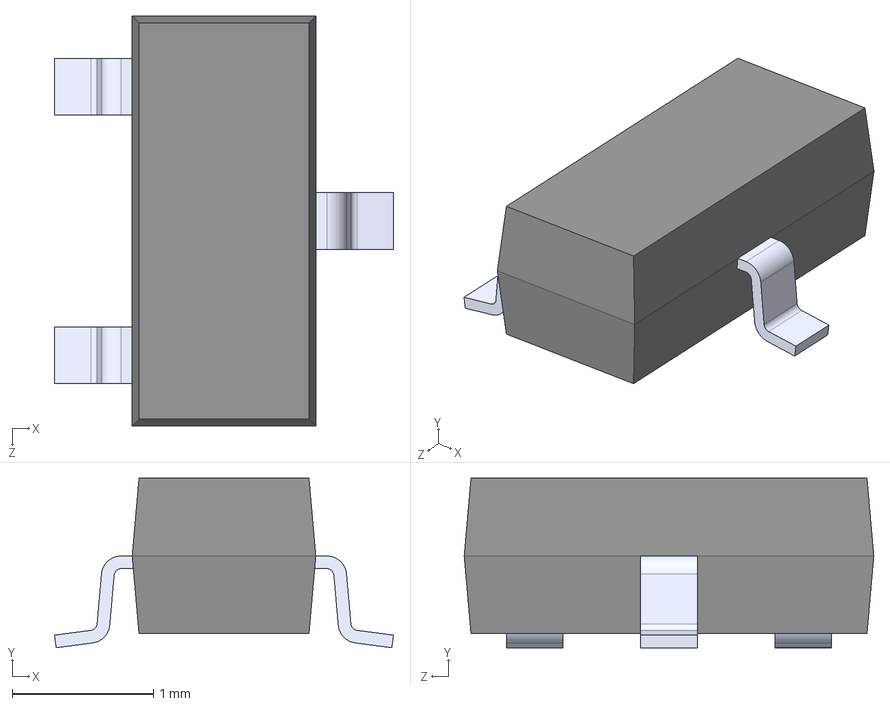
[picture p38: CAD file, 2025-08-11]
Sensor Node/pcb layout/models/BAT54C.step
2.40 x 1.20 x 2.90 mm

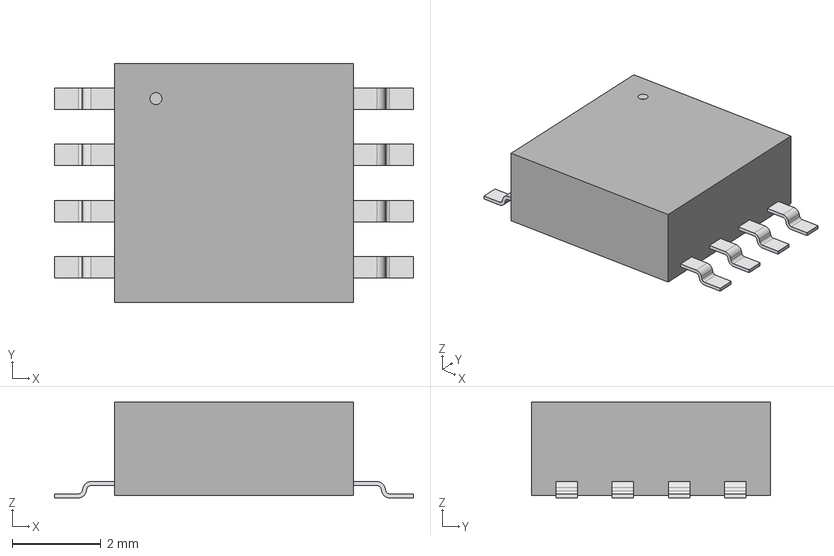
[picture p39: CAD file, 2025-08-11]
Sensor Node/pcb layout/models/SOIC_208MIL_WIN.step
8.10 x 5.38 x 2.16 mm

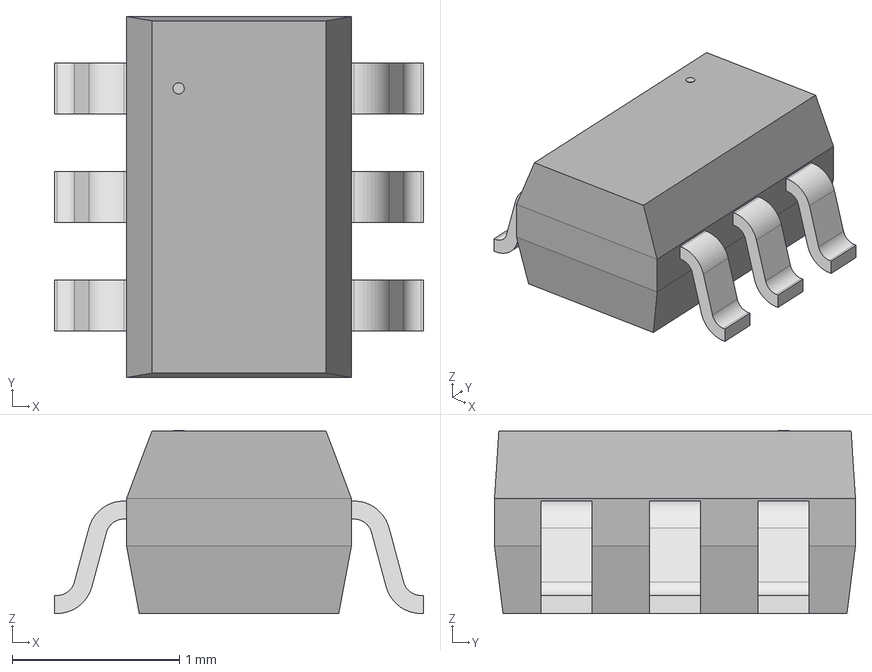
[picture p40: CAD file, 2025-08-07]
Sensor Node/pcb layout/models/SC-70-6_PSM.step
2.21 x 2.16 x 1.09 mm

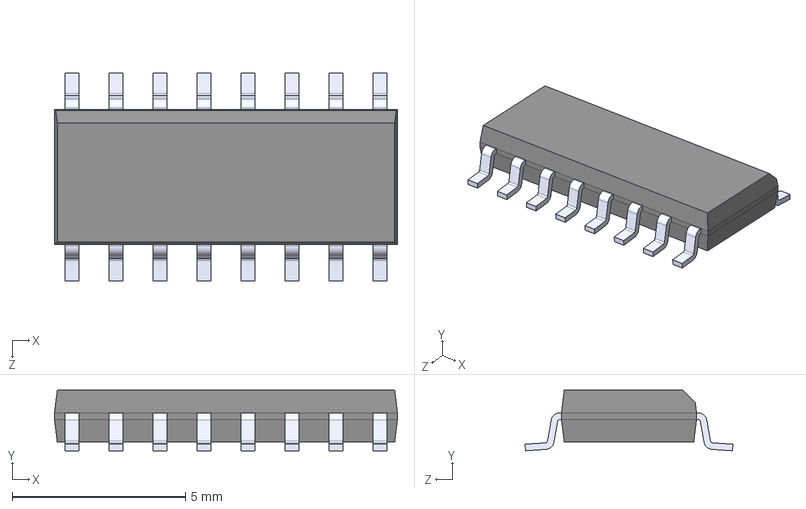
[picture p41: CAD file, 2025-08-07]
Sensor Node/pcb layout/models/TPIC2810DR.step
9.90 x 1.75 x 6.00 mm

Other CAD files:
Sensor Node/pcb layout/models/ABM8-272-T3_ABR.step
Sensor Node/pcb layout/models/TG2520SMN_32.0000M-MCGNNM0.stp
Sensor Node/pcb layout/models/SX1262IMLTRT.step
Sensor Node/pcb layout/models/BGS12WN6E6327XTSA1.step
Sensor Node/pcb layout/models/OQ0232510000G.stp
Sensor Node/pcb layout/models/OQ0332510000G.stp
Sensor Node/pcb layout/models/TPS22918DBVR.step
Sensor Node/pcb layout/models/TPS63000DRCR.step
Sensor Node/pcb layout/models/TPS631010YBGR.step

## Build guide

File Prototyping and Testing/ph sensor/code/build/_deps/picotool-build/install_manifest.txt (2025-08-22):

C:/Users/Cole/Documents/CapstoneGit/capstone/Sensor Node/ph sensor/code/build/_deps/picotool/picotool.exe
C:/Users/Cole/Documents/CapstoneGit/capstone/Sensor Node/ph sensor/code/build/_deps/picotool/picotoolTargets.cmake
C:/Users/Cole/Documents/CapstoneGit/capstone/Sensor Node/ph sensor/code/build/_deps/picotool/picotoolTargets-release.cmake
C:/Users/Cole/Documents/CapstoneGit/capstone/Sensor Node/ph sensor/code/build/_deps/picotool/picotoolConfig.cmake
C:/Users/Cole/Documents/CapstoneGit/capstone/Sensor Node/ph sensor/code/build/_deps/picotool/picotoolConfigVersion.cmake

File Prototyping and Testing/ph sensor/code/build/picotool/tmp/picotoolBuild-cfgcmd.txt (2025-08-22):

cmd='C:/Program Files/CMake/bin/cmake.exe;--no-warn-unused-cli;-DCMAKE_MAKE_PROGRAM:FILEPATH=C:/VSARM/mingw/mingw64/bin/mingw32-make.exe;-DPICO_SDK_PATH:FILEPATH=C:/VSARM/sdk/pico/pico-sdk;-DPICOTOOL_NO_LIBUSB=1;-DPICOTOOL_FLAT_INSTALL=1;-DCMAKE_INSTALL_PREFIX=C:/Users/Cole/Documents/CapstoneGit/capstone/Sensor Node/ph sensor/code/build/_deps;-DCMAKE_RULE_MESSAGES=OFF;-DCMAKE_INSTALL_MESSAGE=NEVER;-GMinGW Makefiles;-S;<SOURCE_DIR><SOURCE_SUBDIR>;-B;<BINARY_DIR>'

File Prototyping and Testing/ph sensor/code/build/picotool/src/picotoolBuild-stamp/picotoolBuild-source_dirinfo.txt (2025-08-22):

# This is a generated file and its contents are an internal implementation detail.
# The download step will be re-executed if anything in this file changes.
# No other meaning or use of this file is supported.

method=source_dir
command=
source_dir=C:/Users/Cole/Documents/CapstoneGit/capstone/Sensor Node/ph sensor/code/build/_deps/picotool-src
work_dir=

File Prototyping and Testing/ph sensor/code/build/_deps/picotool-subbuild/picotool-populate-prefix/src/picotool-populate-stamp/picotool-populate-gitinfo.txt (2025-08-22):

# This is a generated file and its contents are an internal implementation detail.
# The download step will be re-executed if anything in this file changes.
# No other meaning or use of this file is supported.

method=git
command=C:/Program Files/CMake/bin/cmake.exe;-P;C:/Users/Cole/Documents/CapstoneGit/capstone/Sensor Node/ph sensor/code/build/_deps/picotool-subbuild/picotool-populate-prefix/tmp/picotool-populate-gitclone.cmake
source_dir=C:/Users/Cole/Documents/CapstoneGit/capstone/Sensor Node/ph sensor/code/build/_deps/picotool-src
work_dir=C:/Users/Cole/Documents/CapstoneGit/capstone/Sensor Node/ph sensor/code/build/_deps
repository=https://github.com/raspberrypi/picotool.git
remote=origin
init_submodules=TRUE
recurse_submodules=--recursive
submodules=
CMP0097=NEW

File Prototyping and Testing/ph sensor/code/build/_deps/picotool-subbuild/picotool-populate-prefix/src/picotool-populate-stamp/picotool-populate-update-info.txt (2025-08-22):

# This is a generated file and its contents are an internal implementation detail.
# The patch step will be re-executed if anything in this file changes.
# No other meaning or use of this file is supported.

command (connected)=C:/Program Files/CMake/bin/cmake.exe;-Dcan_fetch=YES;-P;C:/Users/Cole/Documents/CapstoneGit/capstone/Sensor Node/ph sensor/code/build/_deps/picotool-subbuild/picotool-populate-prefix/tmp/picotool-populate-gitupdate.cmake
command (disconnected)=C:/Program Files/CMake/bin/cmake.exe;-Dcan_fetch=NO;-P;C:/Users/Cole/Documents/CapstoneGit/capstone/Sensor Node/ph sensor/code/build/_deps/picotool-subbuild/picotool-populate-prefix/tmp/picotool-populate-gitupdate.cmake
work_dir=C:/Users/Cole/Documents/CapstoneGit/capstone/Sensor Node/ph sensor/code/build/_deps/picotool-src

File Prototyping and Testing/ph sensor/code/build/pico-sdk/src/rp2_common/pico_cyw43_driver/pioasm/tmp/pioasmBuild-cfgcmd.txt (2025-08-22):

cmd='C:/Program Files/CMake/bin/cmake.exe;--no-warn-unused-cli;-DCMAKE_MAKE_PROGRAM:FILEPATH=C:/VSARM/mingw/mingw64/bin/mingw32-make.exe;-DPIOASM_FLAT_INSTALL=1;-DCMAKE_INSTALL_PREFIX=C:/Users/Cole/Documents/CapstoneGit/capstone/Sensor Node/ph sensor/code/build/pioasm-install;-DCMAKE_RULE_MESSAGES=OFF;-DCMAKE_INSTALL_MESSAGE=NEVER;-GMinGW Makefiles;-C<TMP_DIR>/pioasmBuild-cache-$<CONFIG>.cmake;-S;<SOURCE_DIR><SOURCE_SUBDIR>;-B;<BINARY_DIR>'

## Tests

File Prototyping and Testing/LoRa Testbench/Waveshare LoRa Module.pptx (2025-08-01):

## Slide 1

3V3

GND

DIO1

DIO2

TXEN

RXEN

GND

GND

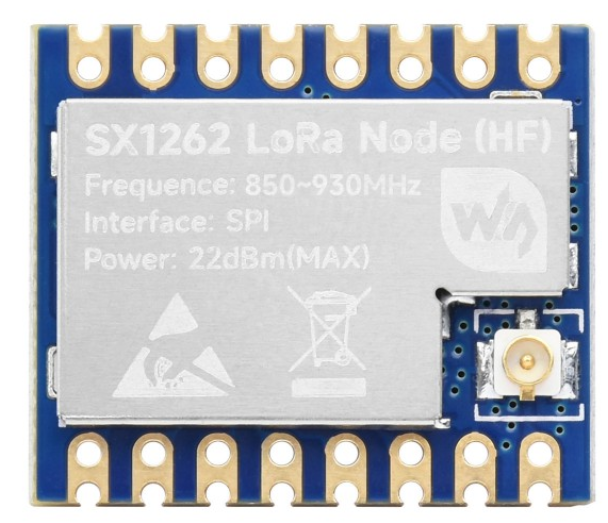
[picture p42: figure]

BUSY

RESET

MISO

MOSI

SCK

CS

GND

ANT

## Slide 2

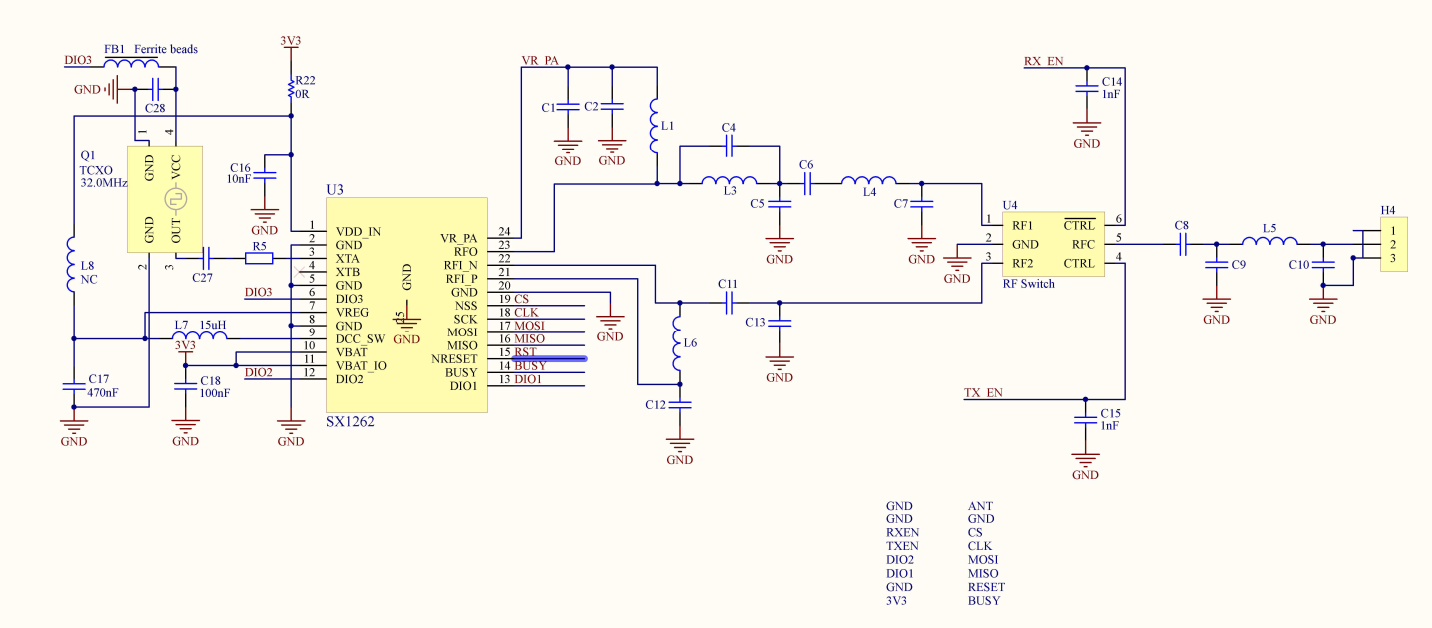
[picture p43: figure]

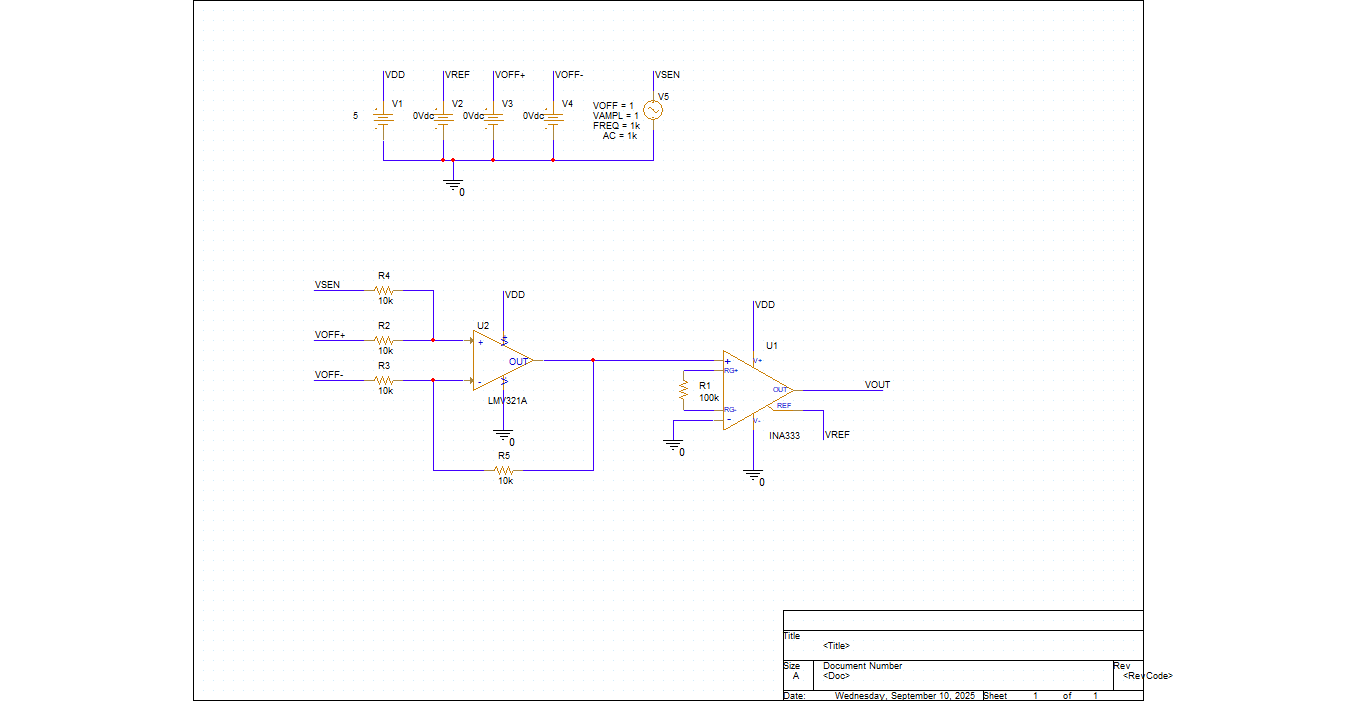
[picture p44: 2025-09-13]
Sensor Node/simulation/ina333/INA333_TEST.png

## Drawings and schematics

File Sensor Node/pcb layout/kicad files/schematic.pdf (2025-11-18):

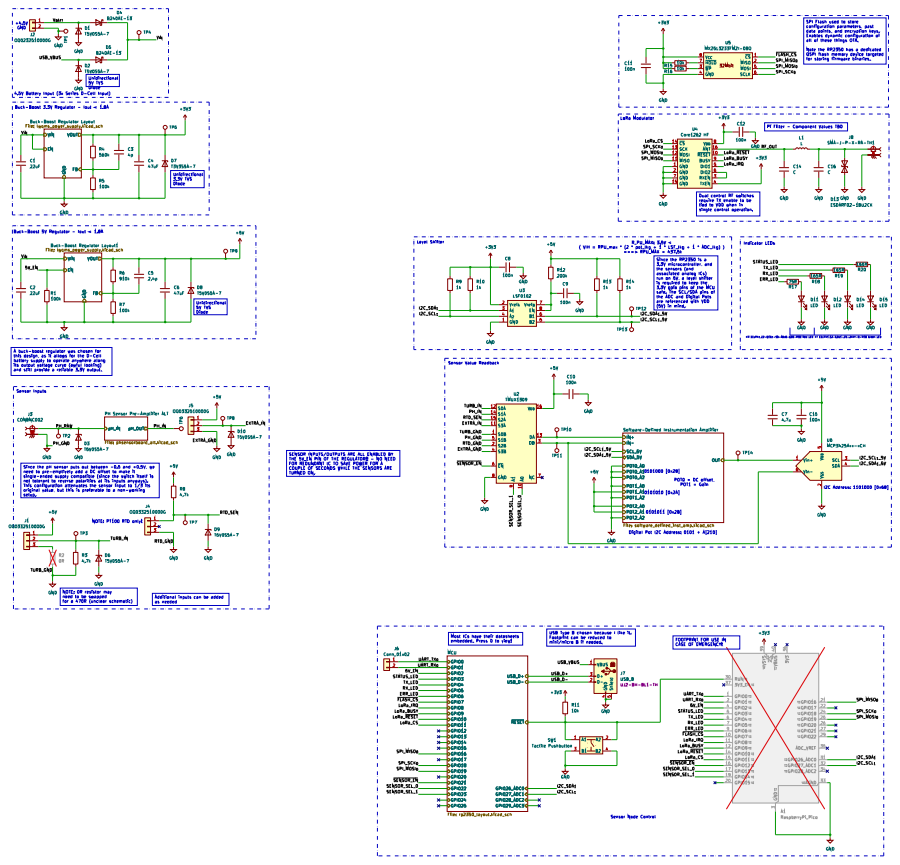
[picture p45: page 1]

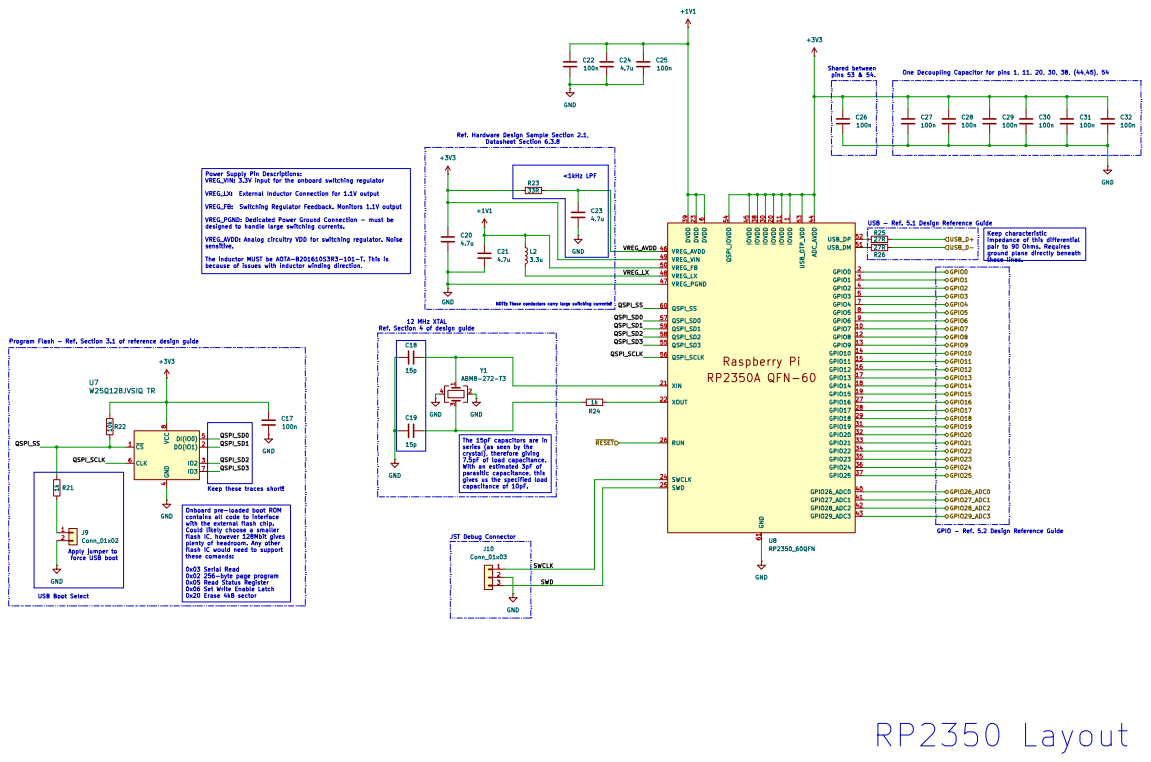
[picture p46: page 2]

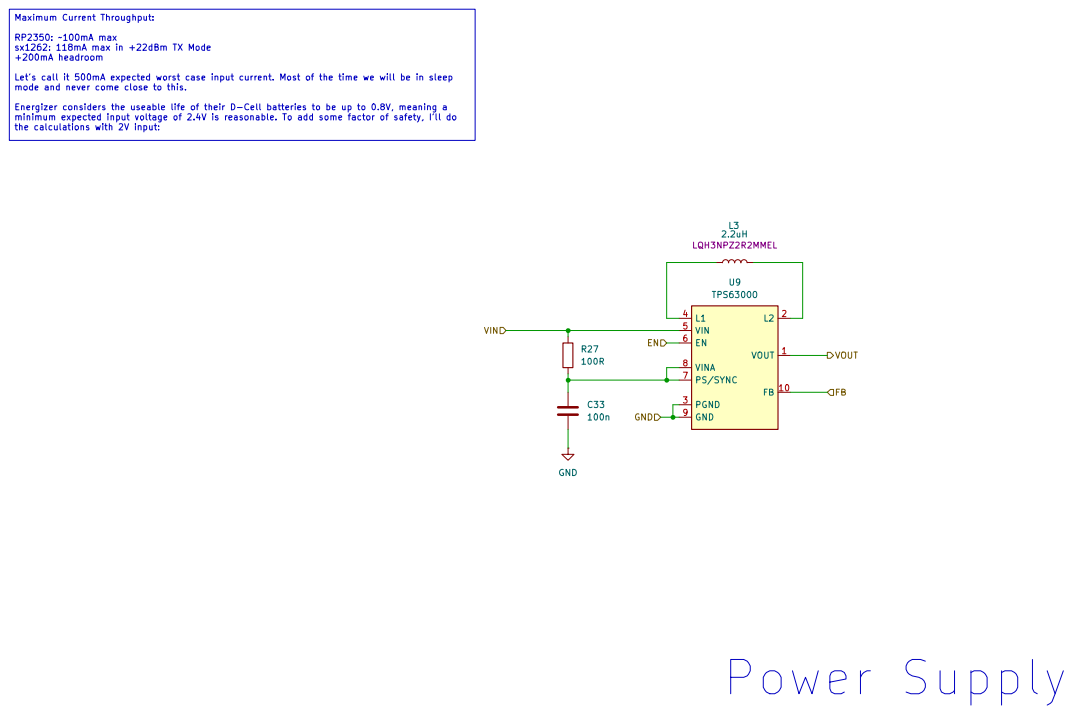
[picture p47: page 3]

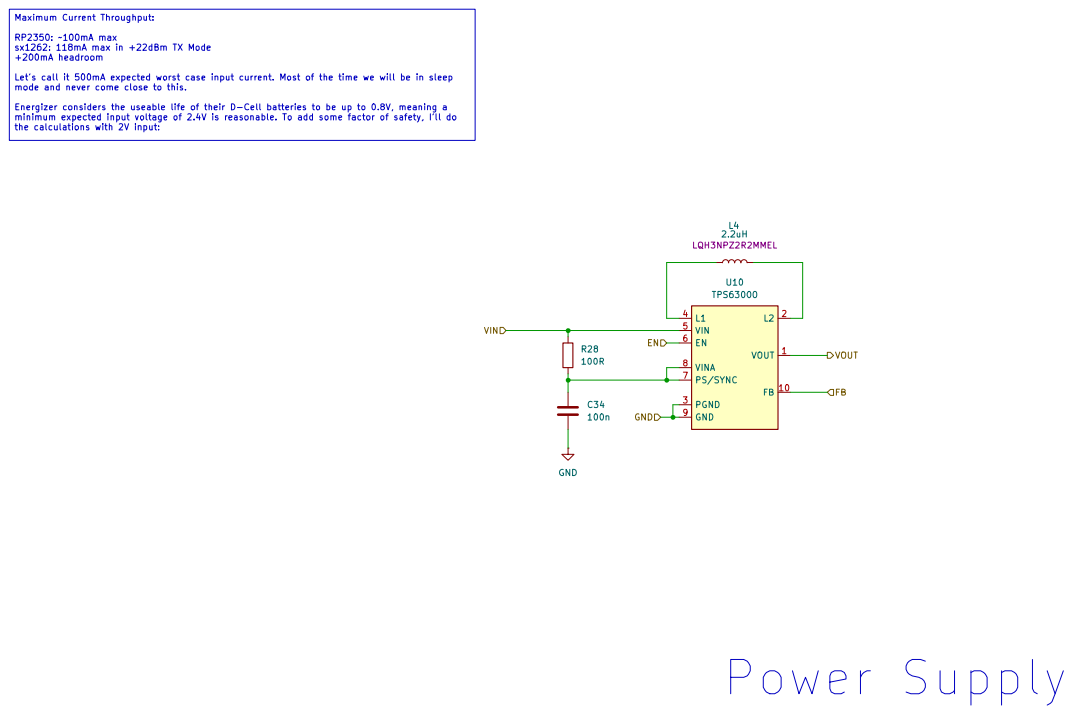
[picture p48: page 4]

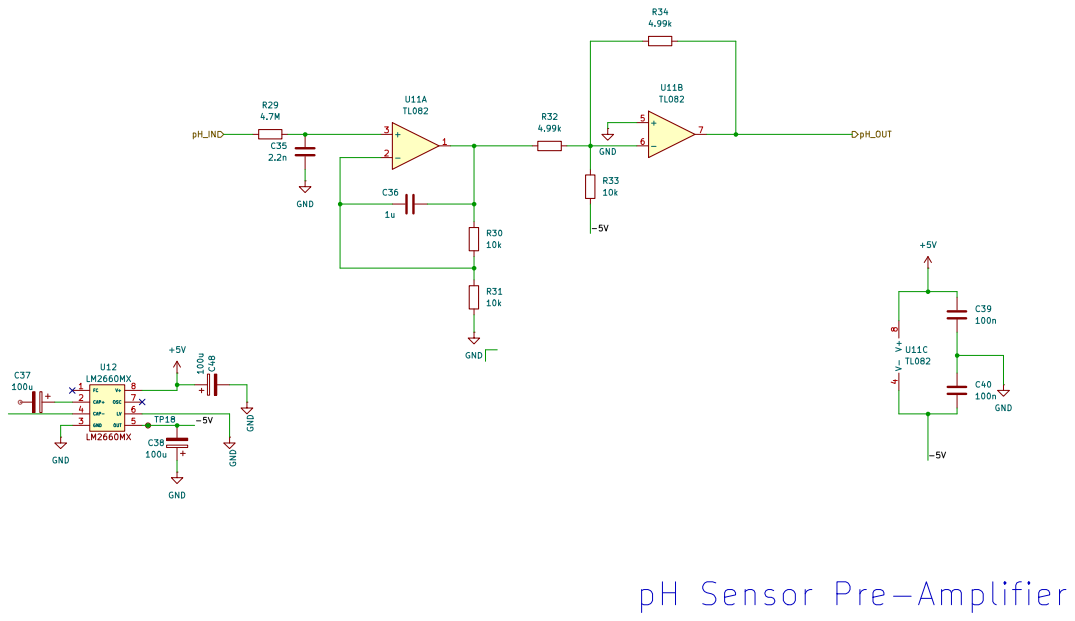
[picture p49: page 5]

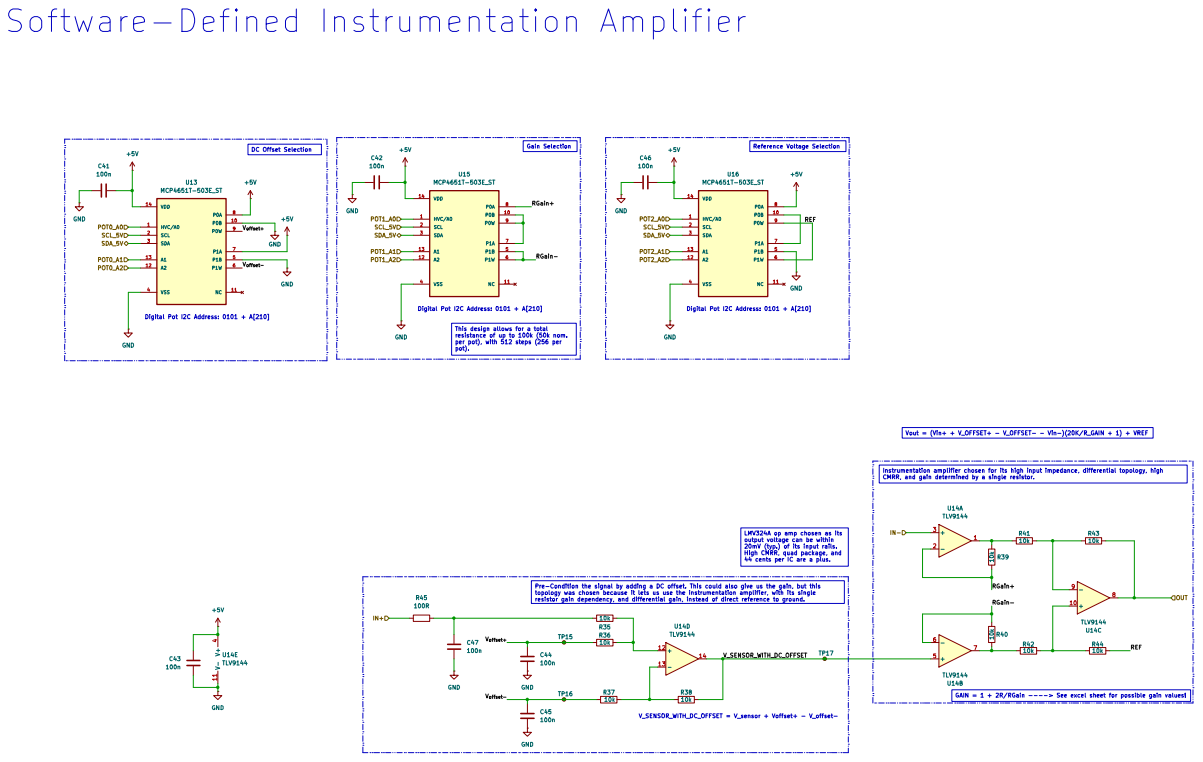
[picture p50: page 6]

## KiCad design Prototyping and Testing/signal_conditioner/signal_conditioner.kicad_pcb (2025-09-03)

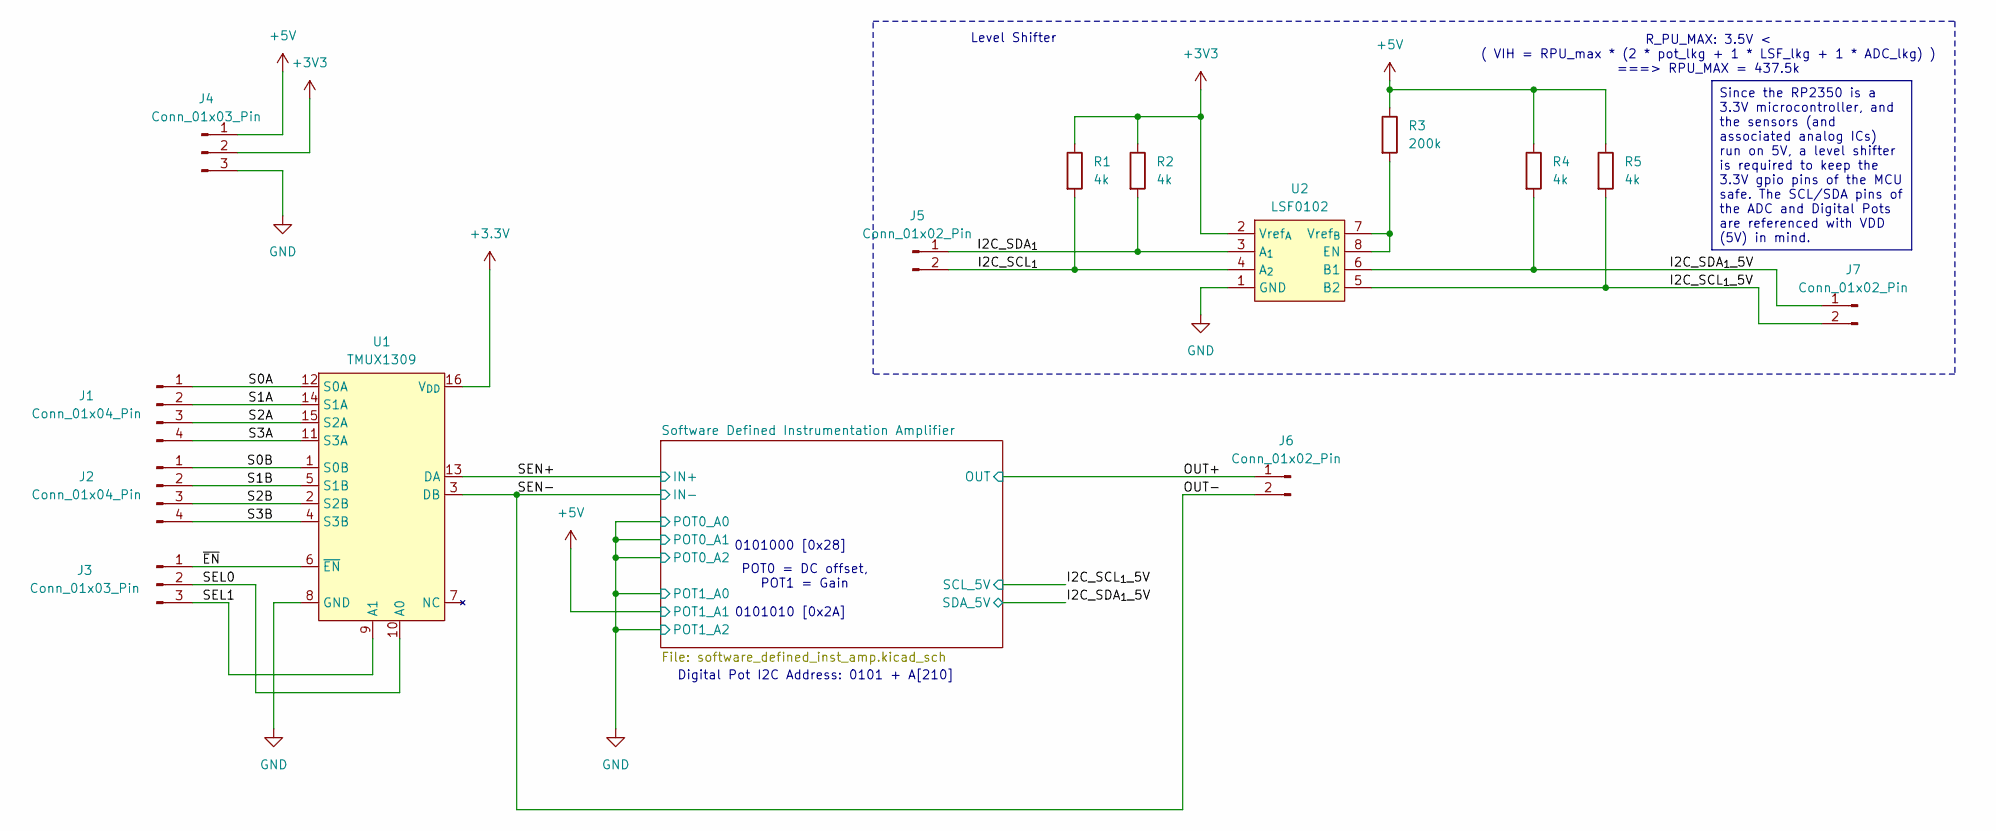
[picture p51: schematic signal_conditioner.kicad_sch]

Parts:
J1, J2: Conn_01x04_Pin; PinHeader_1x04_P2.54mm_Vertical
J3, J4: Conn_01x03_Pin; PinHeader_1x03_P2.54mm_Vertical
J5, J6, J7: Conn_01x02_Pin; PinHeader_1x02_P2.54mm_Vertical
R1, R2, R4, R5: 4k; R_0805_2012Metric_Pad1.20x1.40mm_HandSolder
R3: 200k; R_0805_2012Metric_Pad1.20x1.40mm_HandSolder
U1: TMUX1309; (S)SOP16
U2: LSF0102; (S)SOP8

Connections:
+3.3V: U1.16 (V_{DD})
+3V3: J4.2, R1.1, R2.1, U2.2 (Vref_{A})
+5V: J4.1, R3.1, R4.1, R5.1; also elsewhere on the board
/I2C_SCL_{1}: J5.2, R1.2, U2.4 (A_{2})
/I2C_SCL_{1}_5V: J7.2, R5.2, U2.5 (B2); also elsewhere on the board
/I2C_SDA_{1}: J5.1, R2.2, U2.3 (A_{1})
/I2C_SDA_{1}_5V: J7.1, R4.2, U2.6 (B1); also elsewhere on the board
/OUT+: J6.1; also elsewhere on the board
/OUT-: J6.2, U1.3 (DB); also elsewhere on the board
/S0A: J1.1, U1.12 (S0A)
/S0B: J2.1, U1.1 (S0B)
/S1A: J1.2, U1.14 (S1A)
/S1B: J2.2, U1.5 (S1B)
/S2A: J1.3, U1.15 (S2A)
/S2B: J2.3, U1.2 (S2B)
/S3A: J1.4, U1.11 (S3A)
/S3B: J2.4, U1.4 (S3B)
/SEL0: J3.2, U1.10 (A0)
/SEL1: J3.3, U1.9 (A1)
/SEN+: U1.13 (DA); also elsewhere on the board
/~EN: J3.1, U1.6 (~EN)
GND: J4.3, U1.8 (GND), U2.1 (GND); also elsewhere on the board
unnamed: R3.2, U2.7 (Vref_{B}), U2.8 (EN)

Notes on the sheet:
0101000 [0x28]
Digital Pot I2C Address: 0101 + A[210]
R_PU_MAX: 3.5V < ( VIH = RPU_max * (2 * pot_lkg + 1 * LSF_lkg + 1 * ADC_lkg) ) ===> RPU_MAX = 437.5k
Level Shifter
0101010 [0x2A]
POT0 = DC offset, POT1 = Gain
Since the RP2350 is a 3.3V microcontroller, and the sensors (and associated analog ICs) run on 5V, a level shifter is required to keep the 3.3V gpio pins of the MCU safe. The SCL/SDA pins of the ADC and Digital Pots are referenced with VDD (5V) in mind.

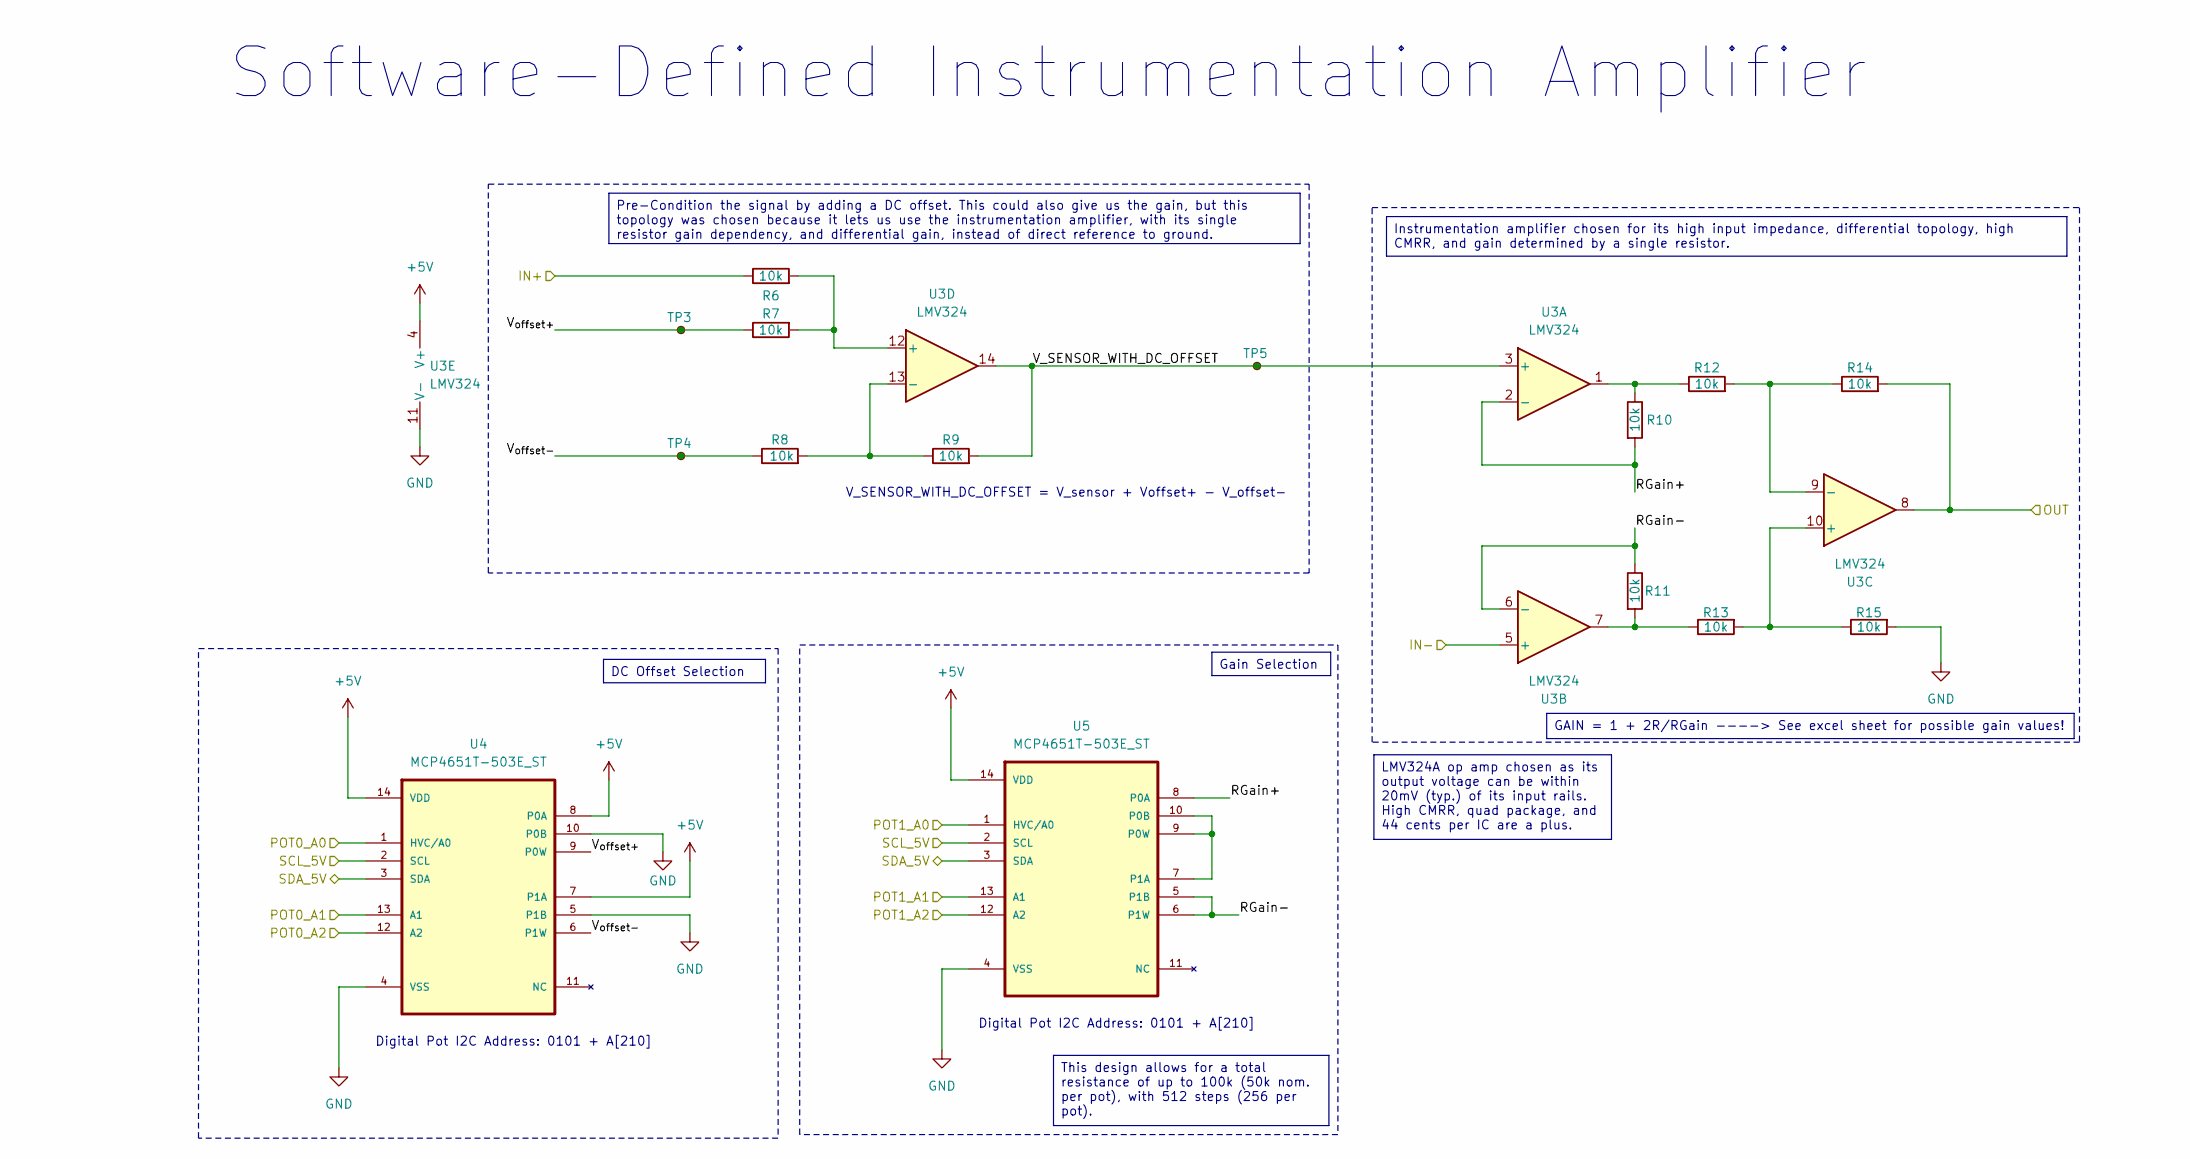
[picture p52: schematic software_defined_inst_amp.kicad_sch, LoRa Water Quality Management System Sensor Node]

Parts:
R6, R7, R8, R9, R10, R11, R12, R13, R14, R15: 10k; R_0805_2012Metric_Pad1.20x1.40mm_HandSolder
TP3, TP4, TP5: TestPoint_Small; TestPoint_Pad_D1.5mm
U3: LMV324; (S)SOP14
U4, U5: MCP4651T-503E_ST; (S)SOP14

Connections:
+5V: U3.4 (V+), U4.7 (P1A), U4.8 (P0A), U4.14 (VDD), U5.13 (A1), U5.14 (VDD); also elsewhere on the board
/I2C_SCL_{1}_5V: U4.2 (SCL), U5.2 (SCL); also elsewhere on the board
/I2C_SDA_{1}_5V: U4.3 (SDA), U5.3 (SDA); also elsewhere on the board
/OUT+: R14.2, U3.8; also elsewhere on the board
/OUT-: U3.5 (+); also elsewhere on the board
/SEN+: R6.1; also elsewhere on the board
/Software Defined Instrumentation Amplifier/RGain+: R10.2, U3.2 (-), U5.8 (P0A)
/Software Defined Instrumentation Amplifier/RGain-: R11.1, U3.6 (-), U5.5 (P1B), U5.6 (P1W)
/Software Defined Instrumentation Amplifier/V_SENSOR_WITH_DC_OFFSET: R9.2, TP5.1, U3.3 (+), U3.14
/Software Defined Instrumentation Amplifier/V_{offset+}: R7.1, TP3.1, U4.9 (P0W)
/Software Defined Instrumentation Amplifier/V_{offset-}: R8.1, TP4.1, U4.6 (P1W)
GND: R15.2, U3.11 (V-), U4.1 (HVC/A0), U4.4 (VSS), U4.5 (P1B), U4.10 (P0B), U4.12 (A2), U4.13 (A1), U5.1 (HVC/A0), U5.4 (VSS), U5.12 (A2); also elsewhere on the board
unnamed: R10.1, R12.1, U3.1
unnamed: R11.2, R13.1, U3.7
unnamed: R13.2, R15.1, U3.10 (+)
unnamed: R12.2, R14.1, U3.9 (-)
unnamed: R6.2, R7.2, U3.12 (+)
unnamed: R8.2, R9.1, U3.13 (-)
unnamed: U5.7 (P1A), U5.9 (P0W), U5.10 (P0B)

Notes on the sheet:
Digital Pot I2C Address: 0101 + A[210]
Software-Defined Instrumentation Amplifier
V_SENSOR_WITH_DC_OFFSET = V_sensor + Voffset+ - V_offset-
DC Offset Selection
GAIN = 1 + 2R/RGain ----> See excel sheet for possible gain values!
Instrumentation amplifier chosen for its high input impedance, differential topology, high CMRR, and gain determined by a single resistor.
Pre-Condition the signal by adding a DC offset. This could also give us the gain, but this topology was chosen because it lets us use the instrumentation amplifier, with its single resistor gain dependency, and differential gain, instead of direct reference to ground.
This design allows for a total resistance of up to 100k (50k nom. per pot), with 512 steps (256 per pot).
Gain Selection
LMV324A op amp chosen as its output voltage can be within 20mV (typ.) of its input rails. High CMRR, quad package, and 44 cents per IC are a plus.

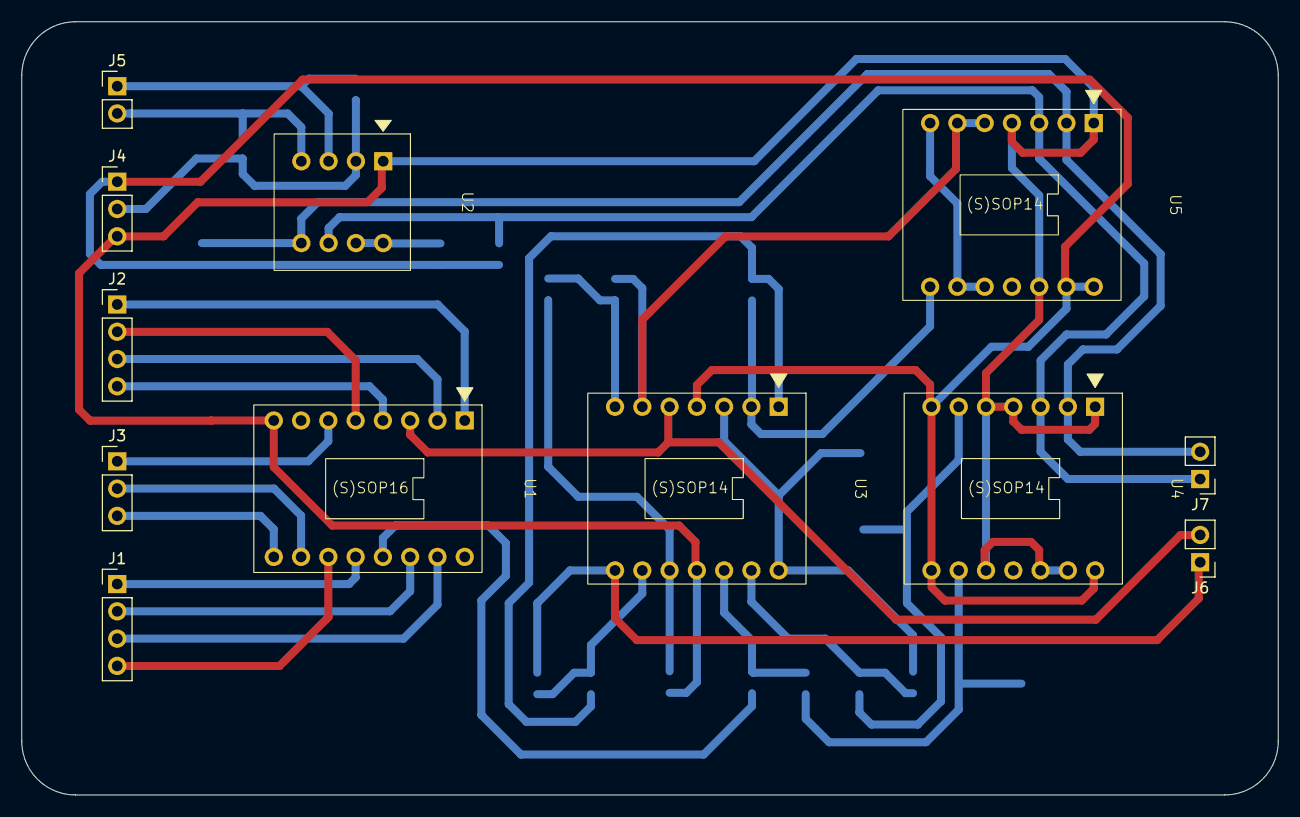
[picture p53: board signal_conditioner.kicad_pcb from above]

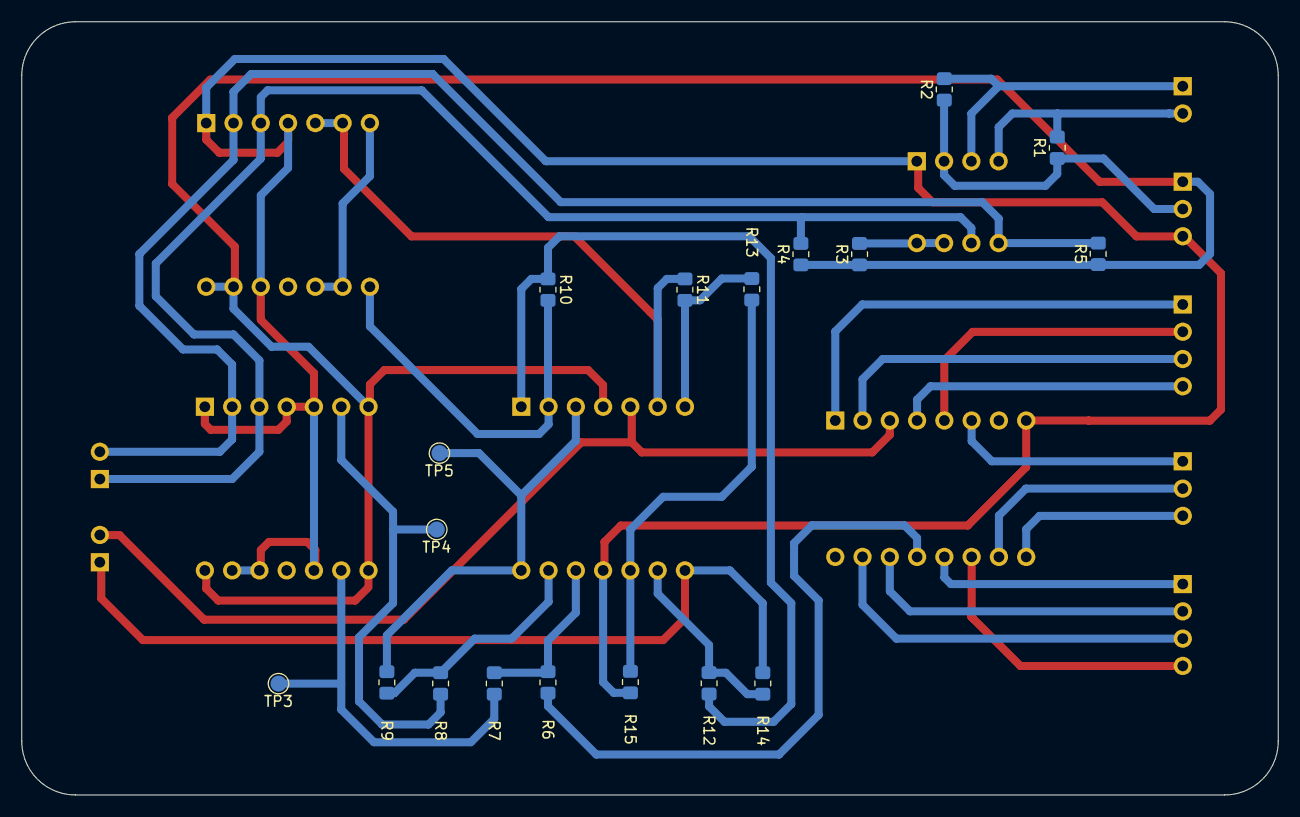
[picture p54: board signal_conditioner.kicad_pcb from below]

Board: 2 copper layers, 117.0 x 72.0 mm, 30 parts (18 on the bottom side), 34 nets.

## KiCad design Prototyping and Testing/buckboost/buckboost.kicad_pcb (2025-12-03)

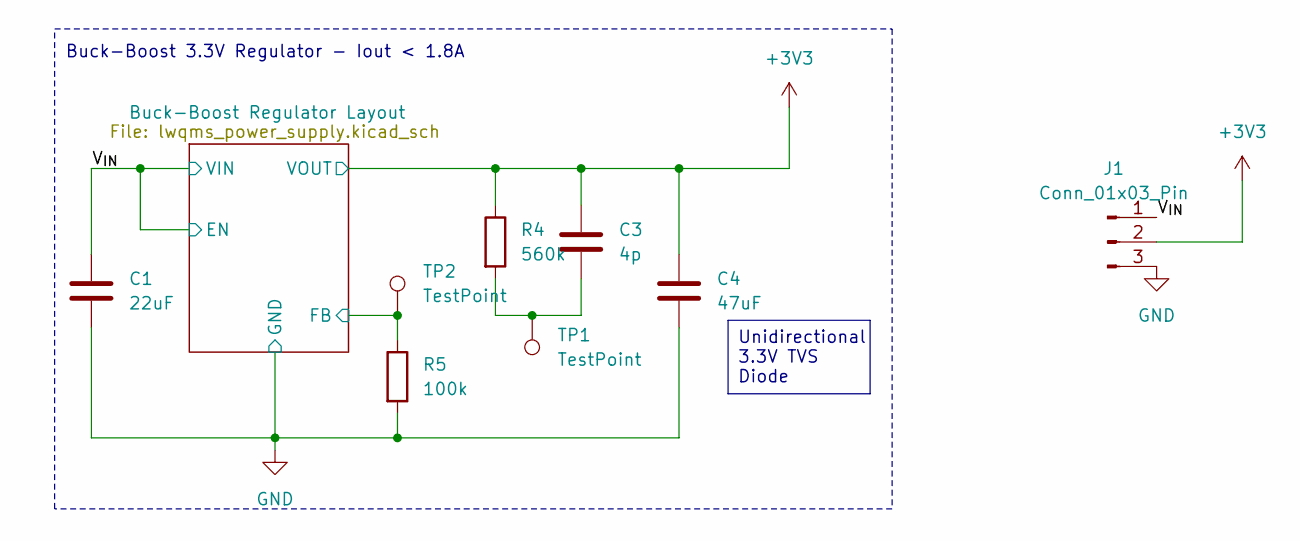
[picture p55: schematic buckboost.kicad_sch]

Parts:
C1: 22uF; C_0805_2012Metric_Pad1.18x1.45mm_HandSolder
C3: 4p; C_0805_2012Metric_Pad1.18x1.45mm_HandSolder
C4: 47uF; C_1206_3216Metric_Pad1.33x1.80mm_HandSolder
J1: Conn_01x03_Pin; PinHeader_1x03_P2.54mm_Vertical
R4: 560k; R_0805_2012Metric_Pad1.20x1.40mm_HandSolder
R5: 100k; R_0805_2012Metric_Pad1.20x1.40mm_HandSolder
TP1, TP2: TestPoint; TestPoint_Pad_D1.5mm

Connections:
+3V3: C3.1, C4.1, J1.2, R4.1; also elsewhere on the board
/Buck-Boost Regulator Layout/FB: R5.1, TP2.1; also elsewhere on the board
/V_{IN}: C1.1, J1.1; also elsewhere on the board
GND: C1.2, C4.2, J1.3, R5.2; also elsewhere on the board
unnamed: C3.2, R4.2, TP1.1

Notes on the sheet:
Buck-Boost 3.3V Regulator - Iout < 1.8A
Unidirectional 3.3V TVS Diode

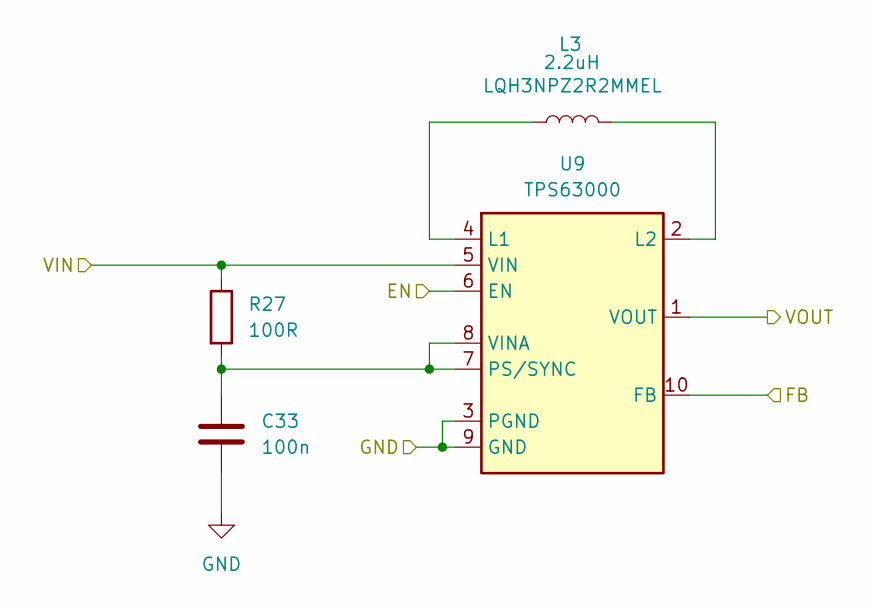
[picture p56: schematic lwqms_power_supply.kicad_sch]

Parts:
C33: 100n; C_0805_2012Metric_Pad1.18x1.45mm_HandSolder
L3: 2.2uH; IND_LQH3NPZ2R2MMEL; MFG P/N LQH3NPZ2R2MMEL
R27: 100R; R_0805_2012Metric_Pad1.20x1.40mm_HandSolder
U9: TPS63000; CONV_TPS63000DRCR

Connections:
/V_{IN}: R27.1, U9.5 (VIN); also elsewhere on the board
GND: C33.2; also elsewhere on the board
unnamed 5: L3.2, U9.4 (L1); also elsewhere on the board
unnamed 6: L3.1, U9.2 (L2); also elsewhere on the board
unnamed 7: C33.1, R27.2, U9.7 (PS/SYNC), U9.8 (VINA); also elsewhere on the board
unnamed: U9.3 (PGND), U9.9 (GND), U9.11 (PGND), U9.11_1 (PGND), U9.11_2 (PGND), U9.11_3 (PGND), U9.11_4 (PGND), U9.11_5 (PGND), U9.11_6 (PGND), U9.11_7 (PGND), U9.11_8 (PGND)

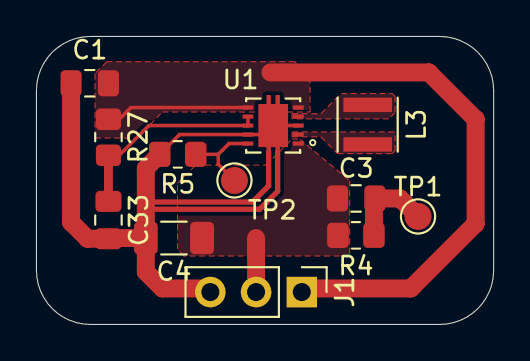
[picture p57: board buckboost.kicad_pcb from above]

Board: 2 copper layers, 25.4 x 16.0 mm, 12 parts (0 on the bottom side), 8 nets.

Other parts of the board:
U1: TPS63000; CONV_TPS63000DRCR

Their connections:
+3V3: U1.1 (VOUT); also elsewhere on the board
/Buck-Boost Regulator Layout/FB: U1.10 (FB); also elsewhere on the board
/V_{IN}: U1.5 (VIN), U1.6 (EN); also elsewhere on the board
GND: U1.3 (PGND), U1.9 (GND), U1.11 (PGND), U1.11_1 (PGND), U1.11_2 (PGND), U1.11_3 (PGND), U1.11_4 (PGND); also elsewhere on the board
unnamed 5: U1.4 (L1); also elsewhere on the board
unnamed 6: U1.2 (L2); also elsewhere on the board
unnamed 7: U1.7 (PS/SYNC), U1.8 (VINA); also elsewhere on the board

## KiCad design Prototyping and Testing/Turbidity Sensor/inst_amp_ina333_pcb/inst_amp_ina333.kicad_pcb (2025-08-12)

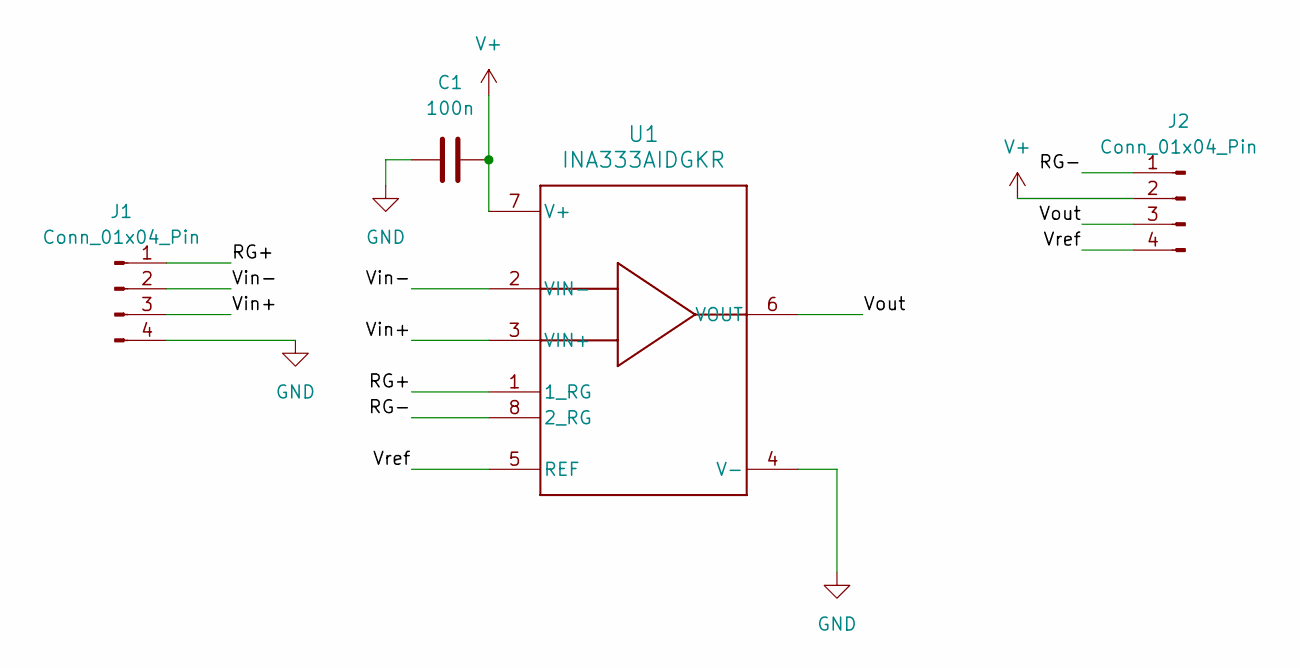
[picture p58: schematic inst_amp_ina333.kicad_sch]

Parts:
C1: 100n; C_1206_3216Metric
J1, J2: Conn_01x04_Pin; PinHeader_1x04_P2.54mm_Vertical
U1: INA333AIDGKR; INA333_VSSOP

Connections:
/RG+: J1.1, U1.1 (1_RG)
/RG-: J2.1, U1.8 (2_RG)
/Vin+: J1.3, U1.3 (VIN+)
/Vin-: J1.2, U1.2 (VIN-)
/Vout: J2.3, U1.6 (VOUT)
/Vref: J2.4, U1.5 (REF)
GND: C1.1, J1.4, U1.4 (V-)
V+: C1.2, J2.2, U1.7 (V+)

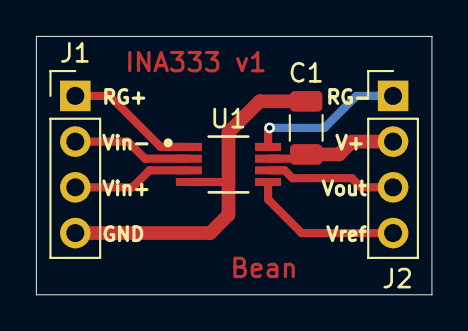
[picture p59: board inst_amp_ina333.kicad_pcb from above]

Board: 2 copper layers, 22.0 x 14.4 mm, 4 parts (0 on the bottom side), 8 nets.

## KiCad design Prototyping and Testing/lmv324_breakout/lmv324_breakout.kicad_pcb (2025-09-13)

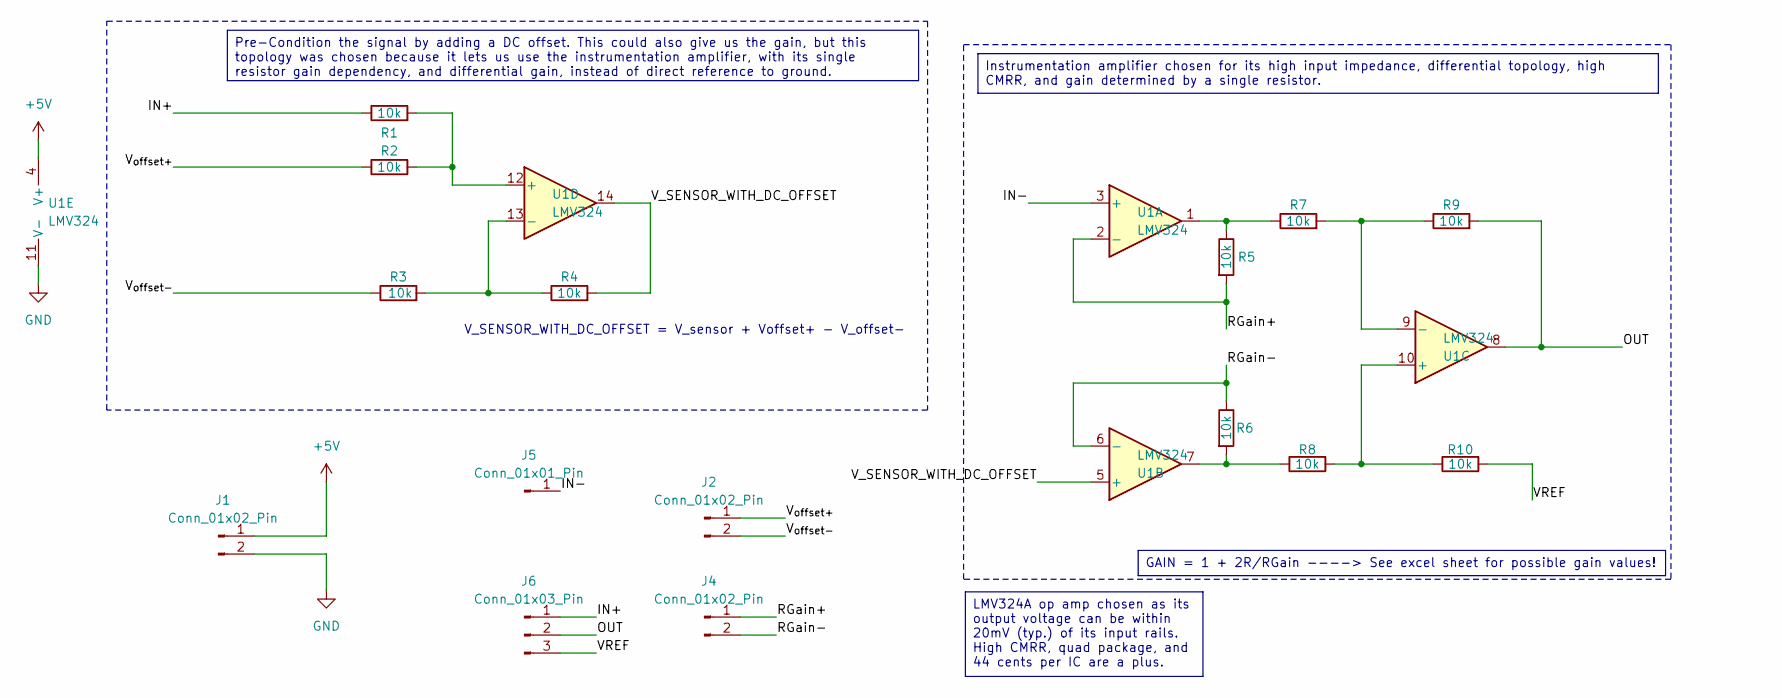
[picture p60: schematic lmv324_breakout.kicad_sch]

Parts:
J1, J2, J4: Conn_01x02_Pin; PinHeader_1x02_P2.54mm_Vertical
J5: Conn_01x01_Pin; PinHeader_1x01_P2.54mm_Vertical
J6: Conn_01x03_Pin; PinHeader_1x03_P2.54mm_Vertical
R1, R2, R3, R4, R5, R6, R7, R8, R9, R10: 10k; R_0805_2012Metric_Pad1.20x1.40mm_HandSolder
U1: LMV324; TSSOP-14_4.4x5mm_P0.65mm

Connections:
+5V: J1.1, U1.4 (V+)
/IN+: J6.1, R1.1
/IN-: J5.1, U1.3 (+)
/OUT: J6.2, R9.2, U1.8
/RGain+: J4.1, R5.2, U1.2 (-)
/RGain-: J4.2, R6.1, U1.6 (-)
/VREF: J6.3, R10.2
/V_SENSOR_WITH_DC_OFFSET: R4.2, U1.5 (+), U1.14
/V_{offset+}: J2.1, R2.1
/V_{offset-}: J2.2, R3.1
GND: J1.2, U1.11 (V-)
unnamed: R5.1, R7.1, U1.1
unnamed: R6.2, R8.1, U1.7
unnamed: R8.2, R10.1, U1.10 (+)
unnamed: R7.2, R9.1, U1.9 (-)
unnamed: R1.2, R2.2, U1.12 (+)
unnamed: R3.2, R4.1, U1.13 (-)

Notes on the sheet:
V_SENSOR_WITH_DC_OFFSET = V_sensor + Voffset+ - V_offset-
Instrumentation amplifier chosen for its high input impedance, differential topology, high CMRR, and gain determined by a single resistor.
Pre-Condition the signal by adding a DC offset. This could also give us the gain, but this topology was chosen because it lets us use the instrumentation amplifier, with its single resistor gain dependency, and differential gain, instead of direct reference to ground.
LMV324A op amp chosen as its output voltage can be within 20mV (typ.) of its input rails. High CMRR, quad package, and 44 cents per IC are a plus.
GAIN = 1 + 2R/RGain ----> See excel sheet for possible gain values!

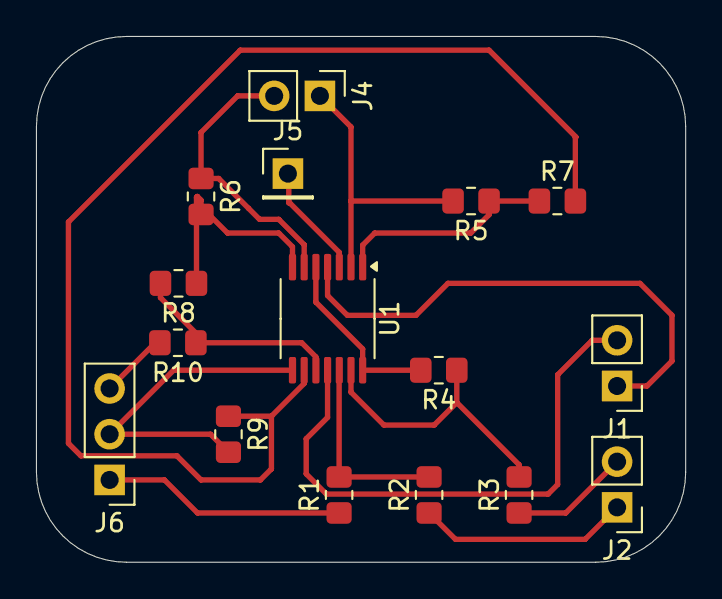
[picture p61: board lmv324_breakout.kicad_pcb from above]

Board: 2 copper layers, 36.1 x 29.2 mm, 16 parts (0 on the bottom side), 17 nets.

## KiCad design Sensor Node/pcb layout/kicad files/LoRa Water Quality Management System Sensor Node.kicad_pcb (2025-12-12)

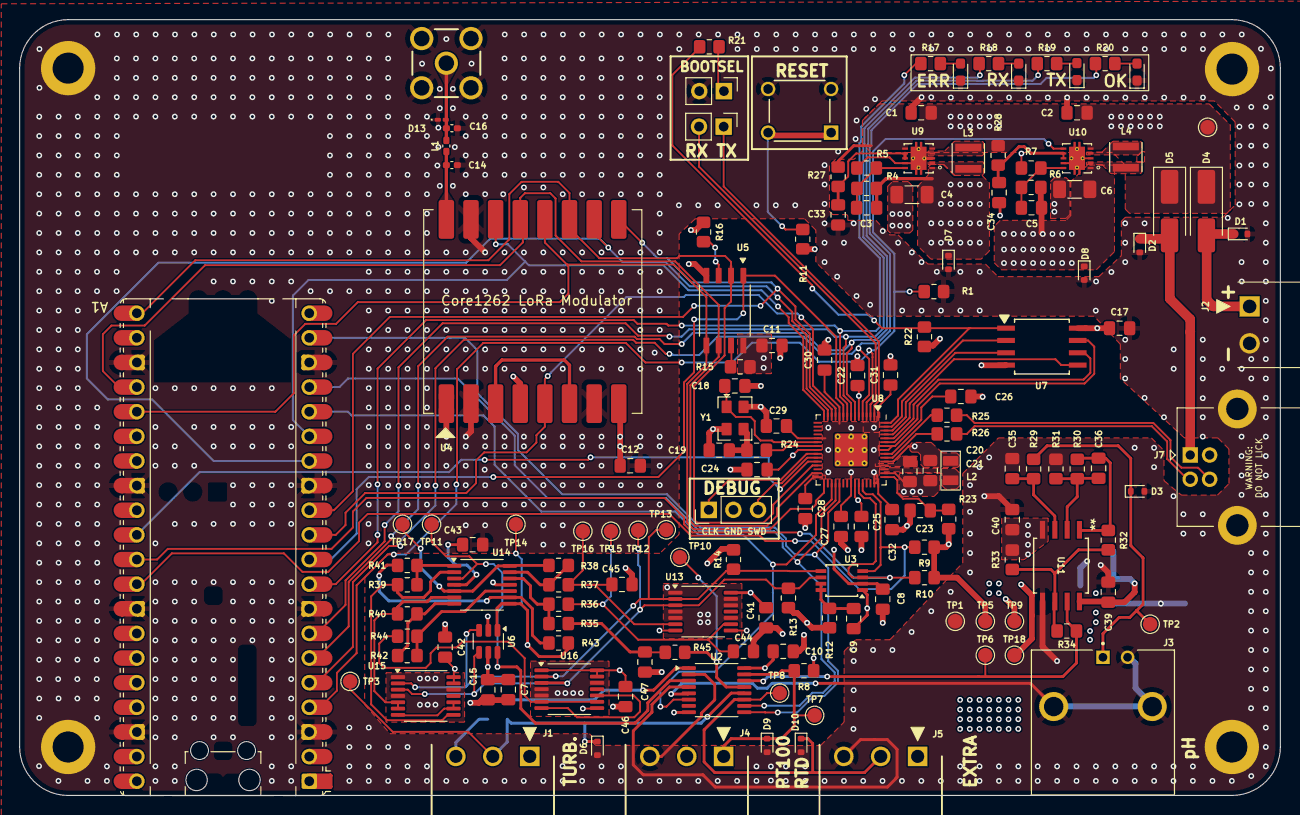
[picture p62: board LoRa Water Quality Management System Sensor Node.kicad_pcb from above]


Board: 4 copper layers, 130.0 x 80.0 mm, 157 parts (6 on the bottom side), 96 nets.

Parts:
A1: RaspberryPi_Pico; RaspberryPi_Pico_Common_Unspecified
C1, C2: 22uF; C_0805_2012Metric_Pad1.18x1.45mm_HandSolder
C3: 4p; C_0805_2012Metric_Pad1.18x1.45mm_HandSolder
C4, C6: 47uF; C_1206_3216Metric_Pad1.33x1.80mm_HandSolder
C5: 2.4p; C_0805_2012Metric_Pad1.18x1.45mm_HandSolder
C7, C20, C21, C23, C24: 4.7u; C_0805_2012Metric_Pad1.18x1.45mm_HandSolder
C8, C9, C10, C11, C12, C15, C17, C22, C25, C26, C27, C28, C29, C30, C31, C32, C33, C34, C39, C40, C41, C42, C43, C44, C45, C46, C47: 100n; C_0805_2012Metric_Pad1.18x1.45mm_HandSolder
C14, C16: C; C_0402_1005Metric_Pad0.74x0.62mm_HandSolder
C18, C19: 15p; C_0805_2012Metric_Pad1.18x1.45mm_HandSolder
C35: 2.2n; C_0805_2012Metric_Pad1.18x1.45mm_HandSolder
C36: 1u; C_0805_2012Metric_Pad1.18x1.45mm_HandSolder
C37, C38, C48: 100u; C_1206_3216Metric_Pad1.33x1.80mm_HandSolder
D1, D2, D3, D6, D8, D9, D10: T5V0S5A-7; D_SOD-523
D4, D5: B240AE-13; D_SMA_Handsoldering
D7: T3V3S5A-7; D_SOD-523
D11, D12, D14, D15: LED; LED_0603_1608Metric_Pad1.05x0.95mm_HandSolder
D13: ESDARF02-1BU2CK; D_0201_0603Metric_Pad0.64x0.40mm_HandSolder
J1, J4, J5: OQ0332510000G
J2: OQ0232510000G
J3: CONBNC002; LINX_CONBNC002
J6, J9: Conn_01x02; PinHeader_1x02_P2.54mm_Vertical
J7: USB_B; USB_B_Lumberg_2411_02_Horizontal
J8: SMA-J-P-X-RA-TH1; SAMTEC_SMA-J-P-X-RA-TH1
J10: Conn_01x03; PinHeader_1x03_P2.54mm_Vertical
L1: L; L_0402_1005Metric_Pad0.77x0.64mm_HandSolder
L2: 3.3u; AOTA-B201610S3R3-101-T
L3, L4: 2.2uH; IND_LQH3NPZ2R2MMEL
R1, R5, R7: 100k; R_0805_2012Metric_Pad1.20x1.40mm_HandSolder
R2: 0R; R_0805_2012Metric_Pad1.20x1.40mm_HandSolder
R3, R8: 4.7k; R_0805_2012Metric_Pad1.20x1.40mm_HandSolder
R4: 560k; R_0805_2012Metric_Pad1.20x1.40mm_HandSolder
R6: 910k; R_0805_2012Metric_Pad1.20x1.40mm_HandSolder
R9, R10, R13, R14, R21, R24: 1k; R_0805_2012Metric_Pad1.20x1.40mm_HandSolder
R11, R15, R16, R22, R30, R31, R33, R39, R40, R41, R42, R43, R44: 10k; R_0805_2012Metric_Pad1.20x1.40mm_HandSolder
R12: 200k; R_0805_2012Metric_Pad1.20x1.40mm_HandSolder
R17: 75R; R_0805_2012Metric_Pad1.20x1.40mm_HandSolder
R18, R19, R20: 165R; R_0805_2012Metric_Pad1.20x1.40mm_HandSolder
R23: 33R; R_0805_2012Metric_Pad1.20x1.40mm_HandSolder
R25, R26: 27R; R_0805_2012Metric_Pad1.20x1.40mm_HandSolder
R27, R28, R45: 100R; R_0805_2012Metric_Pad1.20x1.40mm_HandSolder
R29: 4.7M; R_0805_2012Metric_Pad1.20x1.40mm_HandSolder
R32, R34: 4.99k; R_0805_2012Metric_Pad1.20x1.40mm_HandSolder
R35, R36, R37, R38: 3.3M; R_0805_2012Metric_Pad1.20x1.40mm_HandSolder
SW1: Tactile Pushbutton; SW4_1825910-B_TEC
TP1, TP2, TP3, TP4, TP5, TP6, TP7, TP8, TP9, TP10, TP11, TP12, TP13, TP14: TestPoint; TestPoint_Pad_D1.5mm
TP15, TP16, TP17, TP18: TestPoint_Small; TestPoint_Pad_D1.5mm
U2: TMUX1309; TSSOP-16_4.4x5mm_P0.65mm
U3: LSF0102; TSSOP-8_3x3mm_P0.65mm
U4: Core1262 HF; Core1262
U5: MX25L3233FM2I-08Q; SOIC127P790X216-8N
U6: MCP3425Axx-xCH; SOT-23-6
U7: W25Q128JVSIQ TR; SOIC_208MIL_WIN-M
U8: RP2350_60QFN; RP2350-QFN-60-1EP_7x7_P0.4mm_EP3.4x3.4mm_ThermalVias
U9, U10: TPS63000; CONV_TPS63000DRCR
U11: TL082; SOIC_208MIL_WIN-M
U12: LM2660MX; SOIC_208MIL_WIN-M
U13, U15, U16: MCP4651T-503E_ST; TSSOP-14_4.4x5mm_P0.65mm
U14: TLV9144; TSSOP-14_4.4x5mm_P0.65mm
Y1: ABM8-272-T3

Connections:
+1V1: C21.1, C22.1, C24.1, C25.1, L2.1, U8.6 (DVDD), U8.23 (DVDD), U8.39 (DVDD), U8.50 (VREG_FB)
+3V3: A1.39 (VSYS), C3.1, C4.1, C8.1, C11.1, C12.1, C17.1, C20.1, C26.1, C27.1, C28.1, C29.1, C30.1, C31.1, C32.1, D7.1 (K), R4.1, R9.1, R10.1, R11.1, R15.1, R16.1, R22.1, R23.1, TP5.1, U3.2 (Vref_{A}), U4.4 (TXEN), U4.8 (V_{DD}), U5.8 (V_{CC}), U7.8 (VCC), U8.1 (IOVDD), U8.11 (IOVDD), U8.20 (IOVDD), U8.30 (IOVDD), U8.38 (IOVDD), U8.44 (ADC_AVDD), U8.45 (IOVDD), U8.49 (VREG_VIN), U8.53 (USB_OTP_VDD), U8.54 (QSPI_IOVDD), U9.1 (VOUT)
+5V: C5.1, C6.1, C7.1, C10.1, C15.1, C39.1, C41.2, C42.2, C43.1, C46.2, C48.1, D8.1 (K), J1.1, J5.1, R6.1, R8.1, R12.1, R13.1, R14.1, TP9.1, U2.16 (V_{DD}), U6.5 (V_{DD}), U10.1 (VOUT), U11.8 (V+), U12.8 (V+), U13.7 (P1A), U13.8 (P0A), U13.14 (VDD), U14.4 (V+), U15.13 (A1), U15.14 (VDD), U16.1 (HVC/A0), U16.8 (P0A), U16.13 (A1), U16.14 (VDD)
/5V_EN: A1.4 (GPIO2), R1.1, U8.4 (GPIO2), U10.6 (EN)
/Buck-Boost Regulator Layout1/FB: C5.2, R6.2, R7.1, U10.10 (FB)
/Buck-Boost Regulator Layout/FB: C3.2, R4.2, R5.1, U9.10 (FB)
/ERR_LED: A1.9 (GPIO6), R17.1, U8.9 (GPIO6)
/EXTRA_IN: D10.1 (K), J5.2, TP8.1, U2.11 (S3A)
/I2C_SCL_{1}: A1.32 (GPIO27_ADC1), R9.2, U3.4 (A_{2}), U8.41 (GPIO27_ADC1)
/I2C_SCL_{1}_5V: R14.2, TP13.1, U3.5 (B2), U6.3 (SCL), U13.2 (SCL), U15.2 (SCL), U16.2 (SCL)
/I2C_SDA_{1}: A1.31 (GPIO26_ADC0), R10.2, U3.3 (A_{1}), U8.40 (GPIO26_ADC0)
/I2C_SDA_{1}_5V: R13.2, TP12.1, U3.6 (B1), U6.4 (SDA), U13.3 (SDA), U15.3 (SDA), U16.3 (SDA)
/LoRa_BUSY: A1.12 (GPIO9), U4.9 (BUSY), U8.13 (GPIO9)
/LoRa_CS: A1.15 (GPIO11), U4.14 (~CS), U8.15 (GPIO11)
/LoRa_IRQ: A1.11 (GPIO8), U4.5 (DIO1), U8.12 (GPIO8)
/LoRa_~RESET: A1.14 (GPIO10), U4.10 (~RESET), U8.14 (GPIO10)
/MCU/QSPI_SCLK: U7.6 (CLK), U8.56 (QSPI_SCLK)
/MCU/QSPI_SD0: U7.5 (DI(IO0)), U8.57 (QSPI_SD0)
/MCU/QSPI_SD1: U7.2 (DO(IO1)), U8.59 (QSPI_SD1)
/MCU/QSPI_SD2: U7.3 (IO2), U8.58 (QSPI_SD2)
/MCU/QSPI_SD3: U7.7 (IO3), U8.55 (QSPI_SD3)
/MCU/QSPI_SS: R21.2, R22.2, U7.1 (~CS), U8.60 (QSPI_SS)
/MCU/SWCLK: J10.1, U8.24 (SWCLK)
/MCU/SWD: J10.3, U8.25 (SWD)
/MCU/VREG_AVDD: C23.1, R23.2, U8.46 (VREG_AVDD)
/MCU/VREG_LX: L2.2, U8.48 (VREG_LX)
/MCU/~RESET: A1.30 (RUN), R11.2, SW1.1 (A1), SW1.2 (A2), U8.26 (RUN)
/PH Sensor Pre-Amplifier ALT/-5V: C38.2, C40.2, R33.1, TP18.1, U11.4 (V-), U12.5 (OUT)
/PH_IN: R34.2, TP6.1, U2.14 (S1A), U11.7
/PH_RAW: D3.1 (K), J3.1, R29.1, TP2.1
/RF_OUT: C14.1, L1.1, U4.16 (ANT)
/RTD_SEN: D9.1 (K), J4.1, R8.2, TP7.1, U2.15 (S2A)
/RX_LED: A1.7 (GPIO5), R18.1, U8.8 (GPIO5)
/SENSOR_SEL_0: A1.17 (GPIO13), U2.10 (A0), U8.34 (GPIO22)
/SENSOR_SEL_1: A1.19 (GPIO14), U2.9 (A1), U8.35 (GPIO23)
/SPI_MISO_{0}: A1.21 (GPIO16), U4.11 (MISO), U5.2 (MISO), U8.27 (GPIO16)
/SPI_MOSI_{0}: A1.25 (GPIO19), U4.12 (MOSI), U5.5 (MOSI), U8.31 (GPIO19)
/SPI_SCK_{0}: A1.24 (GPIO18), U4.13 (SCK), U5.6 (SCLK), U8.29 (GPIO18)
/STATUS_LED: A1.5 (GPIO3), R20.1, U8.5 (GPIO3)
/Software-Defined Instrumentation Amplifier/IN+: R45.1, TP10.1, U2.13 (DA)
/Software-Defined Instrumentation Amplifier/IN-: TP11.1, U2.3 (DB), U6.6 (Vin-), U14.3 (+)
/Software-Defined Instrumentation Amplifier/OUT: R43.2, TP14.1, U6.1 (Vin+), U14.8
/Software-Defined Instrumentation Amplifier/REF: R44.2, U16.6 (P1W), U16.9 (P0W)
/Software-Defined Instrumentation Amplifier/RGain+: R39.2, U14.2 (-), U15.8 (P0A)
/Software-Defined Instrumentation Amplifier/RGain-: R40.1, U14.6 (-), U15.5 (P1B), U15.6 (P1W)
/Software-Defined Instrumentation Amplifier/V_SENSOR_WITH_DC_OFFSET: R38.2, TP17.1, U14.5 (+), U14.14
/Software-Defined Instrumentation Amplifier/V_{offset+}: C44.1, R36.1, TP15.1, U13.9 (P0W)
/Software-Defined Instrumentation Amplifier/V_{offset-}: C45.1, R37.1, TP16.1, U13.6 (P1W)
/TURB_IN: D6.1 (K), J1.2, R3.1, TP3.1, U2.12 (S0A)
/TX_LED: A1.6 (GPIO4), R19.1, U8.7 (GPIO4)
/UART_RX_{0}: A1.2 (GPIO1), J6.2, U8.3 (GPIO1)
/UART_TX_{0}: A1.1 (GPIO0), J6.1, U8.2 (GPIO0)
/USB_D+: J7.3 (D+), R25.2
/USB_D-: J7.2 (D-), R26.2
/USB_VBUS: D2.1 (K), D5.2 (A), J7.1 (VBUS)
/V_{BATT}: D1.1 (K), D4.2 (A), J2.1
/V_{IN}: C1.1, C2.1, D4.1 (K), D5.1 (K), R27.1, R28.1, TP4.1, U9.5 (VIN), U9.6 (EN), U10.5 (VIN)
/~FLASH_CS: A1.10 (GPIO7), U5.1 (~CS), U8.10 (GPIO7)
/~SENSOR_EN: A1.16 (GPIO12), U2.6 (~EN), U8.33 (GPIO21)
GND: A1.3 (GND), A1.8 (GND), A1.13 (GND), A1.18 (GND), A1.23 (GND), A1.28 (GND), A1.33 (AGND), A1.38 (GND), C1.2, C2.2, C4.2, C6.2, C7.2, C8.2, C9.2, C10.2, C11.2, C12.2, C14.2, C15.2, C16.2, C17.2, C18.1, C19.1, C20.2, C21.2, C22.2, C23.2, C24.2, C25.2, C26.2, C27.2, C28.2, C29.2, C30.2, C31.2, C32.2, C33.2, C34.2, C35.2, C38.1, C39.2, C40.1, C41.1, C42.1, C43.2, C44.2, C45.2, C46.1, C47.2, C48.2, D1.2 (A), D2.2 (A), D3.2 (A), D6.2 (A), D7.2 (A), D8.2 (A), D9.2 (A), D10.2 (A), D11.1 (K), D12.1 (K), D13.1 (A1), D14.1 (K), D15.1 (K), J2.2, J3.2, J3.S1, J3.S2, J4.3, J5.3, J7.4 (GND), J7.5 (Shield), J8.2, J8.3, J8.4, J8.5, J9.2, J10.2, R1.2, R2.2, R3.2, R5.2, R7.2, R31.1, SW1.3 (B1), SW1.4 (B2), TP1.1, U2.1 (S0B), U2.2 (S2B), U2.4 (S3B), U2.5 (S1B), U2.8 (GND), U3.1 (GND), U4.1 (GND), U4.2 (GND), U4.7 (GND), U4.15 (GND), U5.4 (GND), U6.2 (V_{SS}), U7.4 (GND), U8.47 (VREG_PGND), U8.61 (GND), U9.3 (PGND), U9.9 (GND), U9.11 (PGND), U9.11_1 (PGND), U9.11_2 (PGND), U9.11_3 (PGND), U9.11_4 (PGND), U9.11_5 (PGND), U9.11_6 (PGND), U9.11_7 (PGND), U9.11_8 (PGND), U10.3 (PGND), U10.9 (GND), U10.11 (PGND), U10.11_1 (PGND), U10.11_2 (PGND), U10.11_3 (PGND), U10.11_4 (PGND), U10.11_5 (PGND), U10.11_6 (PGND), U10.11_7 (PGND), U10.11_8 (PGND), U11.5 (+), U12.3 (GND), U12.6 (LV), U13.1 (HVC/A0), U13.4 (VSS), U13.5 (P1B), U13.10 (P0B), U13.12 (A2), U13.13 (A1), U14.11 (V-), U15.1 (HVC/A0), U15.4 (VSS), U15.12 (A2), U16.4 (VSS), U16.5 (P1B), U16.12 (A2), Y1.2, Y1.4
unnamed: C19.2, R24.2, Y1.3
unnamed: C36.2, R30.2, R32.1, U11.1
unnamed: C47.1, R35.1, R45.2
unnamed: D11.2 (A), R17.2
unnamed: D12.2 (A), R18.2
unnamed: C16.1, D13.2 (A2), J8.1, L1.2
unnamed: D14.2 (A), R19.2
unnamed: D15.2 (A), R20.2
unnamed: J1.3, R2.1
unnamed: J9.1, R21.1
unnamed: R39.1, R41.1, U14.1
unnamed: R40.2, R42.1, U14.7
unnamed: C9.1, R12.2, U3.7 (Vref_{B}), U3.8 (EN)
unnamed: U4.3 (RXEN), U4.6 (DIO2)
unnamed: R15.2, U5.7 (~HOLD)
unnamed: R16.2, U5.3 (~WP)
unnamed: R26.1, U8.51 (USB_DM)
unnamed: R25.1, U8.52 (USB_DP)
unnamed: C18.2, U8.21 (XIN), Y1.1
unnamed: R24.1, U8.22 (XOUT)
unnamed: L3.2, U9.4 (L1)
unnamed: L3.1, U9.2 (L2)
unnamed: C33.1, R27.2, U9.7 (PS/SYNC), U9.8 (VINA)
unnamed: L4.2, U10.4 (L1)
unnamed: L4.1, U10.2 (L2)
unnamed: C34.1, R28.2, U10.7 (PS/SYNC), U10.8 (VINA)
unnamed: C35.1, R29.2, U11.3 (+)
unnamed: C36.1, R30.1, R31.2, U11.2 (-)
unnamed: R32.2, R33.2, R34.1, U11.6 (-)
unnamed: C37.1, U12.2 (CAP+)
unnamed: R42.2, R44.1, U14.10 (+)
unnamed: R41.2, R43.1, U14.9 (-)
unnamed: R35.2, R36.2, U14.12 (+)
unnamed: R37.2, R38.1, U14.13 (-)
unnamed: U15.7 (P1A), U15.9 (P0W), U15.10 (P0B)
unnamed: U16.7 (P1A), U16.10 (P0B)

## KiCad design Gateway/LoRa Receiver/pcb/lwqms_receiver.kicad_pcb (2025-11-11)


Board: 2 copper layers, 58.0 x 102.0 mm, 14 parts (0 on the bottom side), 21 nets.

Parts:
C1: 100n; C_0805_2012Metric_Pad1.18x1.45mm_HandSolder
D1, D2, D3, D4: LED; LED_0603_1608Metric_Pad1.05x0.95mm_HandSolder
J1, J2: Conn_01x20; PinSocket_1x20_P2.54mm_Vertical_SMD_Pin1Right
R1: 75R; R_0805_2012Metric_Pad1.20x1.40mm_HandSolder
R2, R3, R4: 165R; R_0805_2012Metric_Pad1.20x1.40mm_HandSolder
R5: 10k; R_0805_2012Metric_Pad1.20x1.40mm_HandSolder
SW1: Tactile Pushbutton; SW4_1825910-B_TEC
U1: Core1262 HF; Core1262

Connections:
+3V3: C1.1, J2.16, R5.1, U1.4 (TXEN), U1.8 (V_{DD})
/ERR_LED: J1.9, R1.1
/LoRa_BUSY: J1.12, U1.9 (BUSY)
/LoRa_CS: J1.15, U1.14 (~CS)
/LoRa_IRQ: J1.11, U1.6 (DIO1)
/LoRa_~RESET: J1.14, U1.10 (~RESET)
/RX_LED: J1.7, R2.1
/SPI_MISO_{0}: J2.1, U1.11 (MISO)
/SPI_MOSI_{0}: J2.5, U1.12 (MOSI)
/SPI_SCK_{0}: J2.4, U1.13 (SCK)
/STATUS_LED: J1.5, R4.1
/TX_LED: J1.6, R3.1
GND: C1.2, J2.3, U1.1 (GND), U1.2 (GND), U1.7 (GND), U1.15 (GND)
GND1: J2.8, SW1.3 (B1), SW1.4 (B2)
GND2: D1.1 (K), D2.1 (K), D3.1 (K), D4.1 (K), J2.18
unnamed: D1.2 (A), R1.2
unnamed: D2.2 (A), R2.2
unnamed: D3.2 (A), R3.2
unnamed: D4.2 (A), R4.2
unnamed: J2.10, R5.2, SW1.1 (A1), SW1.2 (A2)
unnamed: U1.3 (RXEN), U1.5 (DIO2)

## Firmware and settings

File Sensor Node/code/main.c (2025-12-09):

/******************************************************************************************************************** 
*   
*   @file main.c
*
*   @brief Main Driver file for the LoRa Water Quality Management System Sensor Node Firmware
*
*   @author Matthew Sharp
*   
*   @remark Penn State Harrisburg Electrical Engineering Senior Capstone Design Course, Fall 2025
*
*********************************************************************************************************************/

#include "main.h"
#include "system_config.h"
#include <stdio.h>

#define POWER_5V_COOLDOWN_DURATION_MS 10000
#define NODE_SLEEP_INTERVAL_MINS 11

#define SET_5V_RAIL_STATUS(is_enabled)                                \
    do {                                                              \
        /* Check if the EN_5V pin is already in the desired state */   \
        if (gpio_read_hal(EN_5V) != (is_enabled ? GPIO_HIGH : GPIO_LOW)) { \
            printf("Waiting for power cooldown...");                  \
            while (get_absolute_time() < power_5v_cooldown_time) {}   \
            printf("DONE\n");                                          \
                                                                  \
            printf("Setting 5V Rail %s...", (is_enabled ? "ON" : "OFF")); \
            gpio_write_hal(EN_5V, (is_enabled ? GPIO_HIGH : GPIO_LOW)); \
            printf("DONE\n");                                         \
        }                                                             \
                                                                    \
        power_5v_cooldown_time = make_timeout_time_ms(POWER_5V_COOLDOWN_DURATION_MS); \
                                                                                        \
        /* Perform an I2C Scan ???? No clue why but it fixes issues with comms on the bus */ \
        uint8_t buf[0xff]; \
        uint8_t bufidx; \
        i2c_get_available_addresses_hal(&context_i2c_1, buf, 0xff, &bufidx);                      \
    } while (0)


static uint8_t packet_id;

void print_banner(void) {
    printf("\n\n-- LoRa Water Quality Management System Sensor Node --\n");
    printf("Version 1.0, compiled %s, %s\n\n", __DATE__, __TIME__);
}

void blink_status_ok()
{
    for (int k = 0; k < 6; k++)
    {
        gpio_toggle_hal(STATUS_LED);
        sleep_ms(250);
    }
}

lora_setup_t lora_phy_setup = {
    .hw = &context_radio_0,
    .mod_setting = &prototyping_mod_params,
    .operation_timeout_ms = 10000,
    .pa_setting = &sx1262_22dBm_pa_params,
    .pkt_setting = &prototyping_pkt_params,
    .ramp_time = SX126X_RAMP_200_US,
    .rx_interrupt_setting = &prototyping_irq_masks,
    .tx_interrupt_setting = &prototyping_irq_masks,
    .txPower = 22,
    .node_config = &sys_configuration,
};

sensor_acquisition_settings_t sen_acq_settings = {
    .analog_characteristic_turb = {
        .dc_offset_pos = 0,
        .dc_offset_neg = 3,             // Shift ~4.1V input to 1.1V
        .output_reference_offset = 0,
        .gain = 1.8                     // 1.98V max input. 
    },
    .analog_characteristic_temp = {
        .dc_offset_pos = 0,
        .dc_offset_neg = 0,
        .output_reference_offset = 0,
        .gain = 2.2                       
    },
    .analog_characteristic_pH = {   // Target pH region: 5-10 -> Vlo = 2.2V, Vhi = 2.9V, BUT output must always be positive. pH 0 = 1.5V --> No greater DC- offset than this.
        .dc_offset_pos = 0,
        .dc_offset_neg = 1.4,       // Input range = 0.8V --> 1.5V. Maximum allowable gain = ~1.5
        .output_reference_offset = 0,
        .gain = 1.3,
    }
};

union sdia_cal_memsaver_u {
    sdia_potentiometer_full_calibration_t cal;
    uint8_t buf[sizeof(sdia_potentiometer_full_calibration_t)];
};

void sdia_get_and_write_calibration() {
    union sdia_cal_memsaver_u cal;

    sdia_calibrate(&context_sdia_0, &(cal.cal));

    printf("Erasing Old Calibration Data...");
    mxl23l3233f_erase_32kb_block(&context_flash_0, FLASH_ADDR_SDIA_CAL_DATA_32K_BLOCK);
    printf("DONE\n");

    printf("Writing Calibration Data to Memory...");
    mxl23l3233f_write_data(&context_flash_0, cal.buf, sizeof(sdia_potentiometer_full_calibration_t), FLASH_ADDR_SDIA_CAL_DATA_32K_BLOCK * FLASH_BLOCK_32KB_SIZE);
    printf("DONE\n");
}

void startup_menu() {
    char * menu_options = 
    "---- Startup Menu ----\n"
    "Please listen closely as our menu options have changed.\n\n"
    "-------------------------------------------------------\n\n"
    "Option Letter (case-insensitive) | Action\n"
    "-> c | Clear the current configuration data\n"
    "-> s | Set (overwrites existing) configuration data\n"
    "-> p | Print the current configuration data\n"
    "-> e | Enables the 5V rail (10 second cooldown until rail can be disabled.)\n"
    "-> d | Disables the 5V rail (10 second cooldown until rail can be enabled.)\n"
    "-> i | Performs an I2C scan for devices\n"
    "-> t | Transmit a packet\n"
    "-> a | Configure the software-defined instrumentation amplifier\n"
    "-> m | Take a measurement using the ADC.\n"
    "-> l | Clear the current software-defined instrumentation amplifier calibration data\n"
    "-> f | Calibrate the Software-Defined Instrumentation Amplifier.\n"
    "-> w | Print the current Software-Defined Instrumentation Amplifier Calibration Data to the Console.\n"
    "-> q | Acquire sensor telemetry autonomously\n"
    "-> r | Reboot the device - updates device settings with any changes made here.\n";
    
    absolute_time_t power_5v_cooldown_time = get_absolute_time();

    sdia_wiper_settings_t wiper_setting = { // Initialize all wipers at the midpoint.
        .dc_neg_wiper_setting = 0x80,
        .dc_pos_wiper_setting = 0x80,
        .gain_wiper_a_setting = 0x80,
        .gain_wiper_b_setting = 0x80,
        .ref_out_wiper_a_setting = 0x80,
        .ref_out_wiper_b_setting = 0x80
    };

    while (1) {

        printf(menu_options);
        printf("\n\n\n----> ");
    
        char response_buf[2];
    
        get_user_input_hal(response_buf, 2);

        printf("\n\n");
    
        char selection = response_buf[0] |= (1 << 5);   // Force lowercase
    
        switch (selection) {
            case 'c':
                // Overwrite the space allocated for the configuration data with 0xff
                printf("Clearing the config...");
                mxl23l3233f_erase_sector(&context_flash_0, FLASH_ADDR_CONFIG);
                printf("DONE\n");
                break;
            case 's':
                node_config_t new_config = get_setup_data();
                printf("Writing new config...");
                mxl23l3233f_erase_sector(&context_flash_0, FLASH_ADDR_CONFIG);
                write_system_config_data(&context_flash_0, &new_config);
                printf("DONE\n");
                break;
            case 'p':
                node_config_t cfg_buf;
                read_system_config_data(&context_flash_0, &cfg_buf);
                print_node_configuration(&cfg_buf);
                break;
            case 'e':
            case 'd':
                SET_5V_RAIL_STATUS(selection == 'e');
                if (selection == 'd') {
                    // Reset the potentiometer positions as they will re-initialize to the mid-point upon 5V power cycle.
                    wiper_setting.dc_neg_wiper_setting = 0x80;
                    wiper_setting.dc_pos_wiper_setting = 0x80;
                    wiper_setting.gain_wiper_a_setting = 0x80;
                    wiper_setting.gain_wiper_b_setting = 0x80;
                    wiper_setting.ref_out_wiper_a_setting = 0x80;
                    wiper_setting.ref_out_wiper_b_setting = 0x80;
                }
                break;
            case 'i':
                uint8_t i2c_address_buf[0xff];
                uint8_t qty_available_addresses = 0;
                memset(i2c_address_buf, 0x00, 0xff);

                printf("Scanning I2C Bus...");
                i2c_get_available_addresses_hal(&context_i2c_1, i2c_address_buf, 0xff, &qty_available_addresses);
                printf("DONE\n");
                
                printf("Available I2C Addresses:\t");
                for (uint8_t * ptr = i2c_address_buf; (ptr - i2c_address_buf) < qty_available_addresses; ptr++) {
                    printf("%02x\t", *ptr);
                }
                printf("\n");
                break;
            case 'r':
                // Reboot the device. Force this option instead of exit so changes always get saved.
                SET_5V_RAIL_STATUS(false);
                sleep_ms(POWER_5V_COOLDOWN_DURATION_MS);    // No smoke please!
                reboot();
                break;
            case 't':
                lwqms_pkt_t packet = get_custom_packet();
                lora_pkt_t tx_pkt;                
                tx_pkt.len = LWQMS_PKT_LEN_MAX;
                lwqms_pkt_encode(&packet, tx_pkt.buf, tx_pkt.len);
                printf("Sending packet...\n\n");
                rdt3_0_transmit(&tx_pkt, sizeof(lora_pkt_t), &lora_phy_setup);
                printf("\n\n-- Transmit Operation Complete --\n");
                break;
            case 'a':
                wiper_setting = get_wiper_setting();
                SET_5V_RAIL_STATUS(true);
                printf("Writing Configuration...");
                sdia_apply_wiper_setting(&context_sdia_0, &wiper_setting);
                printf("DONE\n\n");
                break;
            case 'm':
                uint16_t input_selection;

                do {
                    printf("Poll from which input? [0-3]: \t");
                    char inputBuf[2];
                    get_user_input_hal(inputBuf, 2);
                    input_selection = string_to_uint16_t(inputBuf, 10);
                    if (input_selection > 3) {
                        printf("Bad Input!\n");
                    }
                } while (input_selection > 3);

                printf("\tOK\n\n");

                SET_5V_RAIL_STATUS(true);
                printf("Setting the input...");
                tmux1309_set_output(&context_mux_0, input_selection);
                printf("DONE\n");
                printf("Setting up ADC...");
                mcp3425_init(&context_adc_0, MCP3425_SPS_15_16BITS, MCP3425_PGA_1, false);
                printf("DONE\n");
                printf("Polling ADC...");
                double voltage_raw = 0;
                sdia_read_raw(&context_sdia_0, &voltage_raw);
                printf("DONE\n");
                printf("ADC Voltage: %f V\n", voltage_raw);
                sdia_analog_characteristic_t analog_behavior;
                sdia_convert_wiper_setting(&context_sdia_0, &sdia_calibration, &wiper_setting, &analog_behavior);
                double processed_voltage = sdia_process_raw_voltage(voltage_raw, &analog_behavior);
                printf("\n\nCalculated Input Voltage (based on last used software-defined instrumentation amplifier configuration): \x1b[1m%f V\x1b[0m", processed_voltage);
                break;
            case 'l':
                // Overwrite the space allocated for the configuration data with 0xff
                printf("Clearing the calibration data...");
                mxl23l3233f_erase_32kb_block(&context_flash_0, FLASH_ADDR_SDIA_CAL_DATA_32K_BLOCK);
                printf("DONE\n");
                break;
            case 'f':
                SET_5V_RAIL_STATUS(true);
                sdia_get_and_write_calibration();
                break;
            case 'w':
                sdia_print_calibration(&sdia_calibration);
                break;
            case 'q':
                SET_5V_RAIL_STATUS(true);
                sensor_telemetry_t sensor_data;
                sensors_acquire_data(&context_sdia_0, &sdia_calibration, &sen_acq_settings, &sensor_data);
                printf("Telemetry: Turbidity = %f NTU, Temperature = %f C, pH = %f\n\n", sensor_data.turbidity_NTU, sensor_data.temperature_C, sensor_data.pH);
            default:
                printf("Invalid Option: %c", selection);
                break;              
        }

        printf("\n\n\n");
    }
}

void system_setup() {
    watchdog_init_hal(WATCHDOG_MAX_DELAY_MS);   // Let the dog out

    init_usb_console_hal();

    //wait_for_usb_console_connection_hal();

    print_banner();

    lwqms_post_err_codes_t post_result = power_on_self_test();

    uint32_t novo_contents[MCU_POWMAN_NOVO_ELEMENTS];
    size_t novo_contents_len;

    if (check_for_power_saving_mode_boot(novo_contents, MCU_POWMAN_NOVO_ELEMENTS, &novo_contents_len)) {
        printf("Dormant state boot detected!\n");
        packet_id = novo_contents[0];
        for (int status = 1; status <= 0; --status) {
            for (uint8_t k = ERR_LED; k <= STATUS_LED; --k) {
                gpio_write_hal(k, status);
                sleep_ms(250);
            }
        }
    } else {
        printf("Power cycle boot detected!\n");
        packet_id = 1;
    }

    packet_id = check_for_power_saving_mode_boot(novo_contents, MCU_POWMAN_NOVO_ELEMENTS, &novo_contents_len) ? novo_contents[0] : 1;

    switch (post_result) {
        case POST_BYPASS:
            printf("POST Bypassed due to previous pass before dormant state.\n\n");
            blink_status_ok();
            break;
        case POST_OK:
            printf("POST Successful!\n\n");
            blink_status_ok();
            break;
        case POST_ERR_NO_CONFIG_EXISTS:
            err_raise(ERR_POST_FAIL, ERR_SEV_NONFATAL, "Could not find configuration data!", "power_on_self_test");
            gpio_write_hal(ERR_LED, GPIO_HIGH);

            // Get a new config from the user
            node_config_t new_config = get_setup_data();
            if (write_system_config_data(&context_flash_0, &new_config) == 0) {
                printf("System restarting with updated configuration...\n\n\n");
                sleep_ms(250);
                reboot();
            }
            while (1);
        case POST_ERR_NO_SDIA_CALIBRATION:
            err_raise(ERR_POST_FAIL, ERR_SEV_NONFATAL, "Could not find SDIA calibration data!", "power_on_self_test");
            gpio_write_hal(ERR_LED, GPIO_HIGH);

            // Get a new calibration
            sdia_get_and_write_calibration();
            printf("Waiting for powe cooldown time...");
            gpio_write_hal(EN_5V, GPIO_LOW);
            sleep_ms(POWER_5V_COOLDOWN_DURATION_MS);
            printf("DONE\n");
            printf("Rebooting...");
            sleep_ms(250);
            reboot();
        default:
            err_raise(ERR_POST_FAIL, ERR_SEV_FATAL, "Failed to POST! Error Code = %d", "power_on_self_test");
            while (1);
    }

    absolute_time_t startup_time = make_timeout_time_ms(3000);

    if (is_usb_console_connected_hal()) {
        printf("To interrupt normal startup and enter the startup menu, press 'm'...\n");
    
        while (get_absolute_time() < startup_time) {
            if ((usb_console_getchar_timeout_us_hal(1000) | (1 << 5)) == 'm') { // Force user input to be lowercase
                watchdog_deinit_hal();  // back to the kennel
                startup_menu();
            }
        }
    }
}

static rp2350_power_mgmt_setting_t mcu_all_on = {
    .domains = {
        .swcore_enable = true,
        .xip_enable = true,
        .sram0_enable = true,
        .sram1_enable = true
    }
};

int main()
{
    system_setup();

    // FSM
    lwqms_fsm_t state = LWQMS_FSM_STATE_SAMPLE;

    sensor_telemetry_t sensor_data;

    while(1) {
        /*
        printf("Advance FSM? (y) Next State = 0x%08x\n", state);
        while ((usb_console_getchar_hal() | (1 << 5)) != 'y');
        printf("advancing!\n");
        */
        switch (state) {
            case LWQMS_FSM_STATE_SAMPLE:
                /**
                 * In the SAMPLE state, the sensor node obtains analog voltage readings from each sensor, converts them to their relevant measurements,
                 * and saves them to RAM. The next state is the TRANSMIT state.
                 */
                watchdog_feed_hal();    // Feed the dog - beware of bites!
                sensors_acquire_data(&context_sdia_0, &sdia_calibration, &sen_acq_settings, &sensor_data);
                printf("Telemetry: Turbidity = %f NTU, Temperature = %f C, pH = %f\n\n", sensor_data.turbidity_NTU, sensor_data.temperature_C, sensor_data.pH);
                gpio_write_hal(EN_5V, GPIO_LOW);
                state = LWQMS_FSM_STATE_TRANSMIT;
                break;
            case LWQMS_FSM_STATE_TRANSMIT:
                /**
                 * In the TRANSMIT state, the sensor node converts the telemetry data to a transmittable packet, and uses the LoRa modulator to send the data
                 * to the gateway. Having completed its duty, the next state is the DORMANT state.
                 */
                lwqms_pkt_t telem_packet = {
                    .src_id = sys_configuration.ID,
                    .dest_id = sys_configuration.gateway_ID,
                    .packet_type = LWQMS_PACKET_TYPE_TELEMETRY,
                    .pkt_id = packet_id,
                    .payload = {    // Payload is a union type that spans both a char[12] and 3 x floats (4 bytes)
                        .telemetry = {
                            .turbidity_measurement = sensor_data.turbidity_NTU,
                            .temperature_measurement = sensor_data.temperature_C,
                            .pH_measurement = sensor_data.pH
                        }
                    }
                };

                lora_pkt_t tx_pkt = {
                    .len = LWQMS_PKT_LEN_MAX
                };

                lwqms_pkt_encode(&telem_packet, tx_pkt.buf, tx_pkt.len);

                printf("Transmitting packet...\n\n");
                rdt3_0_transmit(&tx_pkt, sizeof(lora_pkt_t), &lora_phy_setup);  // Feeding the dog built into this method
                printf("\n\n-- Transmit Operation Complete --\n");
                packet_id++;
                state = LWQMS_FSM_STATE_DORMANT;
                break;
            case LWQMS_FSM_STATE_DORMANT:
                /**
                 * In the DORMANT state, the sensor node deactivates any 5V peripherals (although this function is technically performed 
                 * after sensor acquisition is complete), puts the LoRa modulator in its deep sleep mode, and enters its MCU's lowest power
                 * state. After waking up, the MCU will have a cold reset, making the next state the SAMPLE state.
                 */
                watchdog_feed_hal();    // Feed the dog - beware of bites!
                uint32_t novo_mem_contents[1] = {packet_id};
                enter_power_saving_mode(&power_mgmt_dormant_state, &context_radio_0, 60 * 1000 * NODE_SLEEP_INTERVAL_MINS, novo_mem_contents, 1);
                state = LWQMS_FSM_STATE_RESET;
                break;
            default:
                state = LWQMS_FSM_STATE_SAMPLE;
                break;
        }
    }
}



/* --- EOF ------------------------------------------------------------------ */

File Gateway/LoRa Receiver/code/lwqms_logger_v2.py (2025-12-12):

#!/usr/bin/env python3

import serial
import csv
import os
import re
import time
import random
from datetime import datetime

# ============================
# User Configuration
# ============================
PORT = "/dev/ttyACM0"
BAUDRATE = 115200
TIMEOUT = 1.0          # Seconds to wait for serial input before looping again

PAYLOAD_FILE = "payloads.csv"
MESSAGE_FILE = "messages.csv"

# ============================
# Node 2 Simulation Settings
# ============================

NODE2_ID = 2
NODE2_INTERVAL_SECONDS = 15 * 60  # 15 minutes

# Base values
NODE2_BASE_PH = 7.83
NODE2_BASE_TEMP = 22.75
NODE2_BASE_TURB = 0.15

# Physical/global ranges
NODE2_PH_MIN, NODE2_PH_MAX = 6.5, 8.5
NODE2_TEMP_MIN, NODE2_TEMP_MAX = 0.0, 35.0
NODE2_TURB_MIN, NODE2_TURB_MAX = 0.0, 1.0

# Current state so values drift smoothly instead of jumping randomly
NODE2_STATE = {
    "ph": NODE2_BASE_PH,
    "temp": NODE2_BASE_TEMP,
    "turb": NODE2_BASE_TURB,
}

# ============================
# Utility Functions
# ============================

def ensure_csv_header(filename, headers):
    """Ensure the CSV file exists and has the proper header."""
    if not os.path.exists(filename):
        with open(filename, mode='w', newline='') as f:
            writer = csv.writer(f)
            writer.writerow(headers)

def append_to_csv(filename, row):
    """Append a single row to the CSV file, safely."""
    with open(filename, mode='a', newline='') as f:
        writer = csv.writer(f)
        writer.writerow(row)

def parse_payload(line):
    """
    Parse LWQMS_PLD packets like:
    LWQMS_PLD[1]: 0.000450 23.000000 7.000000 END
    """
    match = re.match(
        r"LWQMS_PLD\[(\d+)\]:\s*([\d\.\-Ee]+)\s+([\d\.\-Ee]+)\s+([\d\.\-Ee]+)\s+END",
        line,
    )
    if match:
        node_id = int(match.group(1))
        turbidity = float(match.group(2))
        temperature = float(match.group(3))
        ph = float(match.group(4))
        timestamp = datetime.now().isoformat()
        # IMPORTANT: order matches your dashboard expectation:
        # [Time, Sensor Node ID, Turbidity (NTU), Temperature (C), pH]
        return [timestamp, node_id, turbidity, temperature, ph]
    return None

def parse_message(line):
    """
    Parse LWQMS_MSG packets like:
    LWQMS_MSG[1]: Transmitter Ready END
    """
    match = re.match(r"LWQMS_MSG\[(\d+)\]:\s*(.*?)\s*END", line)
    if match:
        node_id = int(match.group(1))
        message = match.group(2)
        timestamp = datetime.now().isoformat()
        return [timestamp, node_id, message]
    return None

def _bounded_random_step(current, base, frac_of_base_step, hard_min, hard_max):
    # Make a small random step around 'current' with limits based on base and hard bounds.
    max_step = base * frac_of_base_step
    delta = random.uniform(-max_step, max_step)
    new_val = current + delta

    # ±10% band around base
    band_min = base * 0.9
    band_max = base * 1.1

    # Respect both the band and the physical limits
    lower = max(hard_min, band_min)
    upper = min(hard_max, band_max)

    return max(lower, min(upper, new_val))

def generate_node2_payload():
    # Generate a single fake payload row for Node 2.
    # Returns [timestamp_iso, node_id, turbidity, temperature, ph]

    # Use and update global state so values drift smoothly
    NODE2_STATE["ph"] = _bounded_random_step(
        NODE2_STATE["ph"], NODE2_BASE_PH, 0.02, NODE2_PH_MIN, NODE2_PH_MAX
    )
    NODE2_STATE["temp"] = _bounded_random_step(
        NODE2_STATE["temp"], NODE2_BASE_TEMP, 0.02, NODE2_TEMP_MIN, NODE2_TEMP_MAX
    )
    NODE2_STATE["turb"] = _bounded_random_step(
        NODE2_STATE["turb"], NODE2_BASE_TURB, 0.05, NODE2_TURB_MIN, NODE2_TURB_MAX
    )

    timestamp = datetime.now().isoformat()
    turb = NODE2_STATE["turb"]
    temp = NODE2_STATE["temp"]
    ph = NODE2_STATE["ph"]
    
    turb_str = f"{turb:.6f}"
    temp_str = f"{temp:.6f}"
    ph_str   = f"{ph:.6f}"

    return [timestamp, NODE2_ID, turb_str, temp_str, ph_str]

# ============================
# Main Loop
# ============================

def main():
    # Ensure CSV headers
    ensure_csv_header(
        PAYLOAD_FILE,
        ["Time", "Sensor Node ID", "Turbidity (NTU)", "Temperature (C)", "pH"],
    )
    ensure_csv_header(MESSAGE_FILE, ["Time", "Sensor Node ID", "Message"])

    print(f"Listening on {PORT} at {BAUDRATE} baud...")

    # Initial Node 2 sample at startup
    startup_row = generate_node2_payload()
    append_to_csv(PAYLOAD_FILE, startup_row)
    print(f"[SIM NODE 2 STARTUP] {startup_row}")
    
    # Track when we last generated a Node 2 sample
    last_node2_time = time.time()

    try:
        with serial.Serial(PORT, BAUDRATE, timeout=TIMEOUT) as ser:
            while True:
                try:
                    line = ser.readline().decode(errors="ignore").strip()

                    # 1) Handle real packets from the receiver (Node 1)
                    if line:
                        if "LWQMS_PLD" in line:
                            payload_data = parse_payload(line)
                            if payload_data:
                                append_to_csv(PAYLOAD_FILE, payload_data)
                                print(f"[PAYLOAD] {payload_data}")

                        elif "LWQMS_MSG" in line:
                            message_data = parse_message(line)
                            if message_data:
                                append_to_csv(MESSAGE_FILE, message_data)
                                print(f"[MESSAGE] {message_data}")

                    # 2) Periodically inject Node 2 simulated data
                    now = time.time()
                    if now - last_node2_time >= NODE2_INTERVAL_SECONDS:
                        node2_row = generate_node2_payload()
                        append_to_csv(PAYLOAD_FILE, node2_row)
                        print(f"[SIM NODE 2] {node2_row}")
                        last_node2_time = now

                except Exception as e:
                    print(f"Error inside main loop: {e}")

    except serial.SerialException as e:
        print(f"Serial port error: {e}")
    except KeyboardInterrupt:
        print("\nStopped by user.")

if __name__ == "__main__":
    main()

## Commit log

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2025-05-03 Add preliminary sensor node BOM and corresponding datasheets
    [BOM.xlsx]
2025-06-21 Folder restructuring. Add Development log for Sensor Node.
    [BOM.xlsx]
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2025-08-01 Finalized a working driver for the sx1262 LoRa module using the Raspberry Pi Pico 2. Add a prototype sx1262 schematic and testbench drawing.
    [BGS12WN6E6327XTSA1.step, LoRa Testbench.kicad_pcb, LoRa Testbench.kicad_sch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]
2025-08-04 Add preliminary layout designs for the RP2350 and Buck-Boost Regulator DC Power Supply. Added datasheets and updated the development log.
    [ABM8-272-T3_ABR.step, LoRa Water Quality Management System Sensor Node.kicad_pcb, SOIC_208MIL_WIN.step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]
2025-08-07 Add finalized schematics for sx1262 and SPI flash.
    [SC-70-6_PSM.step, SX1262MB1CAS_915MHz_e428v03a_BOM.xlsx, TPIC2810DR.step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]
2025-08-11 Finalize first draft schematic capture, assign all footprints, and begin preliminary PCB layout.
    [31-5431-10RFX.stp, BAT54C.step, LoRa Water Quality Management System Sensor Node.kicad_pcb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]
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2025-08-12 Add power supply PCB layout
    [LoRa Water Quality Management System Sensor Node.kicad_pcb, bom.csv, designators.csv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]
2025-08-12 Begin RP2350 PCB layout
    [LoRa Water Quality Management System Sensor Node.kicad_pcb]
2025-08-13 finalize RP2350 layout (mostly)
    [LoRa Water Quality Management System Sensor Node.kicad_pcb, rp2350_layout.kicad_sch]
2025-08-13 Finalize most routing, preliminary RF design (fencing/stitching vias) RF transmission line trace, etc.
    [LoRa Water Quality Management System Sensor Node.kicad_pcb]
2025-08-14 Improved RF routing, import all 3D models.
    [Core126X.step, DYY0016A.stp, LoRa Water Quality Management System Sensor Node.kicad_pcb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]
2025-08-14 Improve RF routing and noise immunity. Add copper pours on top and bottom layer with ample stitching vias. Add TVS diodes for ESD protection and testpoints for hardware debugging.
    [LoRa Water Quality Management System Sensor Node.kicad_pcb, rp2350_layout.kicad_sch]
2025-08-15 Resolve JLCPCB DFM issues
    [LoRa Water Quality Management System Sensor Node.kicad_pcb, bom.csv, designators.csv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]
2025-08-15 Add indicator LEDs, PCB cleanup, and preliminary BOM, assuming R/C can be sourced from equipment room.
    [LoRa Water Quality Management System Sensor Node.kicad_pcb, bom.csv, designators.csv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]
2025-08-18 Change connectors to reduce component cost, identified R/C components for purchase.
    [LoRa Water Quality Management System Sensor Node.kicad_pcb]
2025-08-18 PCB design cleanup, update footprints,3D models. Denote board as variant 'A', using the quad op-amp design.
    [LoRa Water Quality Management System Sensor Node.kicad_pcb, OQ0232510000G.stp, OQ0332510000G.stp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]
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2025-08-19 Add correct BOM (sorry)
    [BOM.xlsx]
2025-08-20 Add preliminary changes based on feedback from Zach Martin.
    [LQH3NPZ2R2MMEL.step, LoRa Water Quality Management System Sensor Node.kicad_pcb, TPS63000DRCR.step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]
2025-08-21 Update all R/C components to 0805, complete layout of updated buck-boost converter. Add TVS diodes for ESD protection on vulnerable signals, add reference designators, and fix clearance issues.
    [LoRa Water Quality Management System Sensor Node.kicad_pcb, bom.csv, designators.csv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]
2025-08-21 Board Cleanup
    Cleanup traces, fix minor layout issues. Create updated BOM
    [Annotated BOM.xlsx, LoRa Water Quality Management System Sensor Node.kicad_pcb, bom.csv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]
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2025-08-28 Minor modifications to PCB design, add prototyping design for signal conditioner. Finalize documentation for the first draft PCB.
    [LoRa Water Quality Management System Sensor Node.kicad_pcb, MCP4651T-503E_ST.step, bom.csv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]
2025-09-03 Finalize changed to prototype signal conditioner PCB for manufacture.
    [signal_conditioner-B_Cu.gbr, signal_conditioner-B_Mask.gbr, signal_conditioner-B_Silkscreen.gbr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]
2025-09-10 Add files via upload
    Data set that will be used to train NN
    [brisbane_water_quality_dataset.csv]
2025-09-13 Add test pcb designs and simulations for signal conditioner, drivers for digital potentiometer, analog mux, and spi flash.
    [14TSSOPBreakout-B_Cu.gbr, 14TSSOPBreakout-B_Mask.gbr, 14TSSOPBreakout-B_Paste.gbr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]
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2025-10-08 Add driver for ADC and other breakout board designs.
    [buckboost-B_Cu.gbr, buckboost-B_Mask.gbr, buckboost-B_Paste.gbr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]
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2025-11-08 Add dedicated receiver code, begin developing code for software-defined instrumentation amplifier.
    [SOFTWARE_DEFINED_INSTRUMENTATION_AMPLIFIER.DSN, lwqms_receiver.kicad_pcb, messages.csv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]
2025-11-11 Add receiver gerber files and updated testing CSVs.
    [lwqms_receiver-B_Cu.gbr, lwqms_receiver-B_Mask.gbr, lwqms_receiver-B_Paste.gbr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]
2025-11-18 Finalize working software-defined instrumentation amplifier driver code and signal acquisition, begin prototyping sensor data conversion methods. Add hardware changes needed for expected operation of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
    [LoRa Water Quality Management System Sensor Node.kicad_pcb, SOFTWARE_DEFINED_INSTRUMENTATION_AMPLIFIER.DSN, phsensorboard_alt.kicad_sch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]
2025-12-03 Add finalized firmware - implemented power savings mode and implemented complete FSM.
    [LoRa Water Quality Management System Sensor Node.kicad_pcb, PH_SENSOR_PREAMP.DSN, buckboost.kicad_pcb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]
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2025-12-12 Add final changes to schematics for documentation purposes
    [LoRa Water Quality Management System Sensor Node.kicad_pcb, lmv324_breakout.kicad_sch]
2025-12-12 Complete repository restructuring and organization for submission with final report.
    [14TSSOPBreakout-B_Cu.gbr, 14TSSOPBreakout-B_Mask.gbr, 14TSSOPBreakout-B_Paste.gbr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]
2025-12-13 Add files via upload
    MATLAB files for data cleaning, data formatting, and NN training
    [datasetcapstone.csv]
2025-12-15 Organize neural net code, minor updates to files
    [datasetcapstone.csv]
